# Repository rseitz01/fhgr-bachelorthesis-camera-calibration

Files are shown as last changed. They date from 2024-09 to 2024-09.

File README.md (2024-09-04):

# fhgr-bachelorthesis-camera-calibration

## Ordnerstruktur

- [`doc`](doc) Allgemeine Dokumentationen
- [`ledrunner`](ledrunner) Alles bezüglich STM32 (HW, SW, ...)
- [`src`](src) Source Codes (PC)

Die Veröffentlichung der Bachelorarbeit auf GitHub wurde durch den Dozenten und den Auftraggeber nach der Präsentation erlaubt.

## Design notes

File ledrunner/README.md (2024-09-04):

# ledrunner

## Ordnerstruktur

- [`housing-ledrunner`](housing-ledrunner) Komplettes Gehäuse für die Hardware
- [`hw-ledrunner`](hw-ledrunner) Schema + PCB der Hardware
- [`sw-camera-calibration`](sw-camera-calibration) STM32 Software (Prototyp der Kalibration)
- [`sw-ledrunner`](sw-ledrunner) STM32 Software zur Hardware

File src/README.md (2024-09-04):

# src

## Ordnerstruktur

- [`camera-control`](camera-control) Steuerung von ueye Kameras (Windows & Linux) + Ledrunner (nur Linux)
- [`eval-dynamic`](eval-dynamic) Auswertung der Videos (automatische Feld Erkennung)
- [`eval-static`](eval-static) Auswertung der Videos (Prototyp, manuelle Feld Einzeichnung)
- [`timer-estimator`](timer-estimator) Timer Estimation (Prototyp für [hier](../ledrunner/sw-ledrunner/Core/Src/timer_estimator.c))

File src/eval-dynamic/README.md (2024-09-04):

# eval-dynamic

## Beschreibung der Skripte

- [`calibrated.py`](calibrated.py) Visualisierung der kalibrierten Frequenzen
- [`calibrated_pwm.py`](calibrated_pwm.py) Formatierungshilfe für LaTeX der gemessenen PWM Frequenzen
- [`config.py`](config.py) Diverse allgemeine Konfigurations-Optionen für die Analyse + Auswertung
- [`debug.py`](debug.py) Debug-Optionen
- [`dynamic-conceptual.py`](dynamic-coneptual.py) Versuch, alles bis auf die automatische Positionserkennung zum Laufen zu bringen *(nicht mehr verwendet)*
- [`dynamic.py`](dynamic.py) Analyse-Programm
- [`image_sequence.py`](image_sequence.py) Speichern von Bildern und Positionserkennung des Gerätes
- [`plotter.py`](plotter.py) Auswertungs-Programm
- [`plotter_bad.py`](plotter_bad.py) Auswertungs-Programm; Erste Version *(nicht mehr verwendet)*
- [`position_sequence.py`](position_sequence.py) Speichern von Positionen und PWM-Kalibration

Wird `dynamic.py` auf ein Video angewendet, werden Messwerte in `measurements` gespeichert. 
Nach und nach werden gleichzeitig in `measurements/plotcommands.txt` äquivalente Python-Funktionsaufrufe
angefügt, welche in `plotter.py` verwendet werden können.

Wird `dynamic.py` nur auf einer Videodatei angewendet, wird bei Beenden direkt geplottet.
Es ist auch möglich, mehrere Videodateien zugleich abzuarbeiten.
Dann werden jedoch weniger Informationen ausgegeben und nicht geplottet.
(Die `measurements/plotcommands` werden in jedem Fall erstellt.)

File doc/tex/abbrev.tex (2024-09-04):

\begin{centering}
\begin{tabular}{ | ll | }
    \hline
    USB & Universal Serial Bus \\
    LED & Leuchtdiode \\
    PC & Personal Computer \\
    PWM & Pulsweitenmodulation \\
    PCB & Printed Circuit Board (Leiterplatine) \\
    QR-Code & quick-response code \\
    FPS & Bilder pro Sekunde (Frequenz) \\
    LSB & Least Significant Bit (Niederwertigstes Bit) \\
    \hline
\end{tabular}
\captionof{table}{Abkürzungsverzeichnis}
\label{table:Abkürzungsverzeichnis}
\end{centering}

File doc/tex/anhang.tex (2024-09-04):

%- Auflistung der Dokumente im Anhang
{
\let\ttdefault\rmdefault
\begin{longtable}[l]{ @{} >{\RaggedRight\hspace{0pt}} lp{.96\linewidth} @{} }
    \refstepcounter{enumi}\hypertarget{app:this}{\theenumi}.
    %& Bachelorarbeit
    & Kurzbeschreibung: Bachelorarbeit \LaTeX-Source Code
    \\& Ordner: \verb|doc/tex|
    \\& Datum und Zeit: 09.08.2024 09:40
    \vspace{0.5em}
    \\\refstepcounter{enumi}\hypertarget{app:expose}{\theenumi}.
    %& Exposé
    & Kurzbeschreibung: Originale Exposé Datei, PDFs (Exposé und Auftragsblatt)
    \\& Ordner: \verb|doc/expose|
    \\& Datum und Zeit: 09.08.2024 04:25
    \vspace{0.5em}
    \\\refstepcounter{enumi}\hypertarget{app:bilder}{\theenumi}.
    %& Bilder
    & Kurzbeschreibung: Diverse Bilder die verwendet sind in diesem Dokument
    \\& Ordner: \verb|doc/images|
    \\& Datum und Zeit: 09.08.2024 04:20
    \vspace{0.5em}
    \\\refstepcounter{enumi}\hypertarget{app:housing-ledrunner}{\theenumi}.
    %& Gehäuse der Hardware
    & Kurzbeschreibung: Gehäuse der Hardware
    \\& Ordner: \verb|ledrunner/housing-ledrunner|
    \\& Datum und Zeit: 08.08.2024 22:34
    \\& Programm: Fusion 360
    \vspace{0.5em}
    \\\refstepcounter{enumi}\hypertarget{app:hw-ledrunner}{\theenumi}.
    %& Gehäuse der Hardware
    & Kurzbeschreibung: Schema und PCB der Hardware
    \\& Ordner: \verb|ledrunner/hw-ledrunner|
    \\& Datum und Zeit: 09.08.2024 04:51
    \\& Entwicklungsumgebung: KiCad
    \vspace{0.5em}
    \\\refstepcounter{enumi}\hypertarget{app:sw-ledrunner}{\theenumi}.
    %& Gehäuse der Hardware
    & Kurzbeschreibung: STM32 Software der Hardware
    \\& Ordner: \verb|ledrunner/sw-ledrunner|
    \\& Datum und Zeit: 06.08.2024 12:44
    \\& Entwicklungsumgebung: STM32CubeIDE
    \vspace{0.5em}
    \\\refstepcounter{enumi}\hypertarget{app:sw-camera-calibration}{\theenumi}.
    %& Gehäuse der Hardware
    & Kurzbeschreibung: STM32 Software der Machbarkeitsanalyse für die Kalibration
    \\& Ordner: \verb|ledrunner/sw-camera-calibration|
    \\& Datum und Zeit: 06.08.2024 12:44
    \\& Entwicklungsumgebung: STM32CubeIDE
    \vspace{0.5em}
    \\\refstepcounter{enumi}\hypertarget{app:camera-calibration}{\theenumi}.
    %& Gehäuse der Hardware
    & Kurzbeschreibung: Auswertesoftware der Machbarkeitsanalyse für die Kalibration
    \\& Ordner: \verb|src/camera-calibration|
    \\& Datum und Zeit: 08.08.2024 12:05
    \\& Programmiersprache: C/C++
    \vspace{0.5em}
    \\\refstepcounter{enumi}\hypertarget{app:camera-control}{\theenumi}.
    %& Gehäuse der Hardware
    & Kurzbeschreibung: Beispielsoftware zur Steuerung einer Kamera und des Kalibrationsgerätes
    \\& Ordner: \verb|src/camera-control|
    \\& Datum und Zeit: 08.08.2024 12:05
    \\& Programmiersprache: C/C++
    \vspace{0.5em}
    \\\refstepcounter{enumi}\hypertarget{app:eval-dynamic}{\theenumi}.
    %& Gehäuse der Hardware
    & Kurzbeschreibung: Evaluationssoftware der gefilmten Videos (automatische Positionsdetektion)
    \\& Ordner: \verb|src/eval-dynamic|
    \\& Datum und Zeit: 09.08.2024 05:59
    \\& Programmiersprache: Python
    \vspace{0.5em}
    \\\refstepcounter{enumi}\hypertarget{app:eval-static}{\theenumi}.
    %& Gehäuse der Hardware
    & Kurzbeschreibung: Evaluationssoftware der gefilmten Videos (Prototyp, manuelle Positionseinzeichnung)
    \\& Ordner: \verb|src/eval-static|
    \\& Datum und Zeit: 24.05.2024 10:23
    \\& Programmiersprache: Python
    \vspace{0.5em}
    \\\refstepcounter{enumi}\hypertarget{app:measurements}{\theenumi}.
    %& Gehäuse der Hardware
    & Kurzbeschreibung: Oszilloskop Messresultate
    \\& Ordner: \verb|doc/measurements|
    \\& Datum und Zeit: 09.08.2024 06:22
    \vspace{0.5em}
    \\\refstepcounter{enumi}\hypertarget{app:results}{\theenumi}.
    %& Gehäuse der Hardware
    & Kurzbeschreibung: Resultate
    \\& Ordner: \verb|doc/results|
    \\& \begin{tabular}{ @{} >{\RaggedRight\hspace{0pt}} ll @{} }
            Inhalt:
              &\refstepcounter{enumii}\hypertarget{hyp:k-ueye-29-85}{\theenumii)} \verb|30fps-4999us-at-29.85fps-*.png|%
            \\&\refstepcounter{enumii}\hypertarget{hyp:k-ueye-59}{\theenumii)} \verb|59-99fps-4999us-at-59fps-*.png|%
            \\&\refstepcounter{enumii}\hypertarget{hyp:k-ueye-59-7}{\theenumii)} \verb|59-99fps-4999us-at-59-700699fps-*.png|%
            \\&\refstepcounter{enumii}\hypertarget{hyp:k-ueye-60-3}{\theenumii)} \verb|59-99fps-4999us-at-60-299084fps-*.png|%
            \\&\refstepcounter{enumii}\hypertarget{hyp:k-ueye-61}{\theenumii)} \verb|59-99fps-4999us-at-61fps-*.png|%
            \\&\refstepcounter{enumii}\hypertarget{hyp:k-aos-60}{\theenumii)} \verb|60fps-5000us-22k-*.png|%
            \\&\refstepcounter{enumii}\hypertarget{hyp:k-aos-285}{\theenumii)} \verb|285fps-2055us-22k_002-*.png|%
            \\&\refstepcounter{enumii}\hypertarget{hyp:k-aos-752}{\theenumii)} \verb|752fps-600us-*.png|%

            \\&\refstepcounter{enumii}\hypertarget{hyp:b-ueye-40}{\theenumii)} \verb|59-99fps-4999us-at-40-000000fps-*.png|%
            \\&\refstepcounter{enumii}\hypertarget{hyp:b-ueye-50}{\theenumii)} \verb|59-99fps-4999us-at-50.000000fps-*.png|%
            \\&\refstepcounter{enumii}\hypertarget{hyp:b-ueye-56-25}{\theenumii)} \verb|59-99fps-4999us-at-56-250000fps-*.png|%
            \\&\refstepcounter{enumii}\hypertarget{hyp:b-ueye-60}{\theenumii)} \verb|59-99fps-4999us-at-60fps-*.png|%
            \\&\refstepcounter{enumii}\hypertarget{hyp:b-ueye-64-29}{\theenumii)} \verb|59-99fps-4999us-at-64-285713fps-*.png|%
            \\&\refstepcounter{enumii}\hypertarget{hyp:b-ueye-75}{\theenumii)} \verb|59-99fps-4999us-at-75-000000fps-*.png|%
            \\&\refstepcounter{enumii}\hypertarget{hyp:b-ueye-120}{\theenumii)} \verb|59-99fps-4999us-at-120-000000fps-*.png|%

            \\&\refstepcounter{enumii}\hypertarget{hyp:k-ueye-59-7-blur}{\theenumii)} \verb|59-99fps-4999us-at-59-700699fps-blurry-*.png|%
            \\&\refstepcounter{enumii}\hypertarget{hyp:b-a52-59-7-rolling}{\theenumii)} \verb|60fps-at-59.700699fps-rolling-*.png|%

            \setcounter{enumii}{0}
        \end{tabular}
    \\& Datum und Zeit: 09.08.2024 04:34
    \vspace{0.5em}
    % ENDE
    %%%%%%%%%%%%%%%%%%%%%%%%%%%%%%%%%%%%%%%%%%%%%%%%%%%%%%%%%%%%%%%%%%%%%%%%%%%%%%%%%%%%
    \addtocounter{table}{-1}
    \setcounter{enumi}{0}
\end{longtable}
}

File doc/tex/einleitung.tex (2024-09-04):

% INHALT: {{{

% Aufgabenstellung ...
% Begründung des Themas ...
% und Ziele formulieren

% Das Thema wird abgegrenzt,
% die relevanten Arbeiten anderer Autoren werden zitiert,
% und eventuell werden fachliche Grundlagen, welche für das Verständnis des Berichtes nötig sind, erläutert.
% In diesem ersten Abschnitt soll demnach klargemacht werden, worauf der Autor/die Au- torin hinaus will.

%}}}

\subsection{Begründung des Themas} %{{{

Viele Computervision-Anwendungen, welche Einzel- und Mehrkamerasysteme verwenden, sind auf ein korrektes Timing der aufgenommenen Bilder angewiesen.
Dabei gehen die Bilder von der Kamerahardware über den Übertragungsweg zum Auswertesystem (USB (Universal Serial Bus), Ethernet, WiFi, ...) und durch verschiedene Treiberschichten bis in die Anwendung einen langen Weg.
Zwar bieten die Hersteller manchmal einen Zeitstempel für jedes aufgenommene Bild.
Trotzdem wäre ein automatisches Messgerät praktisch, mit dem das Zeitverhalten der Aufnahmen (z.B. Bilder pro Sekunde, Jitter) oder die Synchronität von Mehrkamerasystemen bestimmt werden können.

% END: Begründung des Themas }}}

\subsection{Aufgabenstellung} %{{{

Das Messsystem wird als Elektronik ausgelegt, welche mehrere LEDs (Leuchtdioden) zur Anzeige hat.
Die Kamera schaut auf die LEDs und nimmt diese auf.
Das Messsystem verändert die LEDs zeitabhängig und kodiert einen Zeitstempel in die Zustände der LEDs.
Mittels einer Software sollte man anhand der von der Kamera aufgenommenen Bilder die Zeitstempel rekonstruieren können und mit diesen das Zeitverhalten der Kamera analysieren können.

Das Messsystem sollte sich per USB mit einem PC (Personal Computer) verbinden lassen und von diesem per serielle Schnittstelle konfigurieren lassen (z.B. Messfrequenz).
Es wäre auch gut, wenn das Messsystem einen Triggerausgang und Triggereingang hätte mit dem sich Kameras oder das Messsystem selbst triggern lassen.

% END: Aufgabenstellung }}}

\subsection{Ziele} %{{{

\begin{longtable}[l]{ @{} >{\RaggedRight\hspace{0pt}} lp{.96\linewidth} @{} }
    \textbullet & Mit welcher Anordnung, bzw. Ansteuerung der LEDs kann geschickt Zeit kodiert und detektiert werden?
    \\\textbullet & Welche Kamerafehler und Aufnahmeeigenschaften können detektiert werden?
    \\\textbullet & Wie grob weichen die vom Hersteller versprochenen Aufnahmeeigenschaften ab?
    \\\textbullet & Welche Einflüsse hat eine variierende Bildqualität?
    \addtocounter{table}{-1}
\end{longtable}

%}}}

\subsection{Systemabgrenzung} %{{{

Als erstes wurde eine Systemabgrenzung erstellt, welche in \imgref{img:Systemabgrenzung} zu sehen ist.

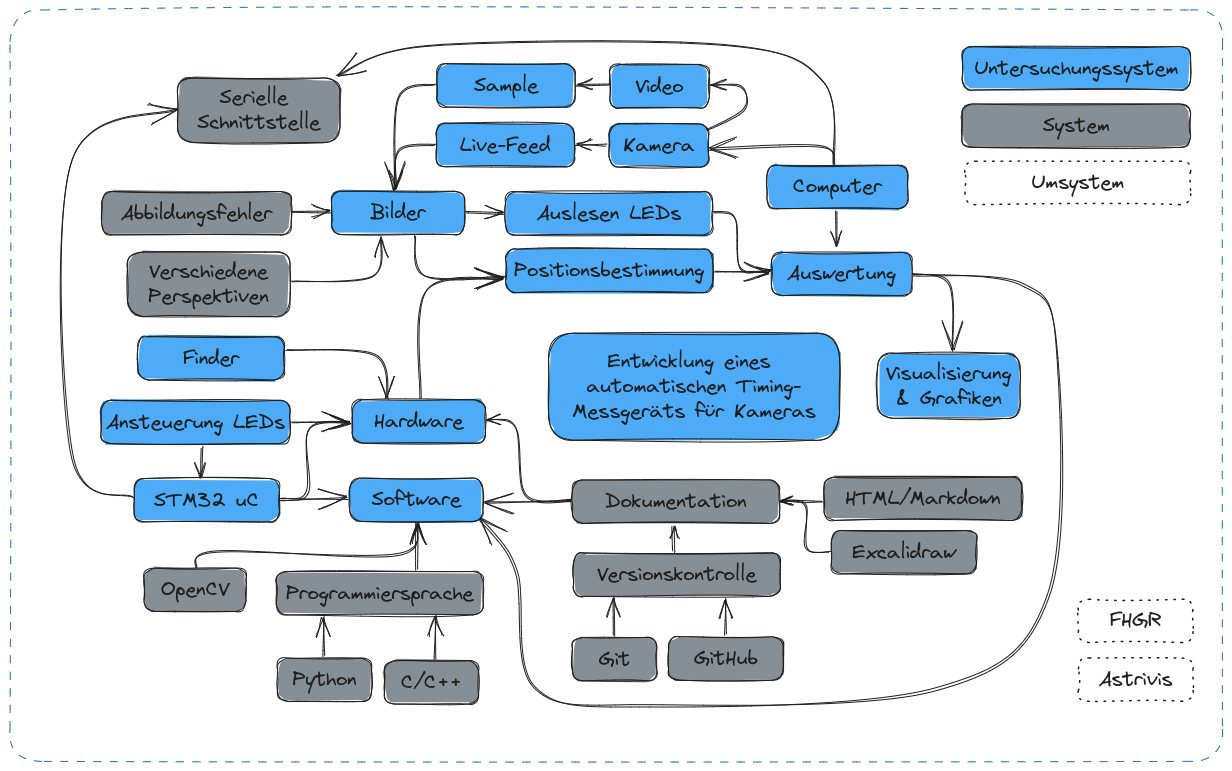
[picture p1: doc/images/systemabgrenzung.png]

\vspace{-2.5em}
\captionof{figure}{Systemabgrenzung}
\label{img:Systemabgrenzung}

% END: Systemabgrenzung }}}

\subsection{Relevante Arbeiten} %{{{

Zeitstempel können als Gray-Codes codiert werden.
%
Zur Decodierung und Analyse einer Kamera wird jedoch eine zusätzliche externe Kamera verwendet, die das System von Aussen beobachtet \cite{7836493}.

Die Position, inspiriert durch Data Matrizen \cite{data-matrix}, wird anhand der Anordnung der LEDs bestimmt.

% END: Relevante Arbeiten }}}

\subsection{Fachliche Grundlagen} %{{{

\subsubsection{Pulsweitenmodulation} %{{{

Die Helligkeit einer LED kann durch Variation der Eingangsleistung verändert werden.
%
Oft kann eine LED jedoch nur ein- oder ausgeschalten werden, welches eine Änderung der Helligkeit durch ändern der Stromstärke schwierig gestaltet.
%
Die Eingangsleistung wird demnach über die Zeit durch PWM (Pulsweitenmodulation) des digitalen Ansteuerungssignales kontrolliert reguliert.

Ein Beispiel:
%
Wenn eine LED wiederholend innert kurzer Zeit 25\% an und den Rest der Zeit aus ist, sieht es für einen Betrachter so aus, als leuchte die LED mit einem viertel der vollen Intensität.
%
Dies nennt sich auch 25\% Duty Cycle.

%}}}

\subsubsection{Timer im Mikrokontroller} %{{{

Die Aufgabe eines Timers in einem Mikrokontroller ist das Zählen auf eine bestimmte Zahl.
%
Vorgegeben ist auch die Eingangsgeschwindigkeit und ein Prescaler, welcher die Eingangsgeschwindigkeit dividiert und so die Zählergeschwindigkeit vorgibt.
%
Durch zurücksetzen des Zählers beim Erreichen des Zielwertes wird fortlaufend gezählt.

Der Zeitpunkt beim Erreichen der vorgegebenen Zahl kann somit als variable Frequenzgeneration eingesetzt werden.
%
In \eqref{eq:f_Timer} sind $z_\text{ARR}, z_\text{PSC} \in \mathbb{N}$ die Werte vom Auto-Reload- \& Prescaler-Register.
%
Die Eingangsfrequenz ist durch $f_\text{Eingang}$ gegeben und die resultierende variable Ausgangsfrequenz ist $f_\text{Timer}$.

\begin{equation}\label{eq:f_Timer}
    f_\text{Timer} = \frac{ f_\text{Eingang} }{ \left( z_\text{ARR} + 1 \right) \cdot \left( z_\text{PSC} + 1 \right) }
\end{equation}

\subsubsection{Rolling und Global Shutter}

Das Auslesen der Pixel einer Kamera wird unterschieden zwischen Rolling und Global Shutter.
Beim Global Shutter werden alle Pixelwerte gleichzeitig ausgelesen.
Anders ist dies beim Rolling Shutter, wo zeilenweise Pixelwerte ausgelesen werden \cite{rolling-global}.
%Wobei dies Zeilenweise geschieht beim Rolling Shutter \cite{rolling-global}.

%}}}

% TODO: schieberegister vlt noch hinzufügen?

% END: Fachliche Grundlagen }}}

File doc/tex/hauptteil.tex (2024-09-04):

% INHALT: {{{
% Material und Methoden:
% - technische Ausrüstung, Rechen-, Messmethoden, Auswerteverfahren etc., die in der Arbeit verwendet wurden
% Ergebnisse bzw. Resultate:
% - Beschreibung bzw. Darstellung der erzielten Ergebnisse
% }}}

\subsection{Material und Methoden}

\subsubsection{Technische Ausrüstung \& Verwendete Tools} %{{{

Alles was verwendet wurde ist in \tabref{table:Tools} aufgelistet.

\begin{center}
    \begin{tabular}{ | >{\RaggedRight\hspace{0pt}} l|l | }
        \hline
        \textbf{Programme} & \\
        KiCAD \cite{kicad}                  & Schema- \& Leiterplatten-Designer \\
        STM32CubeIDE \cite{stm32cube}       & Programmierumgebung von ST \\
        Fusion 360 \cite{fusion}            & 3D-Konstruktions-Software \\
        Prusa Slicer \cite{prusa-slicer}    & Preparation von Objekten zum 3D-Druck \\
        LibreOffice \cite{libreoffice}      & Präsentationen (Exposé) \\
        MobaXTerm \cite{mobaxterm}          & Kommunikation über serielle Schnittstellen \\
        Excalidraw \cite{excalidraw}        & Diagramme \\
        Python \cite{python}                & Programmiersprache \\
        C/C++ \cite{cpp}                    & Programmiersprache \\
        \hline
        \textbf{Programmier-Bibliotheken}   & \\
        opencv \cite{opencv}                & Bildverarbeitungs-Bibliothek \\
        numpy \cite{numpy}                  & Numerische Rechenbibliothek \\
        matplotlib \cite{mpl}               & Bibliothek zum grafischen darstellen von Daten \\
        scipy \cite{scipy}                  & Algorithmen für Wissenschaftliches Rechnen \\
        \hline
        \textbf{Allgemeines} & \\
        vim \cite{vim}, neovim \cite{neovim}        & Text- \& Code-Editor \\
        git \cite{git}, GitHub \cite{github}        & Versionierungs-Software \& Datenbank \\
        Linux \cite{linux}, Windows \cite{windows}  & Betriebssystem \\
        \hline
        \textbf{Hardware} & \\
        Keysight MSOX3024T \cite{voltcraft} & Oszilloskop \\
        \hypertarget{hyp:Prusa-MK4}{Prusa MK4} \cite{prusa-mk4} & 3D-Drucker \\
        \hypertarget{hyp:IDS}{IDS} UI-3250CP-M-GL \cite{ids} & Kamera \\
        \hypertarget{hyp:AOS}{AOS} U750 COLOR \cite{aos} & Kamera \\
        Samsung Galaxy \hypertarget{hyp:A52}{A52} \cite{a52} & Kamera \\
        \hline
    \end{tabular}
    \captionof{table}{Technische Ausrüstung \& Verwendete Tools}
    \label{table:Tools}
\end{center}

\subsubsection{Entwicklungsprozess der Hardware}

Die Hardware wurde iterativ entwickelt.
Zu Beginn wurde das Schieberegister auf einem Steckbrett ausgetestet.
Danach konnte ein Schema und Layout im KiCad gezeichnet werden, welches dann von JLCPCB \cite{jlc} hergestellt wurde.
Bauteile wurden entweder von der Schule bezogen oder von DigiKey \cite{digikey} bestellt.
In der ersten PCB (Printed Circuit Board) Version war noch kein Kommunikationsport vorhanden, es hatte noch keinen externen Oszillator und noch diverse Speisungsfehler für den Mikrokontroller.
In der zweiten Version wurde dies behoben. Dennoch hat es noch einen kleinen Fehler, der Ausgebessert werden musste, damit die USB-Kommunikation einwandfrei funktioniert.
Die im \appref{app:hw-ledrunner} beigelegte Version enthält alle Verbesserungen.

\subsubsection{Entwicklungsprozess der Software}

Die Software wurde ebenfalls iterativ entwickelt \cite{stackoverflow,stackexchange,mathexchange,geeks}.
Zuerst entstand die Auswertung für eine LED-Helligkeitskalibration (\appref{app:camera-calibration}), der \secref{sec:Machbarkeitsanalyse-der-Kalibration} geht näher darauf ein.
Danach entstand eine Version, in der noch keine Kalibration durchgeführt wurde und die Position des Gerätes von Hand eingezeichnet werden musste (\appref{app:eval-static}).
Darin befindet sich der erste Ansatz zur Auswertung eines Messvideos.
In der aktuellen Version der Auswertungssoftware (\appref{app:eval-dynamic}) wurden die beiden Teile zusammengeführt.
Damit erfolgt die Auswertung nun vollautomatisch, denn das Messgerät wird gefunden, und ebenso eine Helligkeitskalibration durchgeführt.

Für den ersten Teil ist die Mikrokontroller-Software im \appref{app:sw-camera-calibration} erstellt worden.
Danach wurde eine separate Version kontinuierlich erweitert in \appref{app:sw-ledrunner}.
Dies ist gleichzeitig die aktuelle Version.

\subsubsection{Entwicklungsprozess des Gehäuses}

Das Gehäuse wurde, wie auch die Hardware und Software, iterativ entwickelt.
Die ersten paar Versionen hatten zu kleine Toleranzen und es schlichen sich Logikfehler ein.
Die aktuelle Version im \appref{app:housing-ledrunner} passte schlussendlich.
Der \hyperlinkXY{hyp:Prusa-MK4} wurde verwendet um dies physikalisch zu erstellen.

% END: Verwendete Tools }}}

\subsection{Kalibrationsgerät} %{{{

Ein Kalibrationsgerät wurde entwickelt, welches die Auswerteverfahren in \secref{sec:Auswerteverfahren} ermöglicht.

\subsubsection{Blockschaltbild}

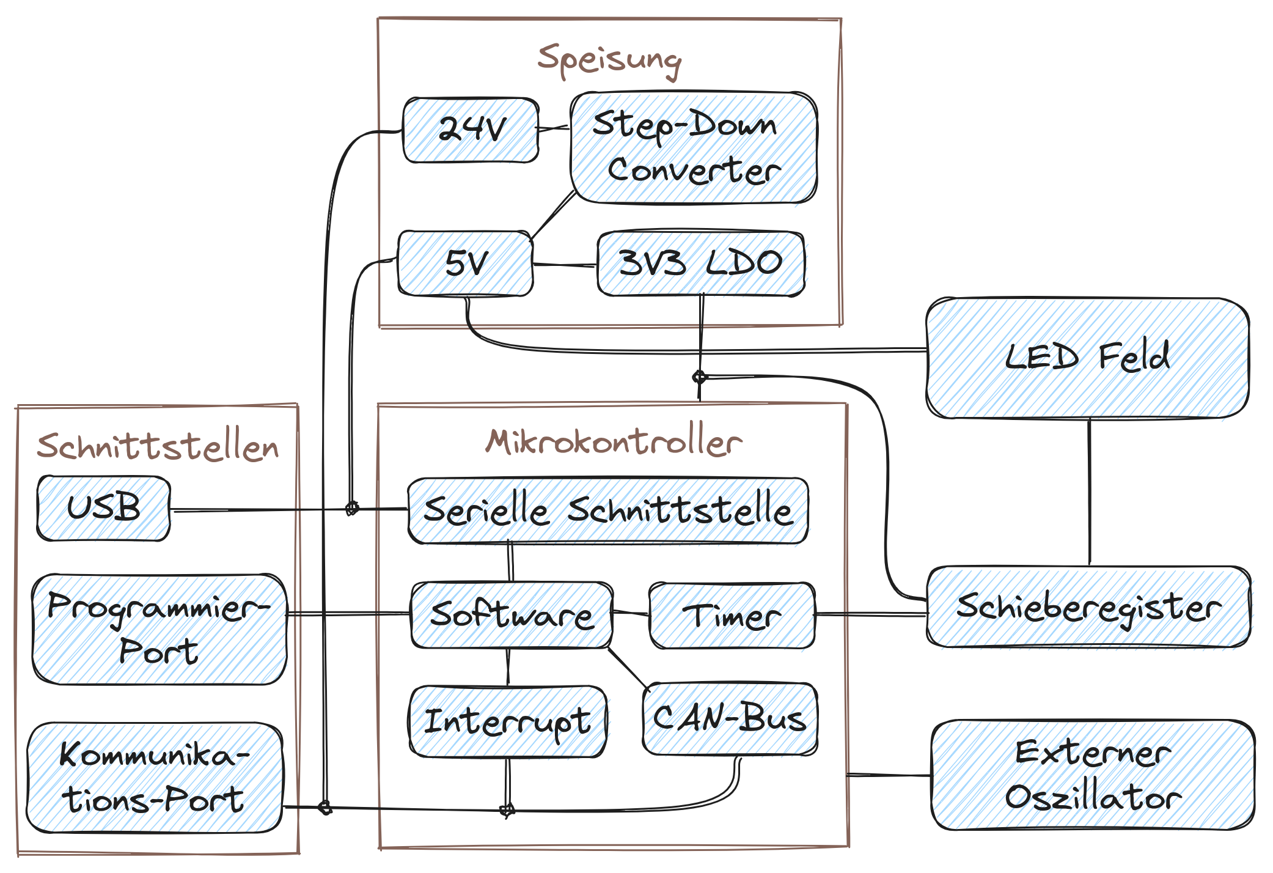
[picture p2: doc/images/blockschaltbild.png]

\vspace{-3em}
\captionof{figure}{Blockschaltbild}
\vspace{0.5em}
\label{img:Blockschaltbild}

Diverse Punkte von \imgref{img:Blockschaltbild} genauer betrachtet:
%\tablevspaceASenum
\begin{longtable}[l]{ @{} >{\RaggedRight\hspace{0pt}} lp{.96\linewidth} @{} }
    \textbullet & Für den Mikrokontroller ist ein STM32 mit einer Taktgeschwindigkeit von 72MHz vorgesehen.
    \\\textbullet & Das Schieberegister fungiert auch direkt als Stromtreiber für die LEDs. Die maximale Taktgeschwindigkeit dessen beträgt 30MHz.
    \\\textbullet & Kommunikation mit dem PC geschieht über den USB-Port per serieller Schnittstelle.
    \\\textbullet & Kommunikation mit anderen Kalibrationsgeräten geschieht über den Kommunikations-Port per CAN-Bus \textit{(noch nicht implementiert)}. Ein Interrupt soll auf eine konfigurierbare Aktion belegt werden können, zum Beispiel als externer Trigger \textit{(aktuell nur belegbar auf den \hyperlinkXY{hyp:mode-auto} Modus)}.
    \\\textbullet & Es ist möglich das Gerät über USB oder eine 24V-Speisung zu betreiben.
    \\\textbullet & Um eine möglichst genaue Taktrate zu erzielen wird ein externer Oszillator verwendet.
    \addtocounter{table}{-1}\setcounter{enumi}{0}
\end{longtable}
\tablevspaceASenum

\subsubsection{Hard- \& Software}

Alles bezüglich der Hardware (Schema und Layout) ist im \appref{app:hw-ledrunner}.
Das PCB ist in \imgref{img:PCB} gezeigt und beschrieben.
Das Gehäuse ist im \appref{app:housing-ledrunner}.
Die gesamte Software des Messgeräts ist im \appref{app:sw-ledrunner}.

\vspace{1em}
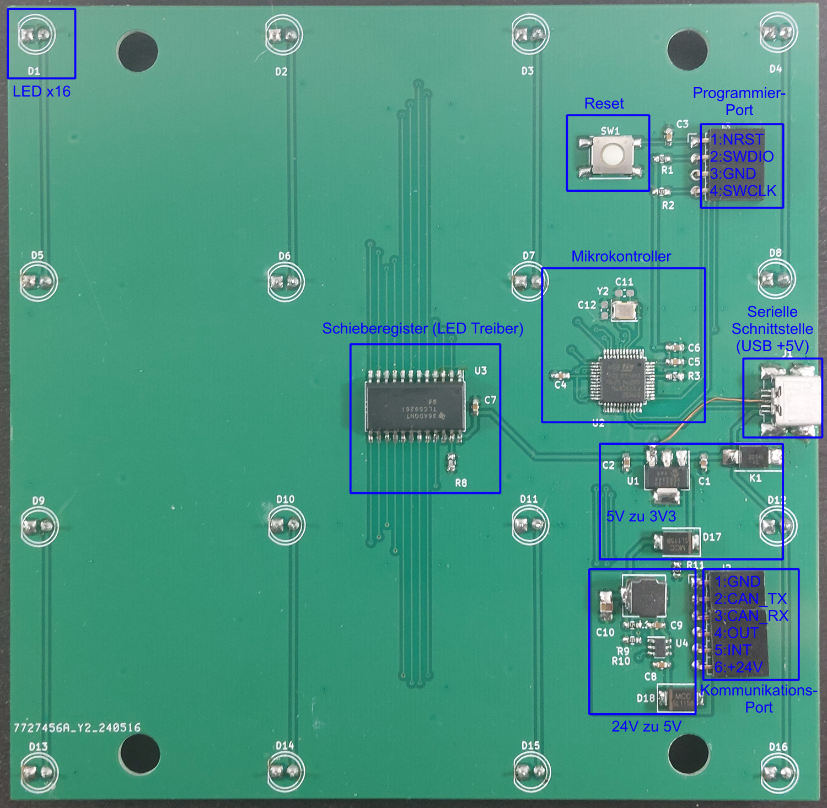
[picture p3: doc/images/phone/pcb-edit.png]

\vspace{-2.5em}
\captionof{figure}{PCB}
\label{img:PCB}

\subsubsection{Anordnung der Leuchtdioden}

Verschiedene grössen von quatratischen Anordnungen wurden in Betracht gezogen.
%
Der grösste Einfliessende Faktor ist jedoch die Anzahl an Ausgängen vom Schieberegister.
%
Das ausgesuchte Schieberegister besitzt 16 Ausgänge.
%
Somit kann passend ein Feld bestehend aus 4x4, also insgesamt 16 LEDs, aufgebaut werden.

\subsubsection{Kodierung der Zeit}

Die erste Idee war, dass ein Zeitstempel, ähnlich wie bei QR-Codes (quick-response code) oder Data-Matrizen, angezeigt wird.
%
Dies müsste dann mit der Frequenz abgestimmt werden und es hätte in jedem Bild einen unverwechselbaren Zeitstempel.
%
Kompliziert wird es jedoch, wenn die Kamera durch die Belichtungszeit mehrere Zeitstempel ineinenader verwischen lässt.

Der zweite und ausgewählte Ansatz ist das ``wandern'' lassen einer LED.
%
Es soll also zu jedem Zeitpunkt immer nur eine LED leuchten.
%
Die Geschwindigkeit der ``Wanderung'' wird abgestimmt auf die Aufnahmefrequenz, so dass einmal das gesamte Feld innerhalb von einer zur nächsten Bildaufnahme besucht wird (siehe \secref{sec:Gut-Eingestellt}).
%
Damit lässt sich in der Video-Analyse anhand von Änderungen in der Position der LEDs die Stabilität ausfindig machen.
%
Durch die Anzahl an leuchtenden LEDs im Messvideo lässt sich die Belichtungszeit ermitteln.

\subsubsection{Infobefehle}

Über die serielle Schnittstelle sind die Infobefehle aus \tabref{table:Liste-der-Infobefehle} zur Verfügung gestellt.

\tablevspaceAStable
\begin{tabular}{ @{} >{\RaggedRight\hspace{0pt}} ll @{} }
    Befehl & Zweck \\
    \hline
    \texttt{info} & Auflistung aller Infobefehle \textit{(dies ist als Hilfestellung gegeben)} \\
    \texttt{info version} & Ausgabe der aktuellen Version \\
    \texttt{info arr} & Ausgabe der \hyperlinkXY{hyp:config-arr} Konfiguration \\
    \texttt{info psc} & Ausgabe der \hyperlinkXY{hyp:config-psc} Konfiguration \\
    \texttt{info fps} & Ausgabe der \hyperlinkXY{hyp:config-fps} Konfiguration \\
    \texttt{info out} & Ausgabe der \hyperlinkXY{hyp:config-out} Konfiguration \\
    \texttt{info int} & Ausgabe der \hyperlinkXY{hyp:config-int} Konfiguration \\
    \texttt{info all} & Informationen von allem anzeigen \\
\end{tabular}
\captionof{table}{Liste der Infobefehle}
\label{table:Liste-der-Infobefehle}

\subsubsection{Konfigurationsmöglichkeiten}

Über die serielle Schnittstelle sind die Konfigurationsbefehle aus \tabref{table:Ansteuerung-der-Konfiguration} zur Verfügung gestellt.

\tablevspaceAStable
\begin{tabular}{ @{} >{\RaggedRight\hspace{0pt}} ll @{} }
    Befehl & Zweck \\
    \hline
    \texttt{config} & Auflistung der Konfigurationsbefehle \textit{(dies ist als Hilfestellung gegeben)} \\
    \texttt{config }\hypertarget{hyp:config-fps}{\texttt{fps}}\texttt{=ZAHL} & Setzen der Schaltfrequenz einer einzelnen LED im \hyperlinkXY{hyp:mode-rider} Modus \\
    \texttt{config }\hypertarget{hyp:config-arr}{\texttt{arr}}\texttt{=ZAHL} & Manuelles einstellen vom Auto-Reload des Timers \\
    \texttt{config }\hypertarget{hyp:config-psc}{\texttt{psc}}\texttt{=ZAHL} & Manuelles einstellen vom Prescaler des Timers \\
    \texttt{config }\hypertarget{hyp:config-int}{\texttt{int}}\texttt{=on/off} & Ein- oder ausschalten des GPIO Interrupts zum Start vom \hyperlinkXY{hyp:mode-auto} Modus \\
    \texttt{config }\hypertarget{hyp:config-out}{\texttt{out}}\texttt{=on/off} & Ein- oder ausschalten des GPIO Ausgangs beim Start vom \hyperlinkXY{hyp:mode-auto} Modus \\
    \texttt{config }\hypertarget{hyp:config-reset}{\texttt{reset}} & Reset auslösen \\
\end{tabular}
\captionof{table}{Ansteuerung der Konfiguration}
\label{table:Ansteuerung-der-Konfiguration}

\tablevspaceASenum
\begin{longtable}[l]{ @{} >{\RaggedRight\hspace{0pt}} lp{.96\linewidth} @{} }
    \textbullet & Die \hyperlinkXY{hyp:config-fps} Konfiguration versucht möglichst nahe an die gewünschte FPS (Bilder pro Sekunde) heranzukommen und setzt den Auto-Reload und Prescaler automatisch.
    \\\textbullet & Wird \hyperlinkXY{hyp:config-arr} oder \hyperlinkXY{hyp:config-psc} verändert, aktualisiert dies die \hyperlinkXY{hyp:config-fps} gemäss \eqref{eq:f_Timer}.
  \addtocounter{table}{-1}\\
\end{longtable}
\tablevspaceASenum

\subsubsection{Modi}\label{sec:Modi}

Das Gerät kann in verschiedene Modi gesetzt werden, die alle einen bestimmten Zweck erfüllen, welche in \tabref{table:Ansteuerung-der-Modi} aufgelistet sind.

\tablevspaceAStable
\begin{tabular}{ @{} >{\RaggedRight\hspace{0pt}} ll @{} }
    Befehl & Zweck \\
    \hline
    \texttt{mode} & Auflistung der Modi \textit{(dies ist als Hilfestellung gegeben)} \\
    \texttt{mode }\hypertarget{hyp:mode-none}{\texttt{none}} & Alle LEDs aus \\
    \texttt{mode }\hypertarget{hyp:mode-pwm}{\texttt{pwm}}\texttt{=ZAHL} & Alle LEDs über PWM ansteuern \\
    \texttt{mode }\hypertarget{hyp:mode-display}{\texttt{display}}\texttt{=BINÄRZAHL} & Eine Zahl anzeigen \\
    \texttt{mode }\hypertarget{hyp:mode-rider}{\texttt{rider}} & Eine LED wandern lassen \\
    \texttt{mode }\hypertarget{hyp:mode-auto}{\texttt{auto}} & Automatisches abspielen der Modi (siehe \secref{sec:Reihenfolge-der-Modi}) \\
\end{tabular}
\captionof{table}{Ansteuerung der Modi}
\label{table:Ansteuerung-der-Modi}

\tablevspaceASenum
\begin{longtable}[l]{ @{} >{\RaggedRight\hspace{0pt}} lp{.96\linewidth} @{} }
    \textbullet & Im \hyperlinkXY{hyp:mode-pwm} Modus kann eine Zahl zwischen 0 bis und mit 16 angegeben werden. Somit gibt dies 17 Stufen (siehe \secref{sec:PWM-Modus}). \\
    \textbullet & Im \hyperlinkXY{hyp:mode-display} Modus muss mindestens eine 16-stellige Binärzahl angegeben werden, bei der jedes Bit einer LED entspricht. Alles nach 16 Bits wird ignoriert. Beispiel: \texttt{mode display=1010010111110000}.
    \addtocounter{table}{-1}\\
\end{longtable}
\tablevspaceASenum

%}}}

\subsection{Rechenmethoden} %{{{

Aus den aktiven Leuchtdioden können zwei grundlegende Informationen extrahiert werden:

\tablevspaceASenum
\begin{tabular}{ @{} >{\RaggedRight\hspace{0pt}} lll @{} }
    \refstepcounter{enumi}\theenumi. & Bildwiederholrate & Zentrum der aktiven Leuchtdioden, siehe \secref{sec:Zentrum-def-laufenden-Leuchtdiode}
    \\\refstepcounter{enumi}\theenumi. & Belichtungszeit & Breite der aktiven Leuchtdioden, siehe \secref{sec:Breite-der-laufenden-Leuchtdiode}
\end{tabular}
\tablevspaceASenum

Da die Auswertung über mehrere Bilder geschieht, kann über die Stabilität der Bildwiederholrate und der Belichtungszeit beurteilt werden \textit{(Jitter)}.

%}}}

\subsection{Messmethoden} %{{{

\subsubsection{Machbarkeitsanalyse der Kalibration}\label{sec:Machbarkeitsanalyse-der-Kalibration}

    Zu Beginn war unbekannt, ob es Sinn machen würde, die Helligkeiten der LEDs zu kalibrieren, und ob dies überhaupt funktioniert.
    Deshalb wurden auf einer LED eines STM32 Nucleo Boards verschiedene Helligkeitsstufen mittels PWM eingestellt. Eine Kamera nahm Bilder davon auf und die Helligkeiten wurden ausgewertet.

    In \imgref{img:PWM-Machbarkeitsanalyse} sind die Verläufe, nebst einer Ideallinie, eingezeichnet.
    Es ist ersichtlich, dass eine Helligkeits, bzw. PWM-Kalibration potentiellen nichtlinearitäten entgegenwirken könnte.
    Es kommt ebenso darauf an, wie gross die auszuwertende Fläche in Pixel ist, welche in \imgref{img:PWM-Machbarkeitsanalyse-Flächen} dargestellt ist.
    Die weissen Pixel in der Mitte sind Teil der leuchtende LED.

    Der Source-Code für den Mikrokontroller ist im \appref{app:sw-camera-calibration} und die Auswertesoftware im \appref{app:camera-calibration} zu finden.

\noindent\begin{minipage}[t]{.497\linewidth}\vspace{0pt}

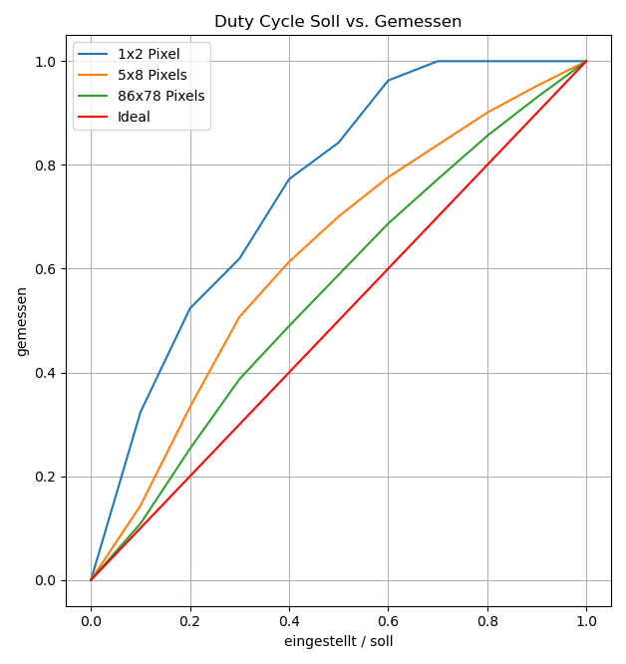
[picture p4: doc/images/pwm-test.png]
    
    \vspace{-2.5em}
    \captionof{figure}{PWM Machbarkeitsanalyse}
    \label{img:PWM-Machbarkeitsanalyse}

\end{minipage}
\noindent\begin{minipage}[t]{.497\linewidth}\vspace{0pt}

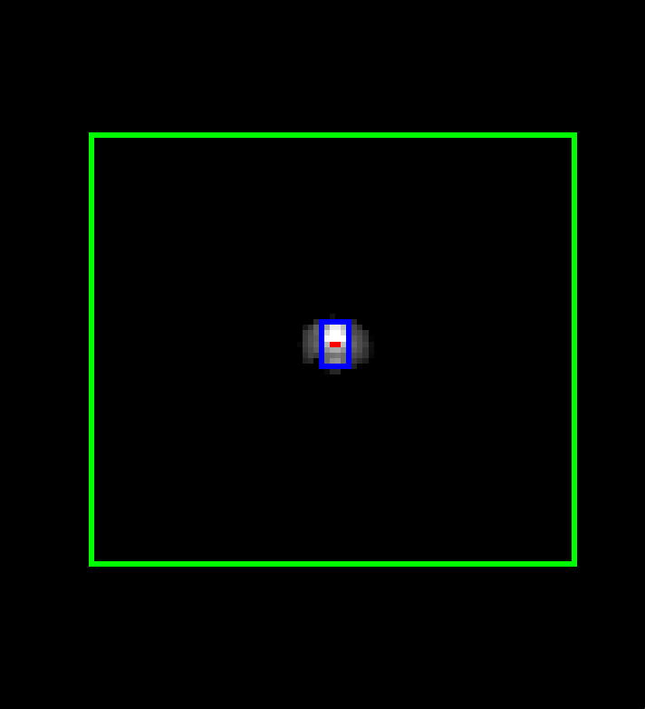
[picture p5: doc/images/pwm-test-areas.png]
    
    \vspace{-2.5em}
    \captionof{figure}{PWM Machbarkeitsanalyse (Ausgewertete Flächen)}
    \label{img:PWM-Machbarkeitsanalyse-Flächen}

\end{minipage}

\subsubsection{Überprüfung von Frequenzen}\label{sec:Überprüfung-von-Frequenzen}

% TODO: link oszi
Um die Frequenzen des Messgerätes zu überprüfen wurde ein Oszilloskop verwendet.
Eine Sonde misst direkt an einer LED wie in \imgref{img:Messpunkt-LED} gezeigt,
dessen Ground wie in \imgref{img:Messpunkt-GND} verbunden ist.

\noindent\begin{minipage}[t]{.497\linewidth}\vspace{0pt}
    \begin{centering}
        
        \vspace{-2.5em}
        \captionof{figure}{Messpunkt LED}
        \label{img:Messpunkt-LED}
    \end{centering}
\end{minipage}
\noindent\begin{minipage}[t]{.497\linewidth}\vspace{0pt}
    \begin{centering}
        
        \vspace{-2.5em}
        \captionof{figure}{Messpunkt Ground}
        \label{img:Messpunkt-GND}
    \end{centering}
\end{minipage}

\subsubsection{Aufnahme Video}

Diverse Messvideos in verschiedensten Anordnungen können aufgenommen werden.
Bei allen folgenden Messaufbauten ist die automatische Positionserkennung und Auswertung möglich.

Zum Beginn werden alle LEDs ausgeschaltet über den \hyperlinkXY{hyp:mode-none} Modus und die Zielfrequenz des Messgeräts über die Konfiguration \hyperlinkXY{hyp:config-fps} eingestellt.
Danach wird die Aufnahme und der \hyperlinkXY{hyp:mode-auto} Modus gestartet.
Die Kamera und das Messgerät werden während der gesamten Aufnahmezeit nicht verschoben.
Ausserdem sollte sich die Umgebungshelligkeit so wenig wie möglich ändern, damit die Zuverlässigkeit der Ergebnisse erhöht werden kann.

Zur optimalen Objektiveinstellung und Überprüfung, ob das gesamte LED-Feld im Video sichtbar ist,
empfiehlt es sich alle LEDs vor der obig beschriebenen Aufnahme leuchten lassen um dies zu kontrollieren.
%
Der Code in \appref{app:camera-control} zeigt, wie dieser gesamte Prozess von Konfiguration zur Aufnahme automatisiert werden kann.

\tablevspaceASenum
\begin{longtable}[l]{ @{} >{\RaggedRight\hspace{0pt}} lp{.96\linewidth} @{} }
    \textbullet & Die Möglichkeit in \imgref{img:Aufbau-Normal} zeigt die kontrollierte fixierung der Kamera welche normal auf das Gerät schaut. \\
    \textbullet & In \imgref{img:Aufbau-Weit-Normal} ist dieselbe Kamera ungefähr fünf Meter entfernt beschwert und positioniert worden. Das Gerät ist noch zusätzlich rotiert aufgestellt. \\
    \textbullet & Bei \imgref{img:Aufbau-Weit-Schräg} ist die Kamera ungefähr zwei Meter entfernt positioniert und das Gerät ist noch zusätzlich rotiert und schräg aufgestellt. \\
    \textbullet & Bei \imgref{img:Aufbau-Nah-Schräg} ist die Kamera so nah wie möglich positioniert, sodass das Gerät gerade noch sichtbar ist im Video. Das Gerät ist noch zusätzlich rotiert und schräg aufgestellt. \\
    \addtocounter{table}{-1}\setcounter{enumi}{0}
\end{longtable}

\noindent\begin{minipage}[t]{\dimexpr.994\linewidth/3}\vspace{0pt}
    \begin{centering}
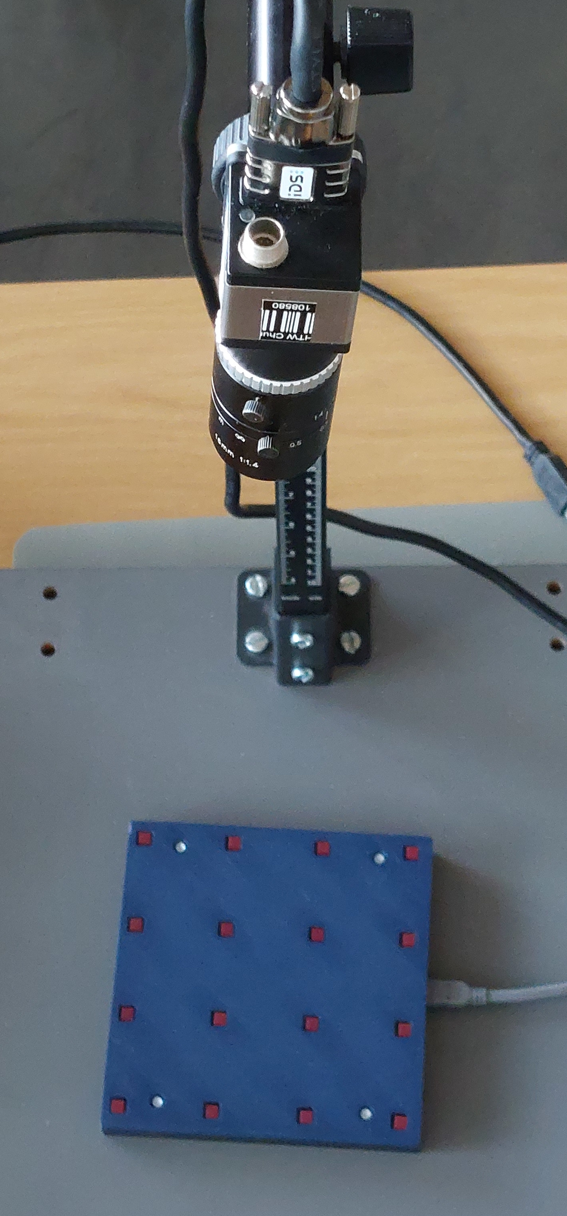
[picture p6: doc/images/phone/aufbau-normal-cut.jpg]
        
        \vspace{-1.0em}
        \captionof{figure}{Aufbau Aufnahme}
        \label{img:Aufbau-Normal}
    \end{centering}
\end{minipage}
\noindent\begin{minipage}[t]{\dimexpr.994\linewidth/3}\vspace{0pt}
    \begin{centering}
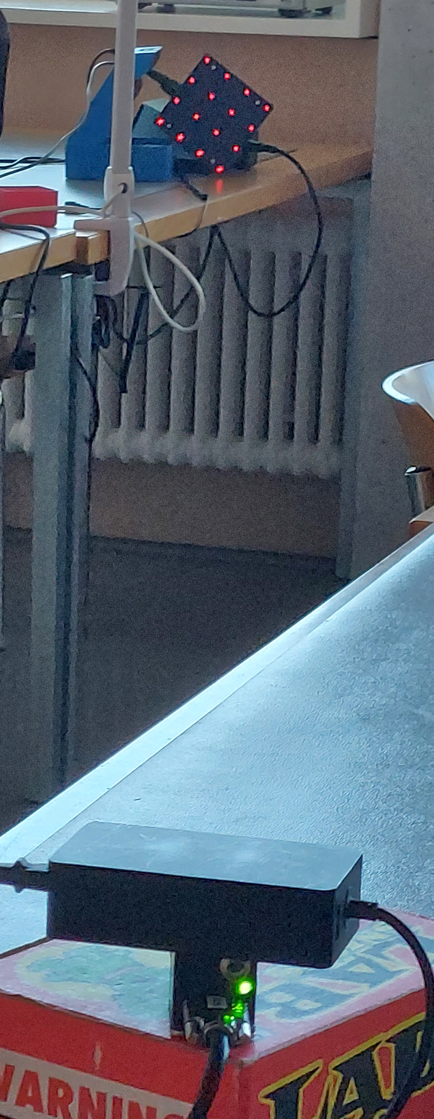
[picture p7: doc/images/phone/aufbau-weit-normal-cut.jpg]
        
        \vspace{-1.0em}
        \captionof{figure}{Aufbau (Weit)}
        \label{img:Aufbau-Weit-Normal}
    \end{centering}
\end{minipage}
\noindent\begin{minipage}[t]{\dimexpr.994\linewidth/3}\vspace{0pt}
    \begin{centering}
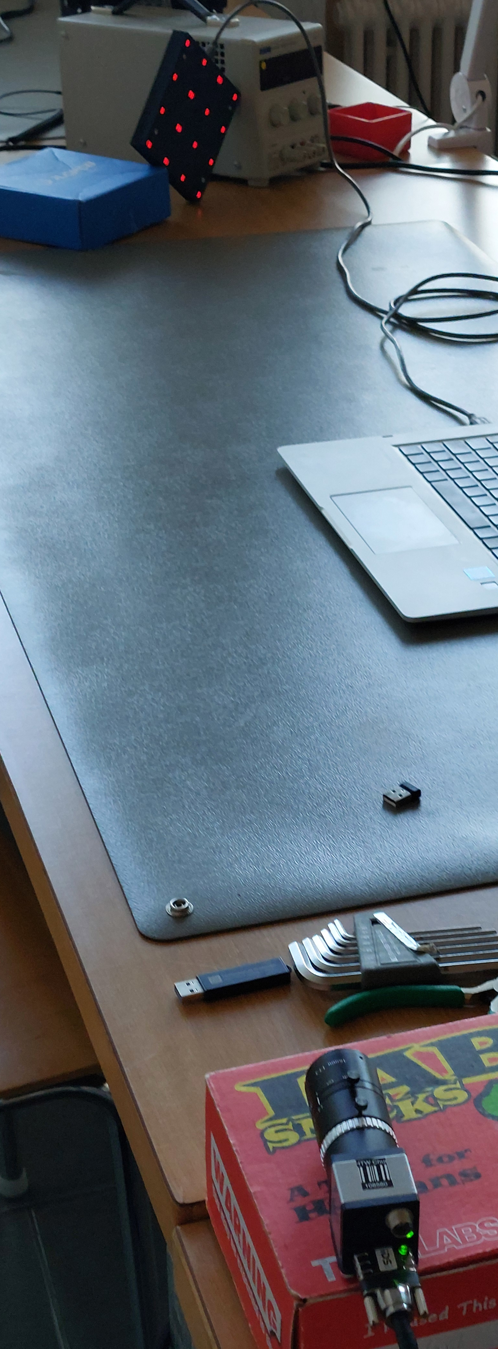
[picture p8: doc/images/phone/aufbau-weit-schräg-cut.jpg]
        
        \vspace{-1.0em}
        \captionof{figure}{Aufbau (Weit + Schräg)}
        \label{img:Aufbau-Weit-Schräg}
    \end{centering}
\end{minipage}

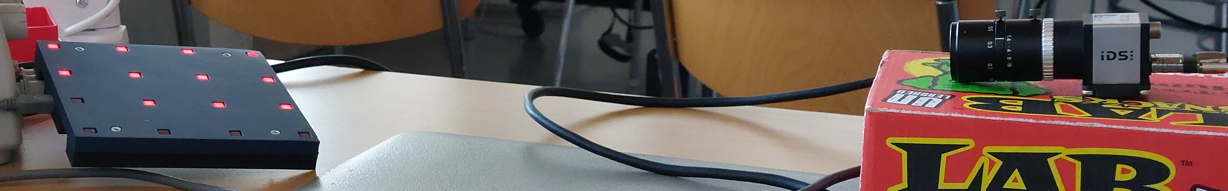
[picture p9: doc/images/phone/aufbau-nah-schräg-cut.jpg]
    
    \vspace{-2.5em}
    \captionof{figure}{Aufbau (Nah + Schräg)}
    \label{img:Aufbau-Nah-Schräg}

%}}}

\subsection{Auswerteverfahren}\label{sec:Auswerteverfahren} %{{{

%}}}

\subsubsection{Reihenfolge der Modi}\label{sec:Reihenfolge-der-Modi} %{{{

Die Reihenfolge der Modi im \hyperlinkXY{hyp:mode-auto} Modus ist in \tabref{table:Reihenfolge-der-Modi} beschrieben.

\tablevspaceAStable
\begin{tabular}{ @{} >{\RaggedRight\hspace{0pt}} lllll @{} }
    \# & Schritt & \hyperlink{sec:Modi}{Modus} & Beschreibung & Zweck \\
    \hline
    \hypertarget{order:step1}{1.}   & \verb|ALL_OFF| & \hyperlinkXY{hyp:mode-none} & Alle LEDs aus & Initiale Detektion \\
    \hypertarget{order:step2}{2.}   & \verb|ALL_ON| & \hyperlinkXY{hyp:mode-display} & Alle LEDs ein & Initiale Detektion \\
    \hypertarget{order:step3}{3.}   & \verb|PATTERN| & \hyperlinkXY{hyp:mode-display} & Orientierungsmuster & Initiale Detektion \\
    \hypertarget{order:step4}{4.}   & \verb|SYS_FREQ| & \hyperlinkXY{hyp:mode-display} & Systemfrequenz in MHz & Übermittlung Einstellungen \\ % ABBREV
    \hypertarget{order:step5}{5.}   & \verb|PSC| & \hyperlinkXY{hyp:mode-display} & Prescaler vom Timer & Übermittlung Einstellungen \\
    \hypertarget{order:step6}{6.}   & \verb|ARR| & \hyperlinkXY{hyp:mode-display} & Auto-Reload-Register vom Timer & Übermittlung Einstellungen \\
    \hypertarget{order:step7}{7.}   & \verb|PWM_COUNT| & \hyperlinkXY{hyp:mode-display} & Anzahl von PWM Stufen & Kalibration für Rider \\ % ABBREV
    \hypertarget{order:step8}{8.}   & \verb|PWM_CYCLE| & \hyperlinkXY{hyp:mode-pwm} & PWM Stufen & Kalibration für Rider \\ % ABBREV
    \hypertarget{order:step9}{9.}   & \verb|PWM_END| & \hyperlinkXY{hyp:mode-none} & Alle LEDs aus & Kalibration für Rider \\
    \hypertarget{order:step10}{10.} & \verb|RIDER| & \hyperlinkXY{hyp:mode-rider} & Eine LED wandert kontinuierlich & Tatsächliche Auswertung \\
\end{tabular}
\captionof{table}{Reihenfolge der Modi}
\label{table:Reihenfolge-der-Modi}
%}}}

\subsubsection{Detektion \& Ausrichtung des Orientierungsmuster}\label{sec:Detektion-Ausrichtung-des-Orientierungsmuster} %{{{

Hierfür werden die ersten drei Schritte \hyperlink{order:step1}{\texttt{ALL\_OFF}}, \hyperlink{order:step2}{\texttt{ALL\_ON}} \& \hyperlink{order:step3}{\texttt{PATTERN}} verwendet.

\aparagraph{Detektion aller LEDs \& Finden des Orientierungsmuster}

In diesem ersten Schritt werden ein aktuelles Bild mit dem vorangehenden verglichen.
Auschlaggebender Indikator für eine Musteränderung ist ein globaler Unterschied der Pixelhelligkeiten.
Die zwei Schritte, welche darauf zurückgreifen, sind in \tabref{table:Initiale-Detektion} aufgelistet.

\tablevspaceAStable
\begin{tabular}{ @{} >{\RaggedRight\hspace{0pt}} llll @{} }
  Vorherig & Aktuell & Indikator & Gewonnene Information\\
  \hline
  \hyperlink{order:step1}{\texttt{ALL\_OFF}} & \hyperlink{order:step2}{\texttt{ALL\_ON}} & Alle LEDs beginnen zu leuchten & Index $i_{\texttt{ALL\_ON}\bot}$ des Schrittes im Video \\
  \hyperlink{order:step2}{\texttt{ALL\_ON}} & \hyperlink{order:step3}{\texttt{PATTERN}} & Mehrere LEDs schalten aus & Index $i_{\texttt{PATTERN}\bot}$ des Schrittes im Video \\
\end{tabular}
\captionof{table}{Initiale Detektion}
\label{table:Initiale-Detektion}
\tablevspaceAStable

Aus den nun bekannten Indizes können robust
$i_\texttt{ALL\_OFF}$ \eqref{eq:i_ALL_OFF},
$i_\texttt{ALL\_ON}$ \eqref{eq:i_ALL_ON} und
$i_\texttt{PATTERN}$ \eqref{eq:i_PATTERN}
berechnet werden, in denen jeweils keine, alle LEDs, oder das Orientierungsmuster zu sehen sind im Bild \eqref{eq:M_i}.

\begin{equation}\label{eq:i_ALL_OFF}
  i_\texttt{ALL\_OFF} = \left\lfloor \frac{3\cdot i_{\texttt{ALL\_ON}\bot} - i_{\texttt{PATTERN}\bot}}{2} \right\rceil
\end{equation}

\begin{equation}\label{eq:i_ALL_ON}
  i_\texttt{ALL\_ON} = \left\lfloor \frac{i_{\texttt{PATTERN}\bot} + i_{\texttt{ALL\_ON}\bot}}{2} \right\rceil
\end{equation}

\begin{equation}\label{eq:i_PATTERN}
  i_\texttt{PATTERN} = \left\lfloor \frac{3\cdot i_{\texttt{PATTERN}\bot} - i_{\texttt{ALL\_ON}\bot}}{2} \right\rceil
\end{equation}

\begin{equation}\label{eq:M_i}
    M_i = \text{Bild Nummer ''} i \text{`` im Video}
\end{equation}

%}}}

\aparagraph{Gültige Positionen Filtern}\label{sec:Gültige-Positionen-Filtern} %{{{

Hierfür werden die beiden Bilder \img{Dunkel} und \img{Hell}, bei jeweils den indizes \eqref{eq:i_ALL_OFF} und \eqref{eq:i_ALL_ON}, verwendet.

Nacheinander kommen folgende Schritte zur Anwendung, um möglichst robust die gültige Position $p$ des Gerätes zu finden:

\tablevspaceASenum
\begin{longtable}[l]{ @{} >{\RaggedRight\hspace{0pt}} lp{.9\linewidth} @{} }
    \refstepcounter{enumi}\theenumi. & Berechnung von $\img{Unterschied} = \img{Dunkel} - \img{Hell}$
    \\\refstepcounter{enumi}\theenumi. & Anwenden von OTSU-Filter \cite{opencv-threshold} auf \img{Unterschied}
    \\\refstepcounter{enumi}\theenumi. & Konturen finden \& deren Zentren berechnen
    \\\refstepcounter{enumi}\theenumi. & Alle Zentren verbinden \& deren Längen berechnen
    \\\refstepcounter{enumi}\theenumi. & Winkel der Verbindungen berechnen und ähnlich orientierte Verbindungen gruppieren
    \\\refstepcounter{enumi}\theenumi. & Gruppierung mit den meisten Winkeln ergibt die Hauptrichtung
    \\\refstepcounter{enumi}\theenumi. & Gruppierung mit genügend grosser Winkeldifferenz zur Hauptrichtung ergibt die zweite Richtung
    \\\refstepcounter{enumi}\theenumi. & Verbindungen ziehen entlang der ersten und zweiten Richtung
    \\\refstepcounter{enumi}\theenumi. & Die kürzesten acht Verbindungen verwerfen in beiden Richtungen (um zum Beispiel Spigelungen an einem Tisch herauszufiltern)
    \\\refstepcounter{enumi}\theenumi. & Lange Verbindungen verwerfen in beiden Richtungen
    \\\refstepcounter{enumi}\theenumi. & Verbleibenden Verbindungen welche nicht auf jeweils mindestens zwei Konturen fallen verwerfen
    \\\refstepcounter{enumi}\theenumi. & Finale Verbindungen gehen zurück auf die Zentren der Konturen, dies sind die Positionen
    \\\refstepcounter{enumi}\theenumi. & Finale Positionen in X- und Y-Richtung sortieren 
    \addtocounter{table}{-1}\setcounter{enumi}{0}
\end{longtable}

%\tablevspaceASenum

% abzug hell-dunkel => otsu threshold
% konturen finden
% zentren der konturen finden
% alle zentren verbinden
% kürzeste 8 strecken streichen
% ähnliche winkel gruppieren -> 1. und 2. orientierung -> diese linien beibehalten
% nun nur die linien beibehalten, die innerhalb eines vier-eck eines anderen punkes sind
% sortieren der punkte nach x- und y- richtung

% Feedback: Bilder aus der Präsentation ebenfalls hier einfügen :)

%}}}

\aparagraph{Interpretation des Orientierungsmuster}\label{sec:Interpretation-des-Orientierungsmuster} %{{{

Das zu untersuchende Bild, welches das Orientierungsmuster anzeigt, ist durch \eqref{eq:i_PATTERN} gegeben.
Ausserdem wird, ähnlich zum vorherigen Schritt ein ``Dunkel''-Bild \eqref{eq:i_ALL_OFF} abgezogen vom zu untersuchenden Bild.

\begin{equation}\label{eq:hat-M_PATTERN}
  \widehat{M}_{\texttt{PATTERN}} = \frac{M_{\texttt{PATTERN}} - M_{\texttt{ALL\_OFF}} }{M_{\texttt{ALL\_ON}} - M_{\texttt{ALL\_OFF}} }
\end{equation}

Die normierten Zustände der LEDs werden in \eqref{eq:hat-M_PATTERN} bei den vorherig ermittelten Positionen bestimmt.
In einem vom Benutzer beeinflussten Radius wird für jede Position der Mittelwert gebildet.
Durch binäres Thresholding um 0.5 werden die Bit-Zustände berechnet.

\noindent\begin{minipage}[t]{.65\linewidth}\vspace{0pt}
\vspace{-0.65em}
  Das Gerät zeigt die Hexadezimalzahl \texttt{0x842F} als Orientierungsmuster an.
  Auf einem 4x4 Bitfeld resultiert dies in einem ``Pfeil'', welcher auf das LSB (Least significant Bit) zeigt, wie in \tabref{table:Orientierungsmuster} zu sehen.

  Das gezeigte Muster kann gespiegelt oder eine beliebige Richtung gedreht sein.
  Um das Muster korrekt zu orientieren, wird im ersten Schritt die Reihe gesucht, in der alle vier Bits aktiv sind (rot dargestellt).

\end{minipage}
\noindent\begin{minipage}[t]{.33\linewidth}\vspace{0pt}
  \begin{center}
    \begin{tabular}{ | >{\RaggedRight\hspace{0pt}} c|c | }
      \hline \text{Muster} & \text{Gespiegelt} \\\hline
      \begin{tabular}{ @{} >{\RaggedRight\hspace{0pt}} c @{} }
        \texttt{1 0 0 0} \\
        \texttt{0 1 0 0} \\
        \texttt{0 0 1 0} \\
        \texttt{\textbf{\color{red}1 1 1 1}} \\
      \end{tabular}
      &
      \begin{tabular}{ @{} >{\RaggedRight\hspace{0pt}} c @{} }
        \texttt{\textbf{\color{blue}0} 0 0 1} \\
        \texttt{\textbf{\color{blue}0} 0 1 0} \\
        \texttt{\textbf{\color{blue}0} 1 0 0} \\
        \texttt{\textbf{\color{blue}1} 1 1 1} \\
      \end{tabular}
      \\\hline
    \end{tabular}
    \captionof{table}{Orientierungsmuster}
    \label{table:Orientierungsmuster}
  \end{center}
  \setlength\lineskip{0pt}
\end{minipage}

\strut Danach kann das Muster um 90° gedreht nach den Reihenfolgen \texttt{0b1000} (blau dargestellt), \texttt{0b1100}, \texttt{0b1010} und \texttt{0b1001} überprüft werden.

% }}}

\subsubsection{Übermitteln von Einstellungen \& Kalibration der Leuchtdioden-Intensität} %{{{

Es werden die Schritte \hyperlink{order:step4}{\texttt{SYS\_FREQ}}, \hyperlink{order:step5}{\texttt{PSC}}, \hyperlink{order:step6}{\texttt{ARR}}, \hyperlink{order:step7}{\texttt{PWM\_COUNT}}, \hyperlink{order:step8}{\texttt{PWM\_CYCLE}} \& \hyperlink{order:step9}{\texttt{PWM\_END}} analysiert.

\aparagraph{Erkennen aller Binärwerte}\label{sec:Erkennen-aller-Binärwerte}

Bild für Bild wird die Binärzahl ausgewertet des aktuellen Bildes $M_\textit{aktuell}$ bei index $i_\textit{aktuell}$ in \eqref{eq:hat-M_aktuell}.

\begin{equation}\label{eq:hat-M_aktuell}
  \widehat{M}_{\textit{aktuell}} = \frac{M_{\textit{aktuell}} - M_{\texttt{ALL\_OFF}} }{M_{\texttt{ALL\_ON}} - M_{\texttt{ALL\_OFF}} }
\end{equation}

Die zu erwartenden Werte sind alle unbekannt aber grösser als $0$.
Einzig der Wert nach dem Anzeigen von allen digitalen Informationen, bei der PWM-Stufe 0\% ist bekannt, nämlich $0$.
Ausschlaggebender Index ist folglich $i_{\texttt{PWM\_0\%}\bot}$ wenn eine $0$ angezeigt wird.
Dazu wird der Unterschied in \eqref{eq:Delta_i} gebraucht, um
die restlichen Indizes der Schritte \hyperlinkXY{order:step4} \eqref{eq:i_SYS_FREQ} bis \hyperlinkXY{order:step7} \eqref{eq:i_PWM_COUNT} zu ermitteln.

\begin{align}
  % https://tex.stackexchange.com/questions/44450/how-to-align-a-set-of-multiline-equations
  \phantom{i_{\texttt{PWM\_COUNT}} } % längste linke Hälfte
    &\begin{aligned}\label{eq:Delta_i}
    \mathllap{ \Delta i} &= \frac{i_{\texttt{PWM\_0\%}\bot} - i_{\texttt{PATTERN}\bot}}{5}
  \end{aligned}\\
    &\begin{aligned}\label{eq:i_SYS_FREQ}
    \mathllap{ i_{\texttt{SYS\_FREQ}} } &= i_{\texttt{PATTERN}\bot} + \frac{3 \cdot \Delta i}{2}
  \end{aligned}\\
  &\begin{aligned}
    \mathllap{ i_{\texttt{ARR}} } &= i_{\texttt{PATTERN}\bot} + \frac{5 \cdot \Delta i}{2}
  \end{aligned}\\
  &\begin{aligned}
    \mathllap{ i_{\texttt{PSC}} } &= i_{\texttt{PATTERN}\bot} + \frac{7 \cdot \Delta i}{2}
  \end{aligned}\\
  &\begin{aligned}\label{eq:i_PWM_COUNT}
    \mathllap{ i_{\texttt{PWM\_COUNT}} } &= i_{\texttt{PATTERN}\bot} + \frac{9 \cdot \Delta i}{2}
  \end{aligned}
  %\end{equation}
\end{align}

Um die Robustheit sicherzustellen, wird bei jedem Index jeweils um $\pm \frac{\Delta i}{4}$ erweitert in \eqref{eq:M_i_Delta_i} und die angezeigten Binärzahlen der entsprechenden Bilder ausgewertet.

\begin{equation}\label{eq:M_i_Delta_i}
  \bar{M}_i(\Delta i) = \left\lfloor \frac{2}{\Delta i} \right\rceil \sum_{ k=\left\lfloor i-\frac{\Delta i}{4} \right\rceil }^{ \left\lfloor i+\frac{\Delta i}{4} \right\rceil } \widehat{M}_{k}
\end{equation}

\aparagraph{Intensitätskalibration}

Die Intensitätskalibration (siehe \secref{sec:Machbarkeitsanalyse-der-Kalibration}) geschieht über die PWM Ansteuerung der LEDs.

Ähnlich wie im \secref{sec:Erkennen-aller-Binärwerte} wird zuerst das Ende von \hyperlink{order:step9}{\texttt{PWM\_END}} $i_{\texttt{PWM\_END}\bot}$ gesucht, wo alle LEDs ausgeschaltet sind.
Die Anzahl an PWM-Stufen in linearen Abständen ist vorgegeben durch \eqref{eq:i_PWM_COUNT}.
Durch die Anzahl an Stufen und den Start- \& Stopp-Indizes $i_{\texttt{PWM\_0\%}\bot}$ und $i_{\texttt{PWM\_END}\bot}$ werden die Helligkeiten bestimmt und für zukünftige Messungen linear interpoliert
in \eqref{eq:Delta_i_PWM}.

\begin{equation}\label{eq:Delta_i_PWM}
  \Delta i_\texttt{PWM} = \frac{i_{\texttt{PWM\_END}\bot} - i_{\texttt{PWM\_0\%}\bot} }{n_{\texttt{PWM\_COUNT}} + 1 }
\end{equation}

Die Bilder bei PWM-Stufen $k\in\{\,0 \ldots n_\texttt{PWM\_COUNT}\,\}$ in \eqref{eq:i_PWM_k} werden mithilfe von \eqref{eq:M_i_Delta_i} über \eqref{eq:Delta_i_PWM} gemittelt. Bei den Positionen $p$ werden in \eqref{eq:hat_M_PWM_k_Delta_i_PWM} die Helligkeiten ausgewertet.

\begin{equation}\label{eq:i_PWM_k}
  i_{\texttt{PWM}}(k) = k\cdot \Delta i_\texttt{PWM} + i_{\texttt{PWM\_0\%}} + \frac{\Delta i_\texttt{PWM}}{2}
\end{equation}

\begin{equation}\label{eq:hat_M_PWM_k_Delta_i_PWM}
  \bar{M}_\texttt{PWM}(k)(\Delta i_\texttt{PWM})
\end{equation}

Angenommen das Gerät ist konfiguriert auf 16 PWM-Stufen, so sind die Helligkeiten von 0\% bis 100\% in 16 Schritten linear abgebildet.
In \imgref{img:PWM-Kurven-bei-offener-Blende} und \imgref{img:PWM-Kurven-bei-mittlerer-Blende} sind die Punkte die gemessenen Helligkeiten und die gestrichelten Linien die rückwärts linear interpolierten Kurven.

\vspace{-1em}
\noindent\begin{minipage}[t]{.49\linewidth}\vspace{0pt}
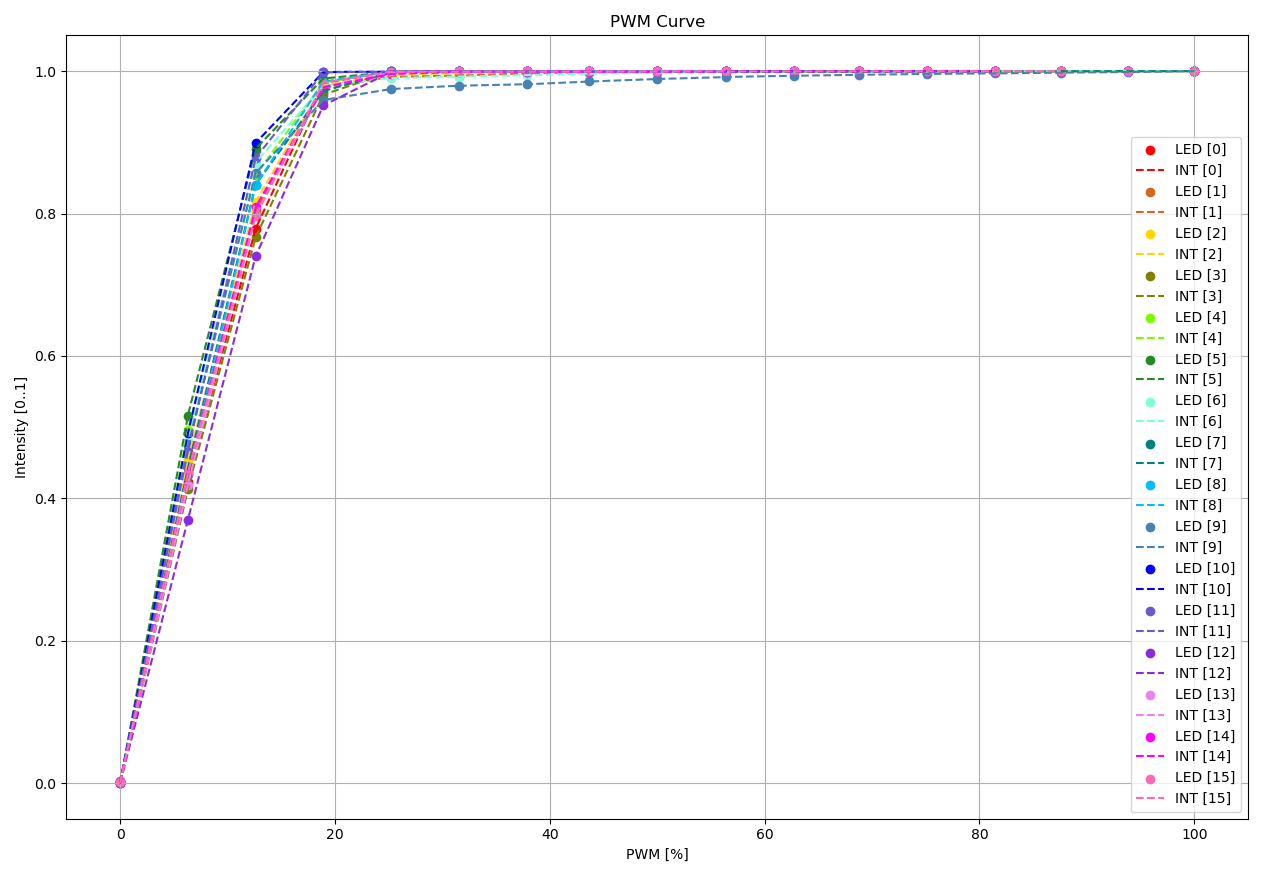
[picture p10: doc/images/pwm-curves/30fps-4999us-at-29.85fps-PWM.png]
  
  \vspace{-2.5em}
  \captionof{figure}{PWM Kurven bei offener Blende}
  \label{img:PWM-Kurven-bei-offener-Blende}
\end{minipage}
\noindent\begin{minipage}[t]{.49\linewidth}\vspace{0pt}
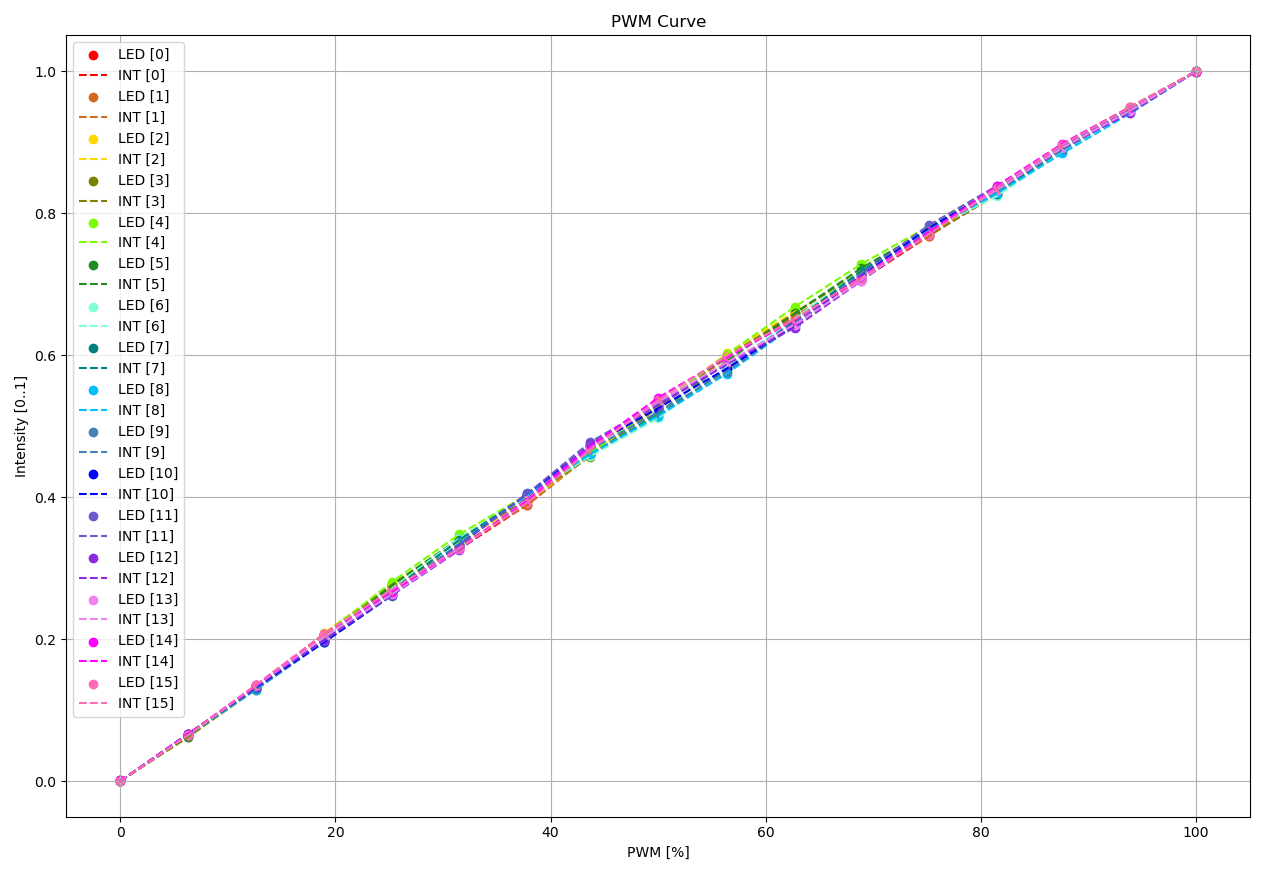
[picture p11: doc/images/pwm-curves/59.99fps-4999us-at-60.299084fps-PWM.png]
  
  \vspace{-2.5em}
  \captionof{figure}{PWM Kurven bei mittlerer Blende}
  \label{img:PWM-Kurven-bei-mittlerer-Blende}
\end{minipage}

%}}}

\subsubsection{Zentrum der laufenden Leuchtdiode}\label{sec:Zentrum-def-laufenden-Leuchtdiode} %{{{

% TODO: beispielbild? => zeigen dass mehr als eine LED leuchtet

Das Zentrum der aktiven Leuchtdioden wird als Kodierung der Stabilität im Video verwendet.
Für den Fall, wenn die aktiven LEDs beide Ränder überlappen, muss dies berücksichtigt werden.
%
Der gewählte Ansatz \eqref{eq:varphi} ordnet die LEDs in der Berechnung im Kreis an und berechnet aus den Intensitäten $I$ den Winkel $\varphi$.
%
So ist auch im Fall, wenn eine Wanderung vom einen Rand zum anderen geschieht, klar in welche Richtung sich diese bewegt.

\begin{equation}\label{eq:varphi}
    \varphi = \arctan \left(
    \sum_{k=0}^{n_\text{LED}-1} \frac{
        \sin\left( \frac{2\pi k I_{k+1}}{n_\text{LED}} \right) }{
        \cos\left( \frac{2\pi k I_{k+1}}{n_\text{LED}} \right) }
    \right)
\end{equation}

Über den Prescaler und Auto-Reload ist $f_R$ durch \eqref{eq:f_Timer} gegeben.
Durch diverse Toleranzen der elektronischen Bauteile ist die eingestellte Geschwindigkeit $f_R$ der LEDs ungleich der reellen $f_G$, siehe \secref{sec:Rider-Modus}.
Es ist wichtig, dass eine korrekte Einstellung der Frequenz vom Messgerät vorgenommen wird, siehe \secref{sec:Gut-Eingestellt}.

Der Unterschied der Eingestellten tatsächlichen Frequenz $f_G$ zur Kamerafrequenz ist durch \eqref{eq:Delta-f} gegeben.
Daraus und mit \eqref{eq:varphi} lässt sich ein Unterschied in Winkeländerungen $\Delta\dot\varphi$ \eqref{eq:Delta-dot-varphi} berechnen.
Dieser Unterschied korreliert mit der Abweichung von der eingestellten zur ermittelten Kamerafrequenz $f$ in \eqref{eq:f}.

\begin{equation}\label{eq:Delta-f}
    \Delta f = f_G - f_K
\end{equation}

\begin{equation}\label{eq:Delta-dot-varphi}
    \Delta \dot\varphi = 2\pi\frac{\Delta f}{f_K} - \dot\varphi
\end{equation}

\begin{equation}\label{eq:f}
    f = \frac{2\pi + \frac{\Delta\dot\varphi}{\Delta f}}{2\pi} \cdot f_K
\end{equation}

%}}}

\subsubsection{Breite der laufenden Leuchtdiode}\label{sec:Breite-der-laufenden-Leuchtdiode} %{{{

Aus der Anzahl an aktiven Leuchtdioden über die Intensitäten $I$ und deren maximaler Intensität $I_\text{max}$ wird die Belichtungszeit $b$ im Video ermittelt \eqref{eq:b}.

% TODO: -> die Zeitstempel können nicht absolut, sondern nur relativ bestimmt werden (WIE IN DER EINLEITUNG ERWÄHNT)
% TODO: ... -> ?? Das bestimmen der Belichtungszeit lehnt sich stark an die Kalibration der PWM-Kurven.
% TODO: berechnen nicht mit f_B aber AVG!! von f?!? => sieht es stabiler aus? -> ja

\begin{equation}\label{eq:b}
    b = \frac{1}{\bar f \cdot n_\text{LED}} \sum_{k=1}^{n_\text{LED}} \frac{I_k}{I_\text{max}}
\end{equation}

%}}}

\subsection{Ergebnisse}

\subsubsection{Frequenzlimitationen}

Die maximal Einstellbare Geschwindigkeit einer LED im \hyperlinkXY{hyp:mode-rider} Modus beträgt 4.5kHz.

Die Taktgeschwindigkeit im \hyperlinkXY{hyp:mode-pwm} Modus jeder LED beträgt auch 4.5kHz.

\subsubsection{Frequenzzuverlässigkeit}

\aparagraph{Rider Modus}\label{sec:Rider-Modus}

Verschiedene Frequenzen wurden an einer LED im \hyperlinkXY{hyp:mode-rider} Modus mit einem Oszilloskop gemessen.
In \tabref{table:Eingestellte-Gemessene-Frequenzen} sind die genauen Messwerte aufgelistet und im \appref{app:measurements} beigelegt.
Diese sind in \imgref{img:Eingestellte-Gemessene-Frequenzen} relativ dargestellt und es zeigt sich,
dass
die tatsächliche Frequenz $f_G$ (gelb) bis zu 0.2‰ von der Zielfrequenz $f_R$ abweicht. % und
Die Standardabweichung $\sigma$ (rot) steigt mit der Frequenz.

\noindent\begin{minipage}[t]{.44\linewidth}\vspace{0pt}
\vspace{-1em}
\begin{centering}
\tablevspaceAStable
\begin{tabular}{ @{} >{\RaggedRight\hspace{0pt}} ccc @{} }
    $f_R$ [Hz] & $f_G$ [Hz] & $\sigma$ [µHz] \\
    \hline
    30.000 & 30.005 & 62.566 \\ 
    40.000 & 40.007 & 366.58 \\ 
    56.250 & 56.259 & 129.31 \\ 
    59.700 & 59.711 & 368.78 \\ 
    60.000 & 60.010 & 483.37 \\ 
    60.299 & 60.309 & 425.85 \\ 
    64.286 & 60.309 & 498.19 \\ 
    75.000 & 75.013 & 483.33 \\ 
    120.00 & 120.02 & 1'120.8 \\ 
    284.99 & 285.04 & 3'247.6 \\ 
    752.01 & 752.16 & 20'029 \\
    4500.0 & 4499.6 & 370'780
\end{tabular}
\captionof{table}{Überprüfte Frequenzen}
\label{table:Eingestellte-Gemessene-Frequenzen}
\end{centering}
\end{minipage}
\noindent\begin{minipage}[t]{.55\linewidth}\vspace{0pt}
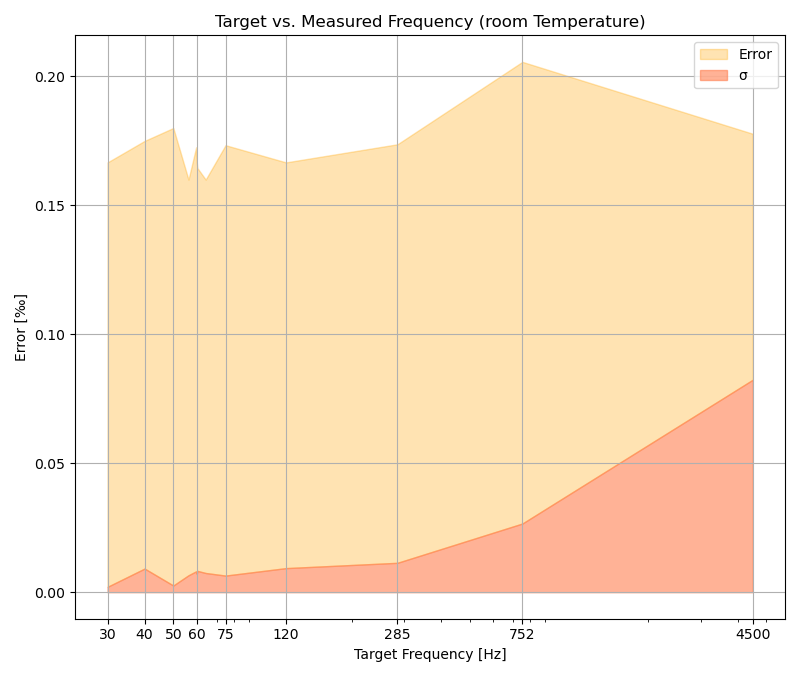
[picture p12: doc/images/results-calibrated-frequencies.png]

\vspace{-2.5em}
\captionof{figure}{Überprüfte Frequenzen}
\label{img:Eingestellte-Gemessene-Frequenzen}
\end{minipage}

\aparagraph{PWM Modus}\label{sec:PWM-Modus}

\noindent\begin{minipage}[t]{.52\linewidth}\vspace{0pt}
\vspace{-1em}
\begin{centering}
\tablevspaceAStable
\begin{tabular}{ @{} >{\RaggedRight\hspace{0pt}} cccc @{} }
    $z$ & Eingestellt [\%] & Gemessen [\%] & Fehler [\%] \\
    \hline
    % 6.25 & 6.37 & 1.91 \\ 
    % 50.00 & 50.06 & 0.12 \\ 
    % 93.75 & 93.81 & 0.06 \\
    0 & 0 & 0 & 0.00 \\
    1 & 6.25 & 6.31 & 0.90 \\
    2 & 12.50 & 12.61 & 0.90 \\
    3 & 18.75 & 18.92 & 0.90 \\
    4 & 25.00 & 25.23 & 0.90 \\
    5 & 31.25 & 31.53 & 0.90 \\
    6 & 37.50 & 37.84 & 0.90 \\
    7 & 43.75 & 43.69 & -0.13 \\
    8 & 50.00 & 50.00 & 0.00 \\
    9 & 56.25 & 56.40 & 0.26 \\
    10 & 62.50 & 62.70 & 0.32 \\
    11 & 68.75 & 68.83 & 0.11 \\
    12 & 75.00 & 75.14 & 0.18 \\
    13 & 81.25 & 81.44 & 0.24 \\
    14 & 87.50 & 87.57 & 0.08 \\
    15 & 93.75 & 93.87 & 0.13 \\
    16 & 100.0 & 100.0 & 0.00

\end{tabular}
\captionof{table}{Überprüfte Duty Cycles}
\label{table:Eingestellte-Gemessene-Frequenzen-PWM}
\end{centering}
\end{minipage}
\noindent\begin{minipage}[t]{.47\linewidth}\vspace{0pt}

    Das Messgerät besitzt $n_\texttt{PWM\_COUNT}=16$ PWM-Stufen welche grösser sind als 0\%.
    Der konkrete Duty Cycle $D$ ist gegeben über $z\in\{0\ldots n_\texttt{PWM\_COUNT}\}$ durch \eqref{eq:D}.

    Diese Stufen wurden einzeln an einer LED gemessen worden mit einem Oszilloskop (siehe \secref{sec:Überprüfung-von-Frequenzen}) und in \tabref{table:Eingestellte-Gemessene-Frequenzen-PWM} aufgelistet.
    Alle Messresultate sind im \appref{app:measurements} beigelegt.
    Die Abweichungen werden in der Software (\appref{app:eval-dynamic}) berücksichtigt.

    \begin{equation}\label{eq:D}
        D(z) = 100\%\cdot\frac{z}{n_\texttt{PWM\_COUNT}}
    \end{equation}

\end{minipage}

\aparagraph{Display Modus}

Der \hyperlinkXY{hyp:mode-display} Modus ist nicht zeitkritisch und es wurden deshalb keine Frequenzen überprüft.
Die Aktualisierungs-, bzw. Verzögerungszeit ist unbekannt, denn diese ist im Moment irrelevant.

\subsubsection{Gut eingestellt}\label{sec:Gut-Eingestellt}

Die Frequenz des Messgerätes $f_G$ ist gut eingestellt, wenn sie ein wenig von der Kamerafrequenz $f_K$ abweicht (zum Beispiel ungefähr 0.5\%).
Aus der Differenz der Frequenzen kann die im besten Fall maximal detektierbare Anzahl an ausgelassenen Bildern am Stück $s_\text{maxskip}$ berechnet werden gemäss \eqref{eq:s_maxskip}.

Resultate verschiedener Konfigurationen sind in \tabref{table:Auswertung-Gut} aufgeführt.
Im \appref{app:results} sind detaillierte Grafiken über die Zeit zu allen Resultaten zu finden.
Die Hersteller \cite{ids,aos} geben keine Toleranzen der Kameras an, somit ist kein Vergleich möglich, ob die gemessenen Frequenzen $\bar f$ und Belichtungszeiten $\bar b$ innerhalb einer Toleranz liegen oder nicht.
Dennoch sind die Abweichungen kleiner als 0.3\%, mit einem Ausreisser bei \hyperlinkXY{hyp:k-aos-285}.

\begin{table}[H]
\begin{longtable}[c]{ @{} >{\RaggedRight\hspace{0pt}} lrrrrrl @{} }
    % TODO: länge des clips? median? std?
    Kamera & $f_K$ [Hz] & $f_G$ [Hz] & $\bar f$ [Hz] & $b_K$ [µs] & $\bar b$ [µs] & Bilder in \appref{app:results} % & FPS & Belichtungszeit
    \\ \hline
       \hyperlinkXY{hyp:IDS} & 30.00 & 29.850 & 30.054 & 4999 & 5095 & \hyperlinkXY{hyp:k-ueye-29-85}
    \\ \hyperlinkXY{hyp:IDS} & 59.99 & 58.999 & 59.959 & 4999 & 5123 & \hyperlinkXY{hyp:k-ueye-59}
    \\ \hyperlinkXY{hyp:IDS} & 59.99 & 59.701 & 59.969 & 4999 & 5004 & \hyperlinkXY{hyp:k-ueye-59-7}
    \\ \hyperlinkXY{hyp:IDS} & 59.99 & 60.299 & 59.997 & 4999 & 5063 & \hyperlinkXY{hyp:k-ueye-60-3}
    \\ \hyperlinkXY{hyp:IDS} & 59.99 & 61.000 & 59.978 & 4999 & 5040 & \hyperlinkXY{hyp:k-ueye-61}
    \\ \hyperlinkXY{hyp:AOS} & 60.00 & 58.999 & 59.992 & 5000 & 5021 & \hyperlinkXY{hyp:k-aos-60}
    \\ \hyperlinkXY{hyp:AOS} & 285.0 & 284.99 & 281.70 & 2055 & 1997 & \hyperlinkXY{hyp:k-aos-285}
    \\ \hyperlinkXY{hyp:AOS} & 752.0 & 752.01 & 749.86 &  600 &  512 & \hyperlinkXY{hyp:k-aos-752}
\end{longtable}
\addtocounter{table}{-1}\setcounter{enumi}{0}
\captionof{table}{Auswertung bei gut eingestellten Frequenzen}
\label{table:Auswertung-Gut}
\addtocounter{table}{-1}\setcounter{enumi}{0}
\end{table}

\begin{equation}\label{eq:s_maxskip}
    s_\text{maxskip}=\frac{f_G}{2\cdot|f_G-f_K|}
\end{equation}

\subsubsection{Schlecht eingestellt}

Ist die Kamerafrequenz $f_K$ gleich oder sehr ähnlich der des Messgerätes $f_G$, könnte ein Auslassen eines Bildes im Video eventuell nicht erkannt werden,
falls die Aufnahmefrequenz vor und nach dem Auslassen konstant bleibt.

Gemäss \eqref{eq:s_maxskip} können bei bereits 25\% abweichen der Frequenz nur noch zwei hintereinander ausgelassene Bilder verlässlich detektiert werden.
Dennoch wurden mehrere Videos bei schlechten Frequenzen aufgenommen, um Effekte zu beobachten.
Die Resultate sind in \tabref{table:Auswertung-Schlecht} aufgeführt.
In den detaillierten Grafiken über die Zeit im \appref{app:results} ist deutlich, dass bei manchen Messungen Bilder gewonnen wurden, wo keine sind.

\begin{longtable}[c]{ @{} >{\RaggedRight\hspace{0pt}} lrrrrrl @{} } %p{.25\linewidth}p{.25\linewidth} @{} }
    Kamera & $f_K$ [Hz] & $f_G$ [Hz] & $\bar f$ [Hz] & $b_K$ [µs] & $\bar t$ [µs] & Bilder in \appref{app:results}  % & FPS & Belichtungszeit
    \\ \hline
       \hyperlinkXY{hyp:IDS} & 59.99 & 40.000 & 60.684 & 4999 & 5011 & \hyperlinkXY{hyp:b-ueye-40}
    \\ \hyperlinkXY{hyp:IDS} & 59.99 & 50.000 & 59.990 & 4999 & 5029 & \hyperlinkXY{hyp:b-ueye-50}
    \\ \hyperlinkXY{hyp:IDS} & 59.99 & 56.250 & 59.986 & 4999 & 5023 & \hyperlinkXY{hyp:b-ueye-56-25}
    \\ \hyperlinkXY{hyp:IDS} & 59.99 & 60.000 & 60.176 & 4999 & 5025 & \hyperlinkXY{hyp:b-ueye-60}
    \\ \hyperlinkXY{hyp:IDS} & 59.99 & 64.286 & 59.989 & 4999 & 4934 & \hyperlinkXY{hyp:b-ueye-64-29}
    \\ \hyperlinkXY{hyp:IDS} & 59.99 & 75.000 & 59.992 & 4999 & 4981 & \hyperlinkXY{hyp:b-ueye-75}
    \\ \hyperlinkXY{hyp:IDS} & 59.99 & 120.00 & 60.989 & 4999 & 4894 & \hyperlinkXY{hyp:b-ueye-120}
\end{longtable}
\addtocounter{table}{-1}\setcounter{enumi}{0}
\captionof{table}{Auswertung bei schlecht eingestellten Frequenzen}
\label{table:Auswertung-Schlecht}

\subsubsection{Einfluss der Bildqualität}

Das Bild kann ziemlich verschwommen sein, wie in \imgref{img:Verschwommene-LEDs} gezeigt, und das Resultat weicht nicht stärker ab als bei idealen Konditionen.
Wenn die Kamera einen Rolling Shutter verwendet, zeigt die Auswertung grosse Variation.
Zwei solche Messungen wurden durchgeführt und die Resultate sind in \tabref{table:Auswertung-Bildqualität} aufgelistet.

\begin{centering}
    \vspace{1em}
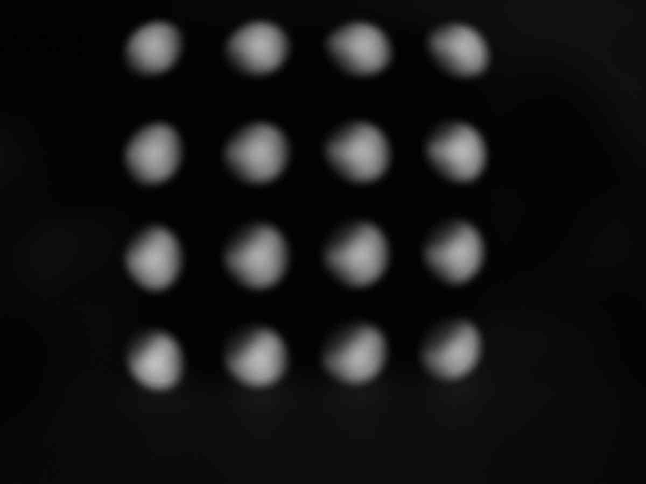
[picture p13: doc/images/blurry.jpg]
    
    \vspace{-1.0em}
    \captionof{figure}{Verschwommene LEDs}
    \label{img:Verschwommene-LEDs}
\end{centering}

\begin{longtable}[c]{ @{} >{\RaggedRight\hspace{0pt}} lrrrrrl @{} }
    Kamera & $f_K$ [Hz] & $f_G$ [Hz] & $\bar f$ [Hz] & $b_K$ [µs] & $\bar t$ [µs] & Bilder in \appref{app:results}  % & FPS & Belichtungszeit
    \\\hline
      \hyperlinkXY{hyp:IDS} (verschwommen) & 59.99 & 59.701 & 59.974 & 4999 & 5018 & \hyperlinkXY{hyp:k-ueye-59-7-blur}
    \\\hyperlinkXY{hyp:A52} (Rolling Shutter) & 60.00 & 59.701 & 59.792 & ca. 10000 & 9921 & \hyperlinkXY{hyp:b-a52-59-7-rolling}
\end{longtable}
\captionof{table}{Auswertung bei schlechter Bildqualität}
\label{table:Auswertung-Bildqualität}

\subsubsection{Einfluss der Kalibration}

Aus den Bildern in \appref{app:results} erschliesst sich, dass die Kalibration die Messungen zum grössten Teil ein wenig verschäft.
Die FPS verschiebt sich im besten Fall sehr wenig (\imgref{img:fps-ot}), die Belichtungszeit wird schmaler (\imgref{img:exposure-ot}) und die Belichtungszeit zu Winkel werden ausgeglichener (\imgref{img:vs}).
Als Beispiel sind die Bilder aus \appref{app:results} \hyperlinkXY{hyp:k-ueye-60-3} gezeigt.
Die blauen Daten sind korrigiert und die orangenen sind die Rohdaten welche die Kalibration ignorieren.

\noindent\begin{minipage}[t]{\dimexpr.994\linewidth/3}\vspace{0pt}
    \begin{centering}
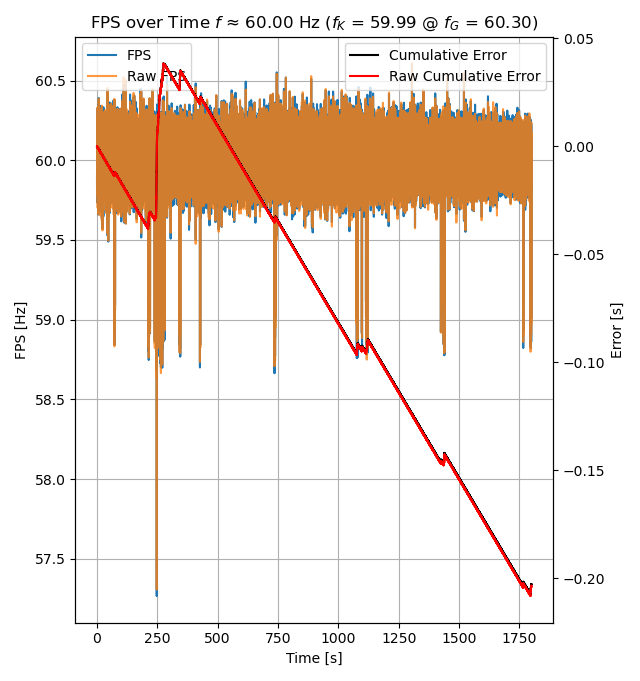
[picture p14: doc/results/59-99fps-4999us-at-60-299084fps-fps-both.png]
        
        \vspace{-2.0em}
        \captionof{figure}{FPS über Zeit}
        \label{img:fps-ot}
    \end{centering}
\end{minipage}
\noindent\begin{minipage}[t]{\dimexpr.994\linewidth/3}\vspace{0pt}
    \begin{centering}
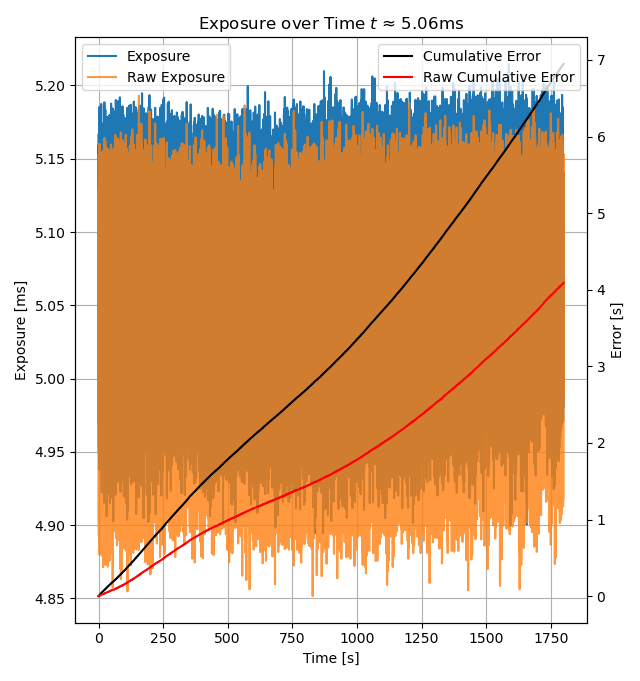
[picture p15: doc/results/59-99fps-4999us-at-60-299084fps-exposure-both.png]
        
        \vspace{-2.0em}
        \captionof{figure}{Belichtung über Zeit}
        \label{img:exposure-ot}
    \end{centering}
\end{minipage}
\noindent\begin{minipage}[t]{\dimexpr.994\linewidth/3}\vspace{0pt}
    \begin{centering}
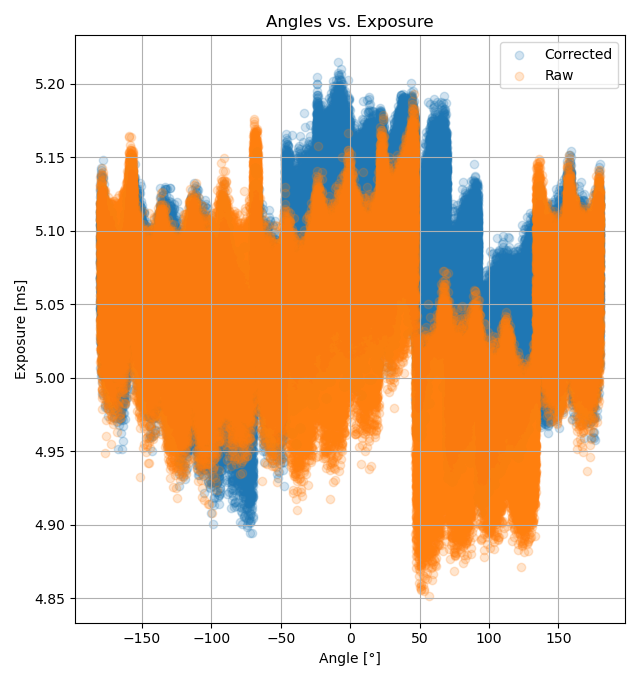
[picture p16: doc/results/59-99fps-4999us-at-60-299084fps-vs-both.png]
        
        \vspace{-2.0em}
        \captionof{figure}{Belichtung zu Winkel}
        \label{img:vs}
    \end{centering}
\end{minipage}

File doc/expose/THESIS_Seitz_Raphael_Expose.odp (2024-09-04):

## Exposé Bachelorthesis

Entwicklung eines automatischen Timing-Messgeräts für Kameras

Raphael Seitz, pho_21_vz

01.03.2024

## Inhaltsverzeichnis

- Inhalt der Bachelorarbeit
- Ausformulierte Forschungsfragen
- Themen- / Systemabgrenzung
- Meilensteine
- Zeitplan
- Inhaltsverzeichnis Bericht
- Quellenverzeichnis
- Technologiekonzept
- Weitere Diskussionspunkte

## Inhalt der Bachelorthesis

- Iterative Entwicklung einer Hardware mit Mikrokontroller
- Implementierung der Software des Mikrokontrollers zur Kommunikation mit USB
- 2D-Bildverarbeitung zum finden der Hardware und auslesen der LEDs
- Visualisierung der Auswertung

## Ausformulierte Forschungsfragen

- Mit welcher Anordnung / Ansteuerung der LEDs kann geschickt Zeit kodiert und detektiert werden?
- Wie können welche Kamerafehler und Aufnahmeeigenschaften detektiert werden?
- Wie grob weichen die vom Hersteller versprochen Aufnahmeeigenschaften ab?
- Welche Einflüsse hat eine variierende Bildqualität?

## Themen- / Systemabgrenzung


## Meilensteine

- M1 Kickoff Bachelorthesis
- M2 Abgabe Exposé
- M3 Stationärer Prototyp ohne Finder
- M4 Freies Messystem mit Finder
- M5 Abgabe Bericht

## Zeitplan

- Vorbereiten bis KW09 / 01.03.2024
- Prototyp bis KW15 / 12.04.2024
- Messsystem bis KW24 / 14.06.2024
- Bericht bis KW28 / 12.07.2024
- Korrektur + Abgabe bis KW32 / 09.08.2024

## Inhaltsverzeichnis Bericht (Änderungen Vorbehalten)

- Abstract
- Inhaltsverzeichnis
- Abkürzungsverzeichnis
- Einleitung
  - Ausgangslage
  - Problemstellung
  - Fragestellung und Zielsetzung
  - Vorgehensweise
- Hauptteil
  - Schema
  - Layout
  - Software uC
  - Software PC
  - Ansätze zur Auswertung
- Ergebnisse
  - Auswertung
  - Zuverlässigkeit
  - Optimierungsmöglichkeiten
- Quellenverzeichnis
- Abbildungs- & Tabellenverzeichnis

## Quellenverzeichnis

- The Python Book
- A LED-Based IR/RGB End-to-End Latency Measurement Device
- Indoor localization based on LEDs
- Data Matrix Code Location Based on Finder Pattern Detection and Bar Code Border Fitting

## Technologiekonzept

- 2D-Matrix Anordnung von LEDs
- Eine LED die aktiv ist und "wandert"
- Anzahl aktive LEDs im Bild = Beleuchtungszeit
- Position + Helligkeit LEDs = Zeitstempel
- Frequenz mit Kamera abgestimmt

## Diskussionspunkte

- Bericht in Englisch oder Deutsch schreiben?
- Weitere Termine für Besprechungen
- Kostenabschätzung : Geringe Materialkosten

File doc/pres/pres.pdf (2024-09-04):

## Entwicklung eines automatischen Timing-Messgeräts für Kameras

Bachelorthesis der Fachhochschule Graubünden

30.08.2024
Raphael Seitz

Inhaltsverzeichnis ● | Aufgabenstellung ● | Konzept ● | Prototyp ● | Hardware + Software ● | Auswertung ● | Resultate ● | Demonstration ● | Verteidigung

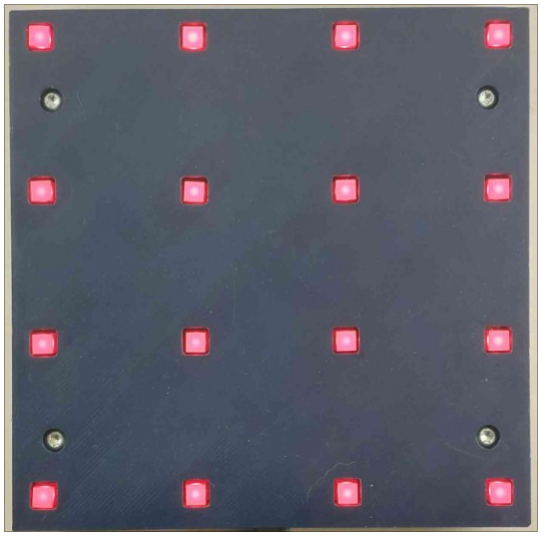
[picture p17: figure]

## Aufgabenstellung

- Messsystem mit LEDs
- Kamera schaut auf Messsystem
- Messsystem verändert LEDs über Zeit
- Software kann aus Video Zeitverhalten analysieren
- Messsystem mit PC über serielle Schnittstelle verbinden

## Konzept

- eine wandernde LED abgestimmt auf FPS der Kamera
- Position LEDs → Zeitstempel
- Anzahl LEDs → Beleuchtungszeit

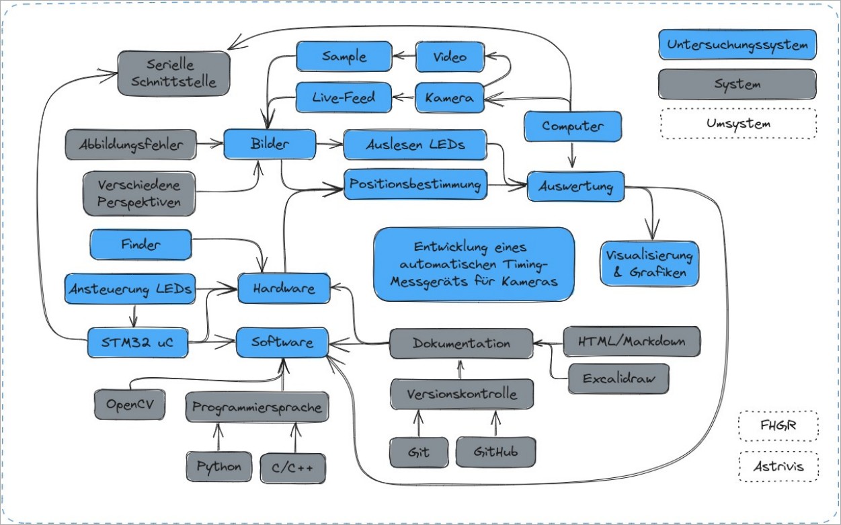
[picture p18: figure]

## Prototyp – PWM / Testkalibration

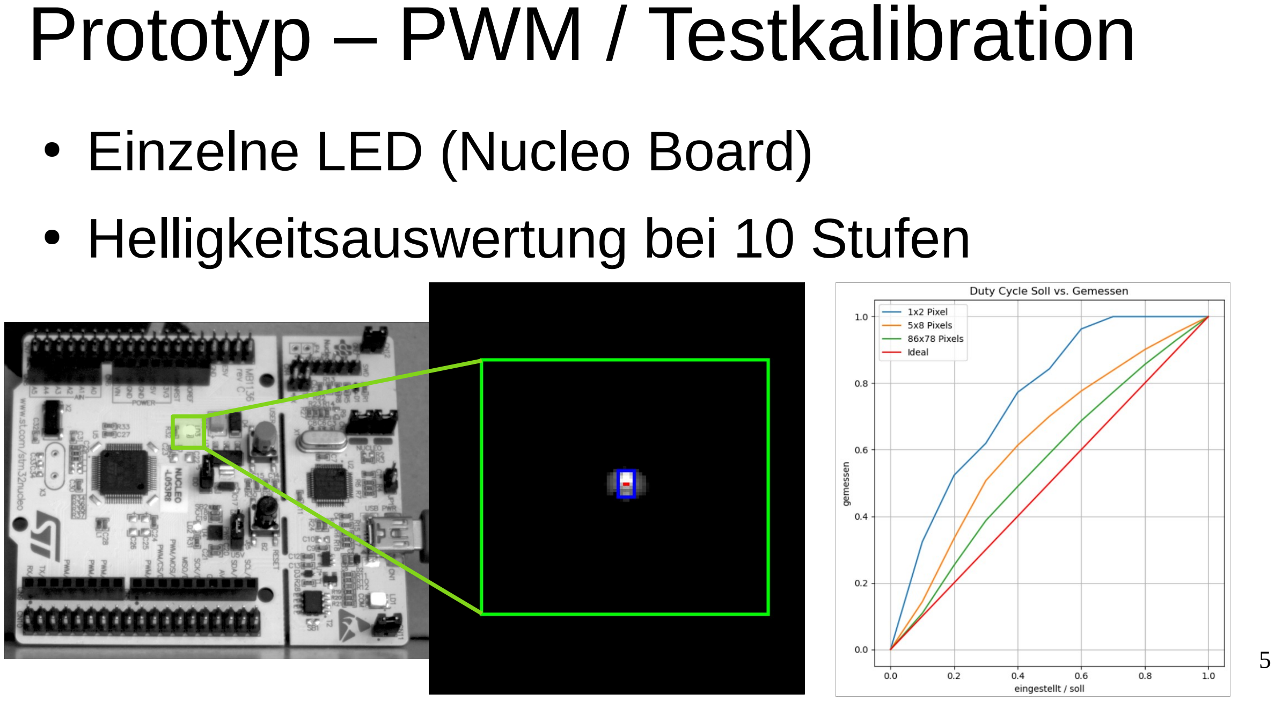
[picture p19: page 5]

- Einzelne LED (Nucleo Board)
- Helligkeitsauswertung bei 10 Stufen

## Prototyp – Schieberegister

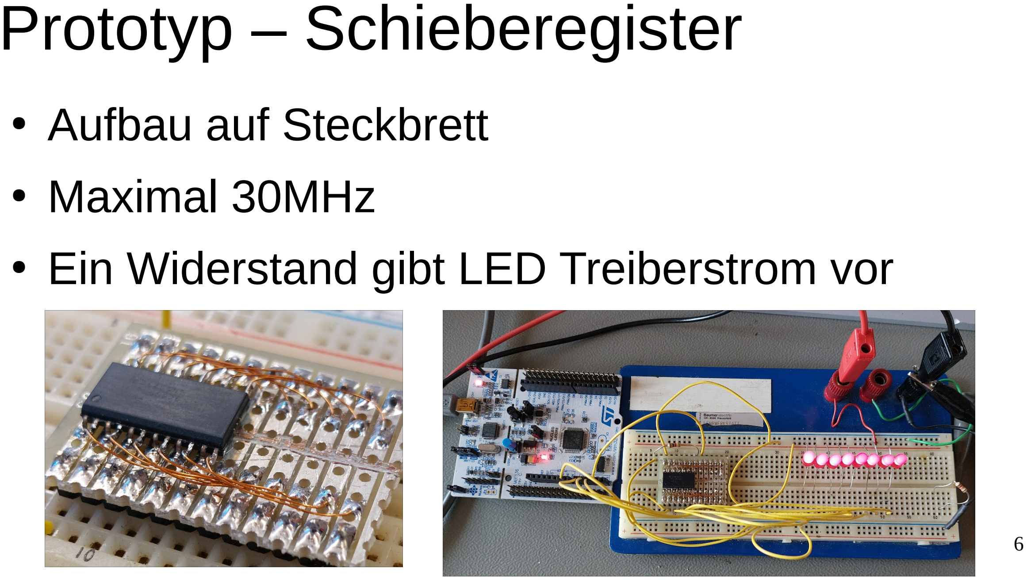
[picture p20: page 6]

- Aufbau auf Steckbrett
- Maximal 30MHz
- Ein Widerstand gibt LED Treiberstrom vor

## Hardware – Schema & Layout

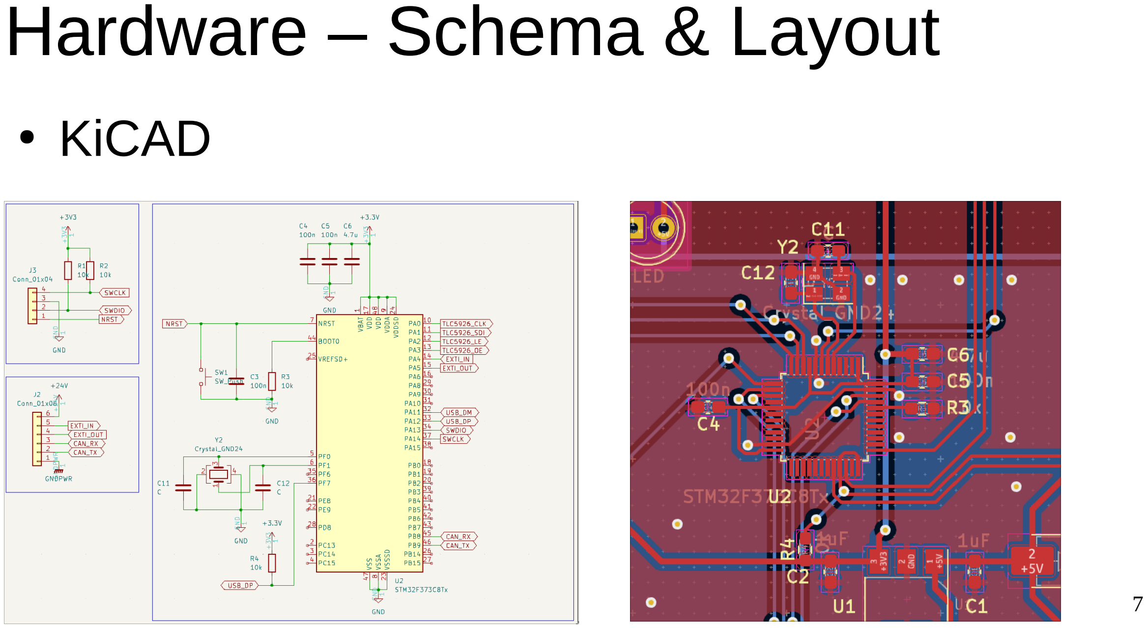
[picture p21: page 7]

- KiCAD

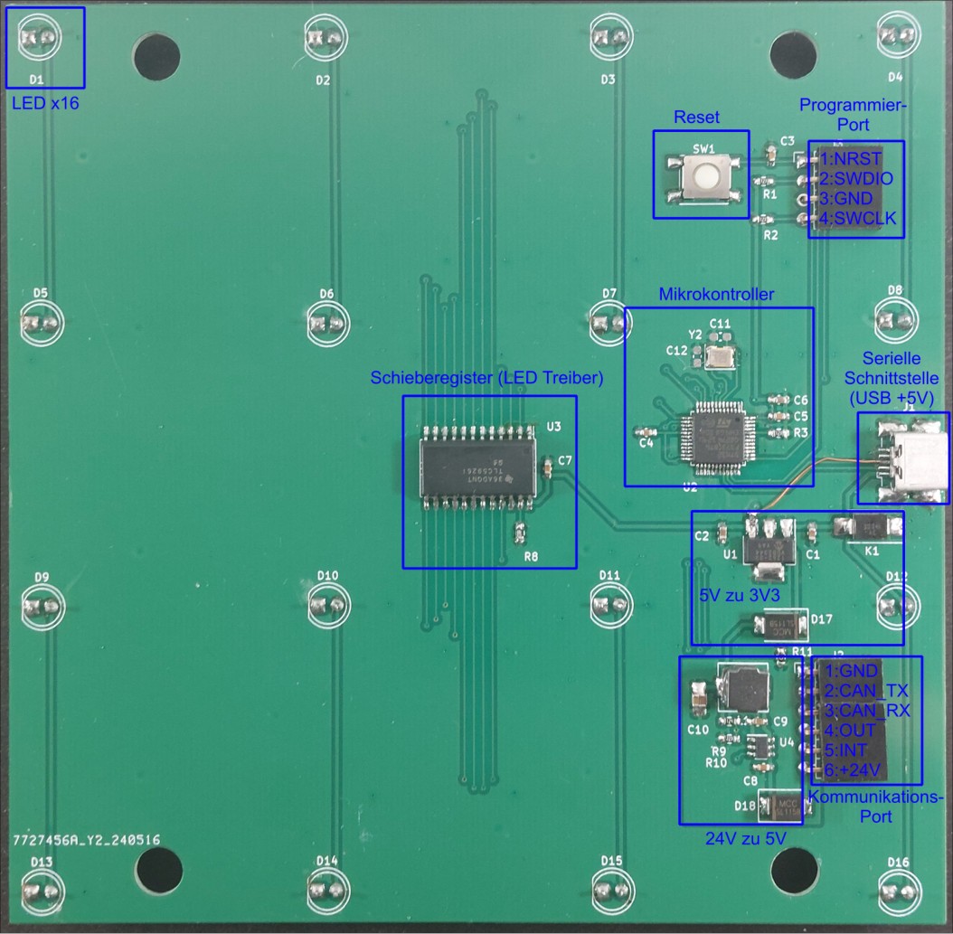
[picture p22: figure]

## Hardware – PCB

- Bestellt bei JLCPCB

## Hardware – Gehäuse

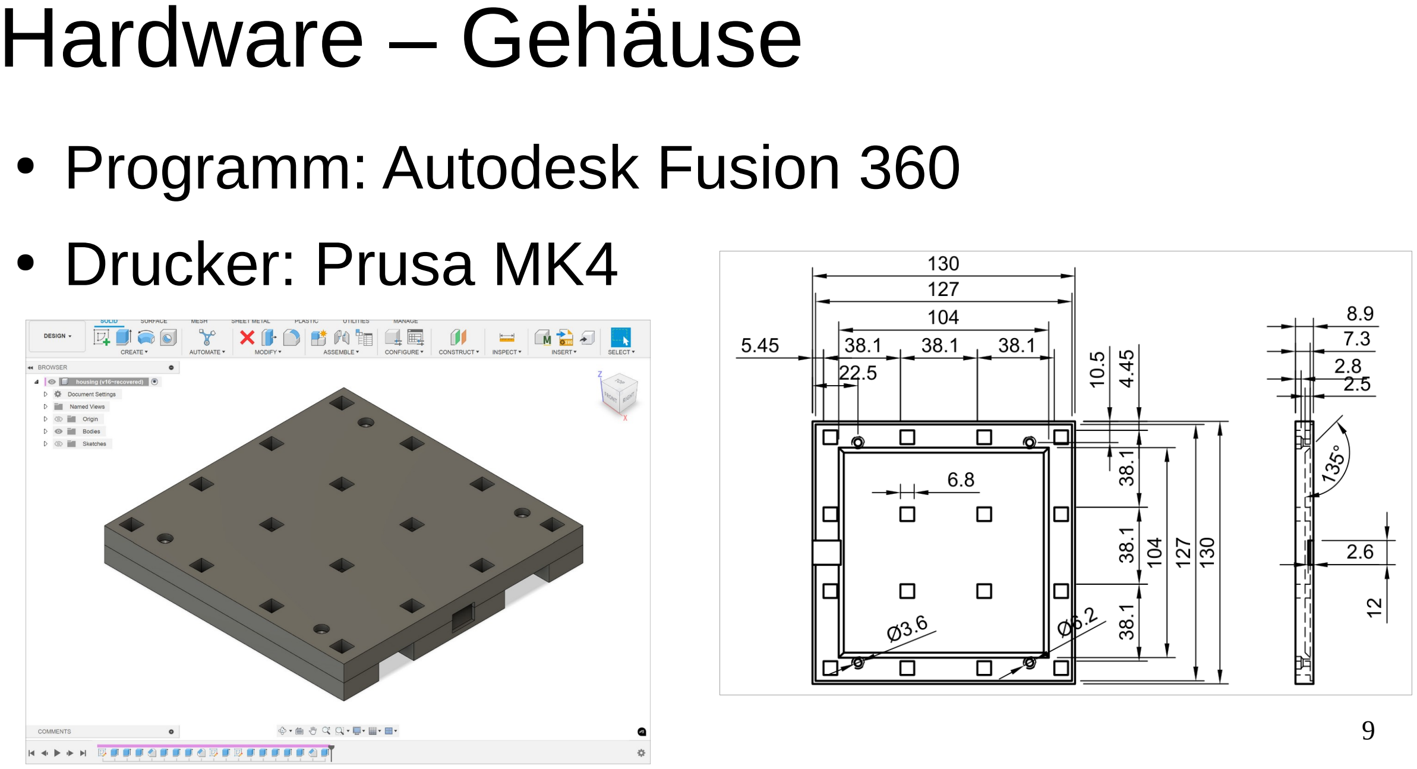
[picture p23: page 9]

- Programm: Autodesk Fusion 360
- Drucker: Prusa MK4

## Software – Mikrokontroller (1)

- Software auf Kalibrationsgerät
- Programmiersprache: C
- Entwicklungsumgebung: STM32CubeIDE
- Steuerung über serielle Schnittstelle

## Software – Mikrokontroller (2)

- Timer (Prescaler + Auto-Reload)
- Schieberegister → eine LED
- (Demonstration)

f

timer=

f
system
(PSC+1)⋅(ARR+1)

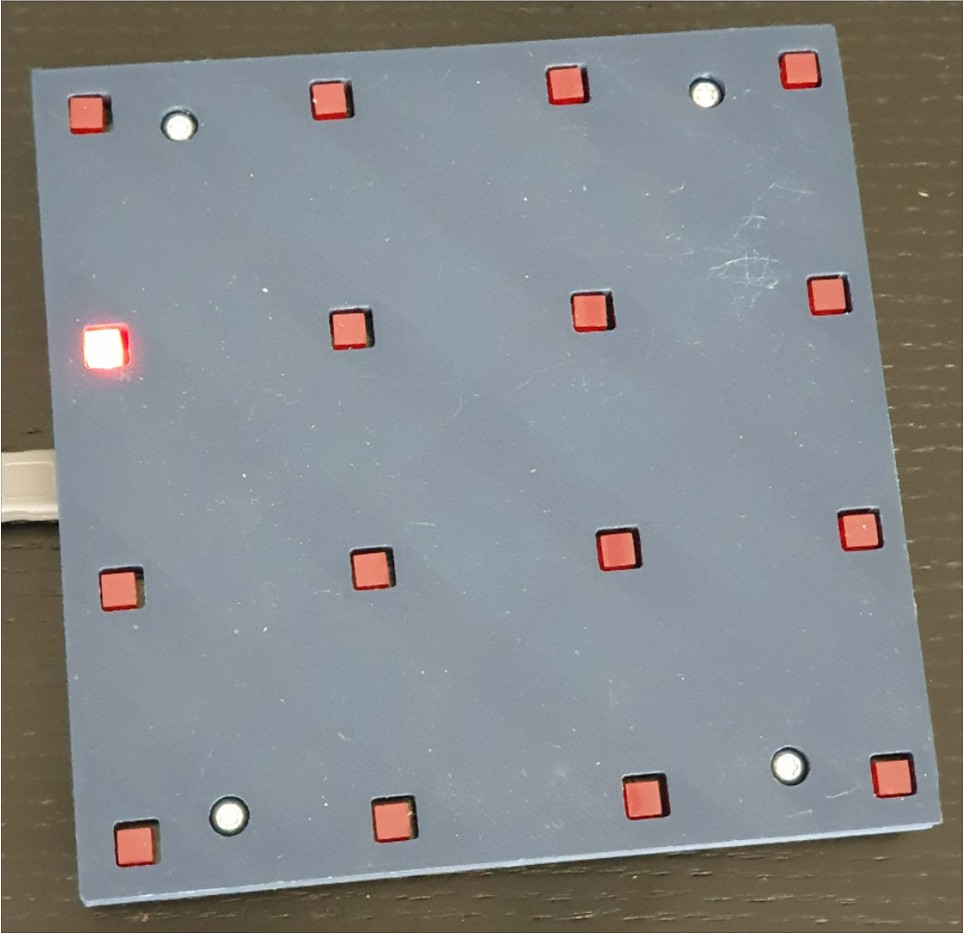
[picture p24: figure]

## Software – Komplette Ansteuerung

- (Beispiel) Software auf PC
- Programmiersprache: C/C++
- Ansteuerung von Kamera + Kalibrationsgerät
- Bibliotheken: opencv, ueye (Kamera)
- (Demonstration am Schluss)

## Software – Auswertung

- Software auf PC
- Programmiersprache: Python
- Bibliotheken: opencv, numpy, scipy, matplotlib
- (Demonstration am Schluss)

## Auswertung – Funktionsprinzip

- Änderung Position → Änderung FPS
- Breite der LEDs → Belichtungszeit
- Anordnung der LEDs “im Kreis”


## Auswertung – Datengenerierung (1)

- FPS Kalibrationsgerät ≠ Kamera
- Maximal einstellbare FPS = 4.5kHz
- Ganzes LED-Feld ausgeschaltet aber im Bild der Kamera
- Beginnen mit Filmen

n=

1
2⋅|1−

f K
f G

## Auswertung – Datengenerierung (2)

1) Alle LEDs aus
2) Alle LEDs an
3) Orientierungsmuster
4) Systemfrequenz
5) Prescaler (Timer)
6) Auto-Reload (Timer)
7) Anzahl PWM Stufen
8) PWM Stufen
9) Alle LEDs aus
10) Wandernde LED

Übertragung von Einstellungen → Video

(Video)

## Auswertung – Datengenerierung (3)

- Filmen beenden
- Messgerät evtl. Ausschalten
- Auswertung mit Python
- PC → Zugriff auf Video

## Auswertung – Positionsdetektion (1)


## Auswertung – Positionsdetektion (2)


## Auswertung – Positionsdetektion (3)


## Auswertung – Kalibration (1)


## Auswertung – Kalibration (2)


## Resultate – gut abgestimmt


## Resultate – schlecht abgestimmt


## Resultate – Rolling Shutter (Video)


## Open source

- GitHub
- https://github.com/rseitz01/fhgr-bachelorthesis-camera-calibration (https://github.com/rseitz01/fhgr-bachelorthesis-camera-calibration)


## Demonstration

Entwicklung eines automatischen Timing-Messgeräts für Kameras

30.08.2024
Raphael Seitz

## Vielen Dank für eure Aufmerksamkeit

Entwicklung eines automatischen Timing-Messgeräts für Kameras

30.08.2024
Raphael Seitz

## Verteidigung

Entwicklung eines automatischen Timing-Messgeräts für Kameras

30.08.2024
Raphael Seitz

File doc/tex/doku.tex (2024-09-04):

\makeatletter
\input{packages_and_configuration.cls}
\makeatother

\begin{document} %{{{
\input{title}

\newpage
\tableofcontents
\newpage

% TODO TODO TODO

\section{Abkürzungsverzeichnis}
\input{abbrev}

\section{Einleitung}
\subfile{einleitung.tex}

\section{Hauptteil}
\subfile{hauptteil.tex}

\section{Schlussteil}
\subfile{schlussteil.tex}

\section{Quellenverzeichnis}
\printbibliography[heading=none]
%\subfile{references}

\RemoveFromHook{cmd/section/before}{\clearpage}
\section{Abbildungs- \& Tabellenverzeichnis}
\listoffigures
\listoftables

\clearpage
\section{Anhang}
\subfile{anhang.tex}

\clearpage
\section*{Selbstständigkeitserklärung}
\subfile{selbst.tex}

% END: Anhang }}}

\end{document} %}}}

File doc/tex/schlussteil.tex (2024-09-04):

% INHALT: {{{
% In den Schlussteil der Arbeit gehören eine Zusammenfassung der wichtigsten Ergebnisse,
% die Interpretation der Resultate und der Vergleich mit eventuell bereits vorhandenen Resultaten.
% Hinzu kommt eine kritische Beurteilung der eigenen Arbeit (Fragestellung und methodisches Vorgehen im Vergleich mit den erreichten Ergebnissen),
% offene Fragen und ein Ausblick (Hinweise auf weiterführende Themenstellungen).
% }}}

\subsection{Zusammefassung der Ergebnisse}

\begin{longtable}[l]{ @{} >{\RaggedRight\hspace{0pt}} lp{.96\linewidth} @{} }
    \textbullet & Die Kodierung der Zeit geschieht über Änderungen in der Position der LEDs (\secref{sec:Zentrum-def-laufenden-Leuchtdiode}).
    \\\textbullet & Die Kodierung der Belichtungszeit ist ablesbar aus der Anzahl an aktiven LEDs (\secref{sec:Breite-der-laufenden-Leuchtdiode}).
    \addtocounter{table}{-1}\setcounter{enumi}{0}
\end{longtable}

\subsection{Interpretation der Resultate}

Die in \appref{app:results} gezeigten Resultate haben diverse Einflüsse:
\begin{longtable}[l]{ @{} >{\RaggedRight\hspace{0pt}} lp{.96\linewidth} @{} }
    \textbullet & Eine Änderung der Belichtungszeit über die Messdauer spielt vermutlich zusammen mit sich ändernen Lichtverhältnissen, denn dies ist sehr anfällig darüber.
    \\\textbullet & Die FPS bleiben in der Regel sehr gleichmässig, bei Ausreissern gingen entweder Bilder verloren (weniger FPS),
    die Frequenzen waren nicht gut abgestimmt (weniger oder mehr FPS), 
    die Kamera verlor sehr viele Bilder (mehr FPS)
    oder die Kamera wiederholte gewisse Bilder (mehr FPS).
    Ein Fall, welcher nicht detektiert werden kann, ist wenn ein Vielfaches von \eqref{eq:Delta-f} Bildern verloren gehen.
    \\\textbullet & Wenn die Frequenzen zwischen Messgerät und Kamera gut eingestellt sind, weicht die ermittelte FPS
    in der Regel weniger als 0.3\% von der vorgegebenen ab. Die grösste Abweichung ist sichtbar in den Resultaten \hyperlinkXY{hyp:k-aos-285}.
    \\\textbullet & Die Kalibration verbessert in der Regel die Belichtungszeit zu den Winkeln, was die Effektivität dessen darstellt.
    Je regelmässiger dies ist, desto Wahrheitsgetreuer sind alle Resultate bei einer stabilen Kamera.
    \addtocounter{table}{-1}\setcounter{enumi}{0}
\end{longtable}

\subsection{Kritische Beurteilung}

Verschiedene Punkte, welche mit dem aktuellen Messgerät und der aktuellen Auswertungssoftware nicht funktionieren, sind folgende:

\begin{longtable}[l]{ @{} >{\RaggedRight\hspace{0pt}} lp{.96\linewidth} @{} }
% - kein Rolling shutter möglich
    \textbullet & Bei Videos mit Rolling Shutter liefert die Auswertesoftware, wenn überhaupt das Orientierungsmuster erkannt wird, falsche Resultate.
% - keine 100% belichtungszeit möglich
    \\\textbullet & Bei 100\% Belichtungszeit von Bildern kann keine Position im \hyperlinkXY{hyp:mode-rider} Modus entdeckt werden.
    Dies kann zum Beispiel bei einer Hochgeschwindigkeitskamera der Fall sein.
% - falls 1/FPS (bzw die Hälfte davon) Bilder verloren gehen -> "kein" fehler...
    \\\textbullet & Es ist wichtig, dass die Frequenz des Messgerätes korrekt eingestellt ist (\secref{sec:Gut-Eingestellt}).
% - CAN-Bus noch nicht
    \\\textbullet & Kommunikation zwischen Messgeräten ist (noch) nicht implementiert.
% - Speichern der Einstellungen bei shutdown im gerät?
    \\\textbullet & Vorgenommene Konfigurationen gehen beim Reset oder Hochfahren verloren.
% - keine variable FPS / belichtungszeiten -> anfällig gegen sich ändernde Belichtungszeiten beim Aufnehmen
    \\\textbullet & Um die Korrektheit der Auswertung zu erhöhen ist es sehr wichtig, dass sich die Lichtverhältnisse über die Zeit nicht ändern.
    % ENDE
    \addtocounter{table}{-1}\setcounter{enumi}{0}
\end{longtable}

\subsection{Offene Fragen}

Eine Auswertung eines Mehrkamerasystems oder Präsenz von mehrfachen Messgeräte je Video konnte aus Zeitgründen nicht näher betrachtet werden.

Ansätze um LEDs im Raum zu tracken \cite{6044360} konnten aus Zeitgründen nicht angeschaut werden.
%denn das zu entwickelnde Gerät und die zu untersuchende Kamera bleiben statisch im Raum.

\subsection{Ausblick}

Es wurde erwähnt, dass die Auswertung nicht für Kameras mit Rolling Shutter funktioniert.
Würde die Orientierung des Messgerätes zur Kamera respektiert und die Auswertungssoftware darauf abgestimmt und erweitert werden,
könnte so eventuell trotzdem eine Auswertung vonstatten gehen.

Würden zwei oder mehr Kameras ein Messgerät zur gleichen Zeit filmen, könnte mit einer erweiterten Auswertungssoftware
die Stabilität der Kameras oder der Auswertungssoftware näher beurteilt werden.

Bei zwei oder mehr im Bild aufgenommenen Messgeräten,
deren Frequenzen leicht versetzt eingestellt sind, könnte
$s_\text{maxskip}$ \eqref{eq:s_maxskip} erhöht werden.

Um die Auswertungssoftware auf Korrektheit zu Überprüfen, könnten anstelle von aufgenommenen, kontrolliert Computer-Generierte Videos erstellt 
und ausgewertet werden.

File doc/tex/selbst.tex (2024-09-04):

``\underline{Erklärung}: Ich erkläre hiermit, dass ich diese Arbeit selbstständig verfasst
und keine anderen als die angegebenen Quellen und erlaubten
Hilfsmittel benutzt habe, einschliesslich der Verwendung von KI-Systemen.
Alle Stellen, die wörtlich oder sinngemäss aus Quellen entnommen worden sind,
habe ich als solche gekennzeichnet. Ich bin den Vorgaben des Leitfadens
wissenschaftliches Arbeiten gefolgt. Mir ist bekannt, dass andernfalls die
Hochschulleitung zum Entzug der aufgrund meiner Arbeit verliehenen Qualifikation
oder des für meine Arbeit verliehenen Titels berechtigt ist.''

\hfill \break

\noindent\begin{minipage}[t]{.497\linewidth}\vspace{0pt}

\begin{centering}
Ort, Datum
\end{centering}

\end{minipage}
\noindent\begin{minipage}[t]{.497\linewidth}\vspace{0pt}

\begin{centering}
Unterschrift
\end{centering}

\end{minipage}

\thispagestyle{empty} % remove page number

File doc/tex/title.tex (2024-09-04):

\title{Entwicklung eines automatischen Timing-Messgeräts für Kameras
\\\large
\hfill \break
Pho21 Bachelorthesis der Fachhochschule Graubünden \\in Zusammenarbeit mit Astrivis Technologies Ltd
}

\author{}

\maketitle

\vspace{-0.5cm}

\begin{figure}[!h]
    \centering
    
\end{figure}

\vspace{0.5cm}

\begin{longtable}[l]{ @{} >{\RaggedRight\hspace{0pt}} p{.25\linewidth}p{.7\linewidth} @{} }
    Autor:
    & Raphael Seitz
    \\& Obstgartenstrasse 18
    \\& 8512 Thundorf
    \\& Tel: +41 76 559 34 66
    \\& E-Mail: raphael.seitz18@gmail.com
    \\ 
    \\ Referent:
    & Prof. Dr. Philipp Roebrock, FH Graubünden,
    \\& Institut für Photonics und Robotics

    \\ Korreferent:
    & Olivier Saurer, Astrivis Technologies Ltd

    \\ Studiengang:
    & BSc Photonics, Institut für Photonics und Robotics, FH Graubünden

    \\ Start der Thesis: & 19.02.2024
    \\ Abgabe der Thesis: & 09.08.2024
    % ENDE
    \addtocounter{table}{-1}\setcounter{enumi}{0}
\end{longtable}

\thispagestyle{empty} % remove page number

\clearpage
\begin{abstract}
    Viele Computervision-Anwendungen sind auf ein korrektes Timing der aufgenommenen Bilder angewiesen.
    Es wurde ein Timing-Messgerät entwickelt, mit welchem die Bildwiederholrate und Belichtung über die Zeit detektiert werden können.
    Dies geschieht über das Analysieren der Änderung vom Wandern lassen einer LED in einer 4x4 Anordnung.
    Das Gerät lässt sich über ein USB-Kabel mit einem Computer verbinden und über die serielle Schnittstelle konfigurieren.
    Während dem Messvideo muss die Frequenz des Messgerätes leicht von der Kamera abweichen und die Position und die Lichtverhältnisse so unveränderlich wie möglich bleiben.
    Die Auswertung geschieht im Nachhinein durch eine Software geschrieben in Python.
    Darin wird automatisch die Position des Gerätes gefunden und die Helligkeiten der LEDs kalibriert, um robuste Resultate zu erhalten.

    Dies funktioniert erst für ein Messystem bestehend aus je einer Kamera mit Global Shutter und einem Messgerät.
    Eine Kommunikation zwischen Messgeräten ist gegeben aber noch nicht implementiert.
    Die Auswertung kann und darf derzeit nur ein Messgerät detektieren.
    Im Fall, wenn zwei Kameras dasselbe Messgerät zur gleichen Zeit filmen, geschieht während der Auswertung kein Austausch der Messwerte zwischen den einzelnen Videos.

\end{abstract}


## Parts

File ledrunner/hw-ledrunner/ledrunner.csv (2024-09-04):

Source: | /home/hp/dev/FHGR/fhgr-thesis-camera-calibration/ledrunner/hw-ledrunner/ledrunner.kicad_sch
Date: | Thu Aug 8 23:49:21 2024
Tool: | Eeschema 7.0.10
Generator: | /usr/share/kicad/plugins/bom_csv_grouped_by_value.py
Component Count: | 49
Collated Components:
Item | Qty | Reference(s) | Value | LibPart | Footprint | Datasheet | DNP
1 | 2 | C1, C2 | 1uF | Device:C | Capacitor_SMD:C_0603_1608Metric_Pad1.08x0.95mm_HandSolder | ~
2 | 4 | C3, C4, C5, C7 | 100n | Device:C | Capacitor_SMD:C_0603_1608Metric_Pad1.08x0.95mm_HandSolder | ~
3 | 1 | C6 | 4.7u | Device:C | Capacitor_SMD:C_0603_1608Metric_Pad1.08x0.95mm_HandSolder | ~
4 | 1 | C8 | 2.2uF | Device:C | Capacitor_SMD:C_0603_1608Metric_Pad1.08x0.95mm_HandSolder | https://www.digikey.ch/de/products/detail/tdk-corporation/CGA3E2X7R1H222K080AA/2443138
5 | 1 | C9 | 100nF | Device:C | Capacitor_SMD:C_0603_1608Metric_Pad1.08x0.95mm_HandSolder | ~
6 | 1 | C10 | 22uF | Device:C | Capacitor_SMD:C_Elec_5x5.4 | ~
7 | 2 | C11, C12 | C | Device:C | Capacitor_SMD:C_0603_1608Metric_Pad1.08x0.95mm_HandSolder | ~
8 | 16 | D1, D2, D3, D4, D5, D6, D7, D8, D9, D10, D11, D12, D13, D14, D15, D16 | LED | Device:LED | LED_THT:LED_D5.0mm_FlatTop | https://www.digikey.ch/de/products/detail/lumex-opto-components-inc/SSL-LX5573ID/519609
9 | 2 | D17, D18 | D_Schottky | Device:D_Schottky | Diode_SMD:D_SMB | https://www.digikey.ch/de/products/detail/micro-commercial-co/SL115B-TP/16032650
10 | 1 | J1 | USB_B_Mini | Connector:USB_B_Mini | Connector_USB:USB_Mini-B_Wuerth_65100516121_Horizontal | https://www.digikey.ch/de/products/detail/hirose-electric-co-ltd/UX60SC-MB-5ST-80/2004569
11 | 1 | J2 | Conn_01x06 | Connector_Generic:Conn_01x06 | Connector_PinHeader_2.54mm:PinHeader_1x06_P2.54mm_Horizontal | ~
12 | 1 | J3 | Conn_01x04 | Connector_Generic:Conn_01x04 | Connector_PinHeader_2.54mm:PinHeader_1x04_P2.54mm_Horizontal | ~
13 | 1 | K1 | D_TVS | Device:D_TVS | Diode_SMD:D_SMB_Handsoldering | https://www.digikey.ch/de/products/detail/diodes-incorporated/SMBJ5-0CA-13-F/749991
14 | 1 | L1 | 33uH | Device:L | Inductor_SMD:L_6.3x6.3_H3 | https://www.digikey.ch/de/products/detail/bourns-inc/SRN6045HA-330M/15219544
15 | 4 | R1, R2, R3, R4 | 10k | Device:R | Resistor_SMD:R_0603_1608Metric_Pad0.98x0.95mm_HandSolder | ~
16 | 1 | R8 | 1k | Device:R | Resistor_SMD:R_0603_1608Metric_Pad0.98x0.95mm_HandSolder | ~
17 | 1 | R9 | 120k | Device:R | Resistor_SMD:R_0603_1608Metric_Pad0.98x0.95mm_HandSolder | ~
18 | 1 | R10 | 22k | Device:R | Resistor_SMD:R_0603_1608Metric_Pad0.98x0.95mm_HandSolder | ~
19 | 1 | R11 | 0R | Device:R | Resistor_SMD:R_0603_1608Metric_Pad0.98x0.95mm_HandSolder | ~
20 | 1 | SW1 | SW_Push | Switch:SW_Push | Button_Switch_SMD:SW_Push_1P1T_NO_6x6mm_H9.5mm | https://www.digikey.ch/de/products/detail/panasonic-electronic-components/EVQ-Q2P02W/762898
21 | 1 | U1 | TC1262-33 | Regulator_Linear:TC1262-33 | Package_TO_SOT_SMD:SOT-223-3_TabPin2 | https://www.digikey.ch/de/products/detail/microchip-technology/TC1262-3-3VDBTR/443194
22 | 1 | U2 | STM32F373C8Tx | MCU_ST_STM32F3:STM32F373C8Tx | Package_QFP:LQFP-48_7x7mm_P0.5mm | http://www.st.com/st-web-ui/static/active/en/resource/technical/document/datasheet/DM00046749.pdf
23 | 1 | U3 | TLC5926IWDR | Custom:TLC5926IWDR | Package_SO:SOIC-24W_7.5x15.4mm_P1.27mm | https://www.digikey.de/de/products/detail/texas-instruments/TLC5926IDWR/2057670
24 | 1 | U4 | ~ | Custom:LMR516xx | Package_TO_SOT_SMD:SOT-23-6 | https://www.digikey.ch/de/products/detail/texas-instruments/LMR51610YFDBVR/22286738
25 | 1 | Y2 | Crystal_GND24 | Device:Crystal_GND24 | Crystal:Crystal_SMD_3225-4Pin_3.2x2.5mm | https://www.jauch.com/downloadfile/57ce74843affc_0f125c609b2336255010/jxs32-180914.pdf

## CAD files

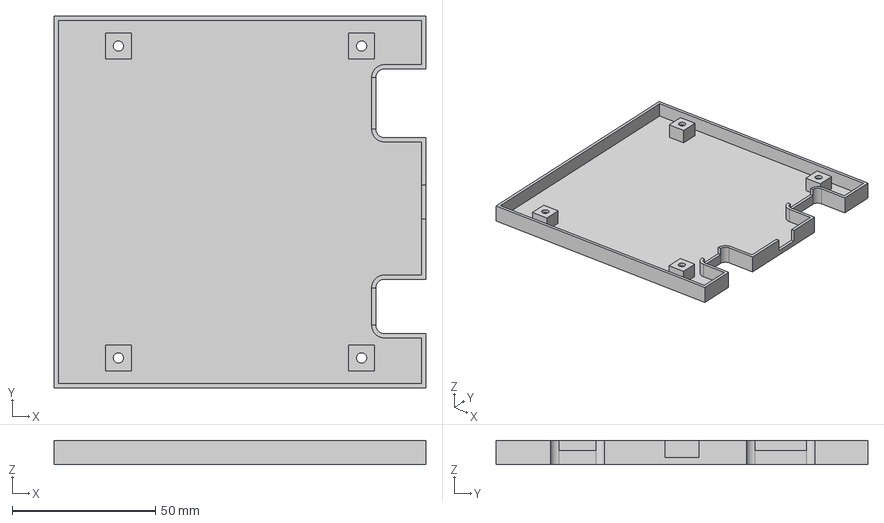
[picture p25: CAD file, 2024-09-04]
ledrunner/housing-ledrunner/housing-bot-v16.step
130.0 x 130.0 x 8.50 mm

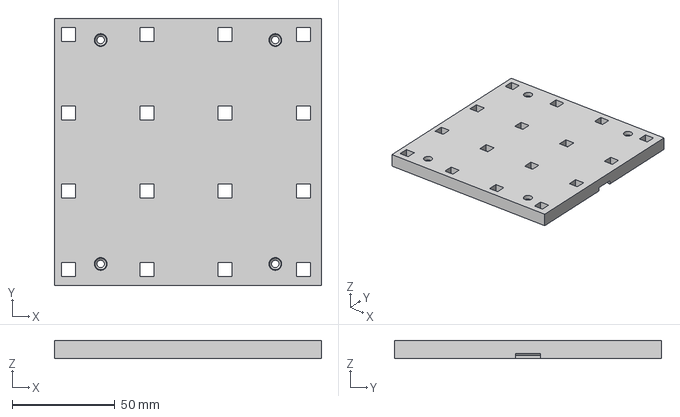
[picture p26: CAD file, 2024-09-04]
ledrunner/housing-ledrunner/housing-top-v16.step
130.0 x 130.0 x 8.90 mm

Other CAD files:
ledrunner/housing-ledrunner/housing-ledrunner.f3d

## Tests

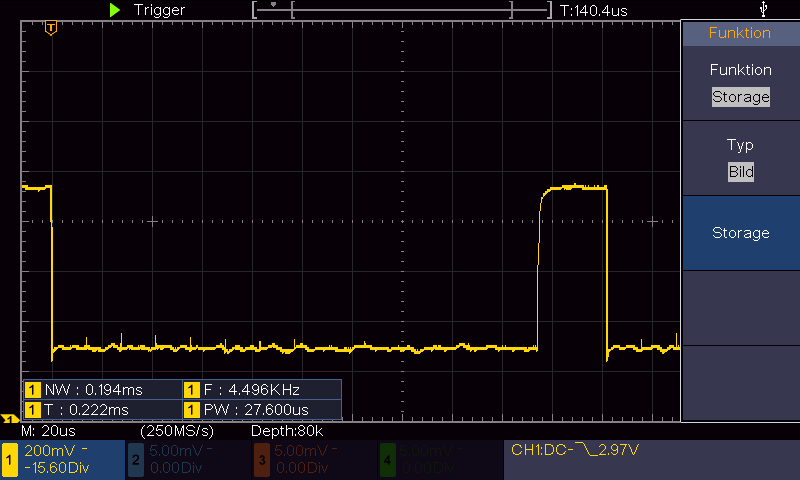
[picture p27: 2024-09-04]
doc/measurements/data_113862.bmp

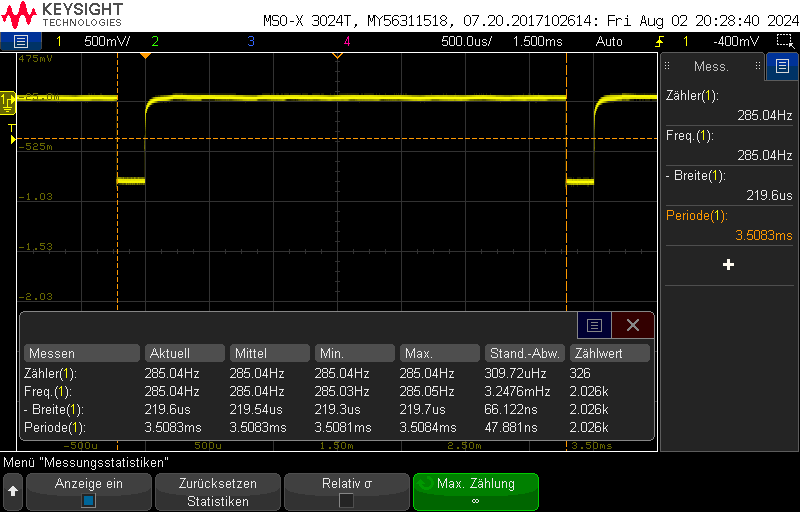
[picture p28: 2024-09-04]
doc/measurements/scope_29.bmp

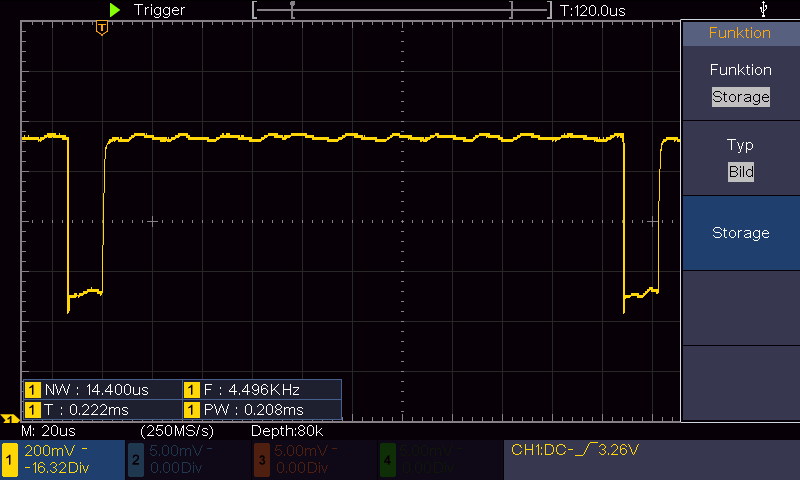
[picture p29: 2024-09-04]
doc/measurements/data_64898.bmp

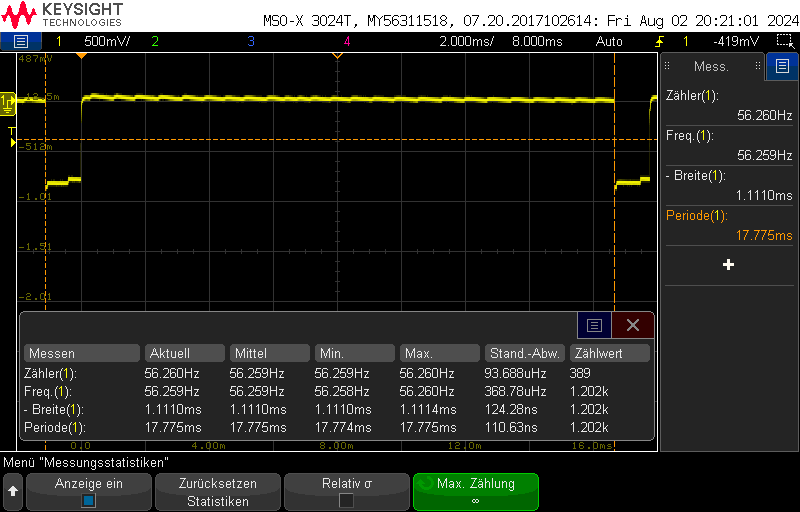
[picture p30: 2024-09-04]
doc/measurements/scope_23.bmp

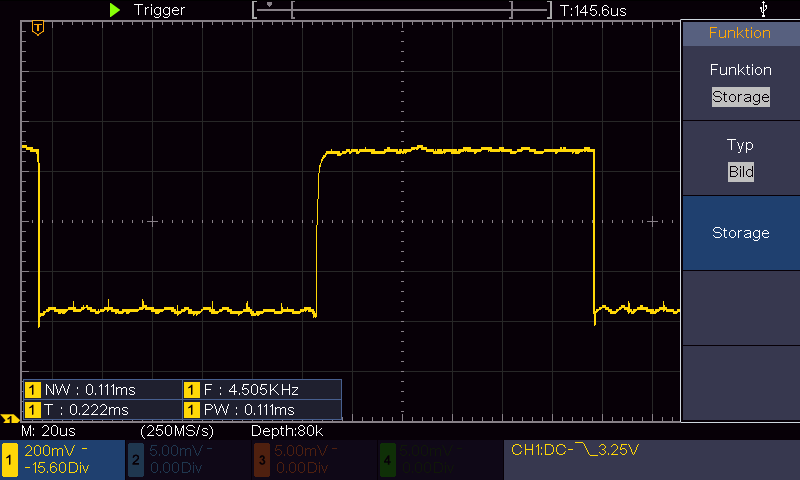
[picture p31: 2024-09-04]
doc/measurements/data_94573.bmp

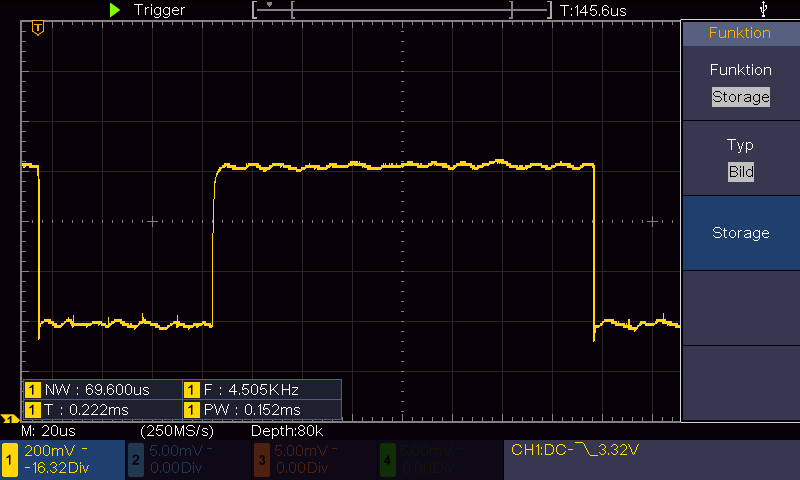
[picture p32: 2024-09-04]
doc/measurements/data_86946.bmp

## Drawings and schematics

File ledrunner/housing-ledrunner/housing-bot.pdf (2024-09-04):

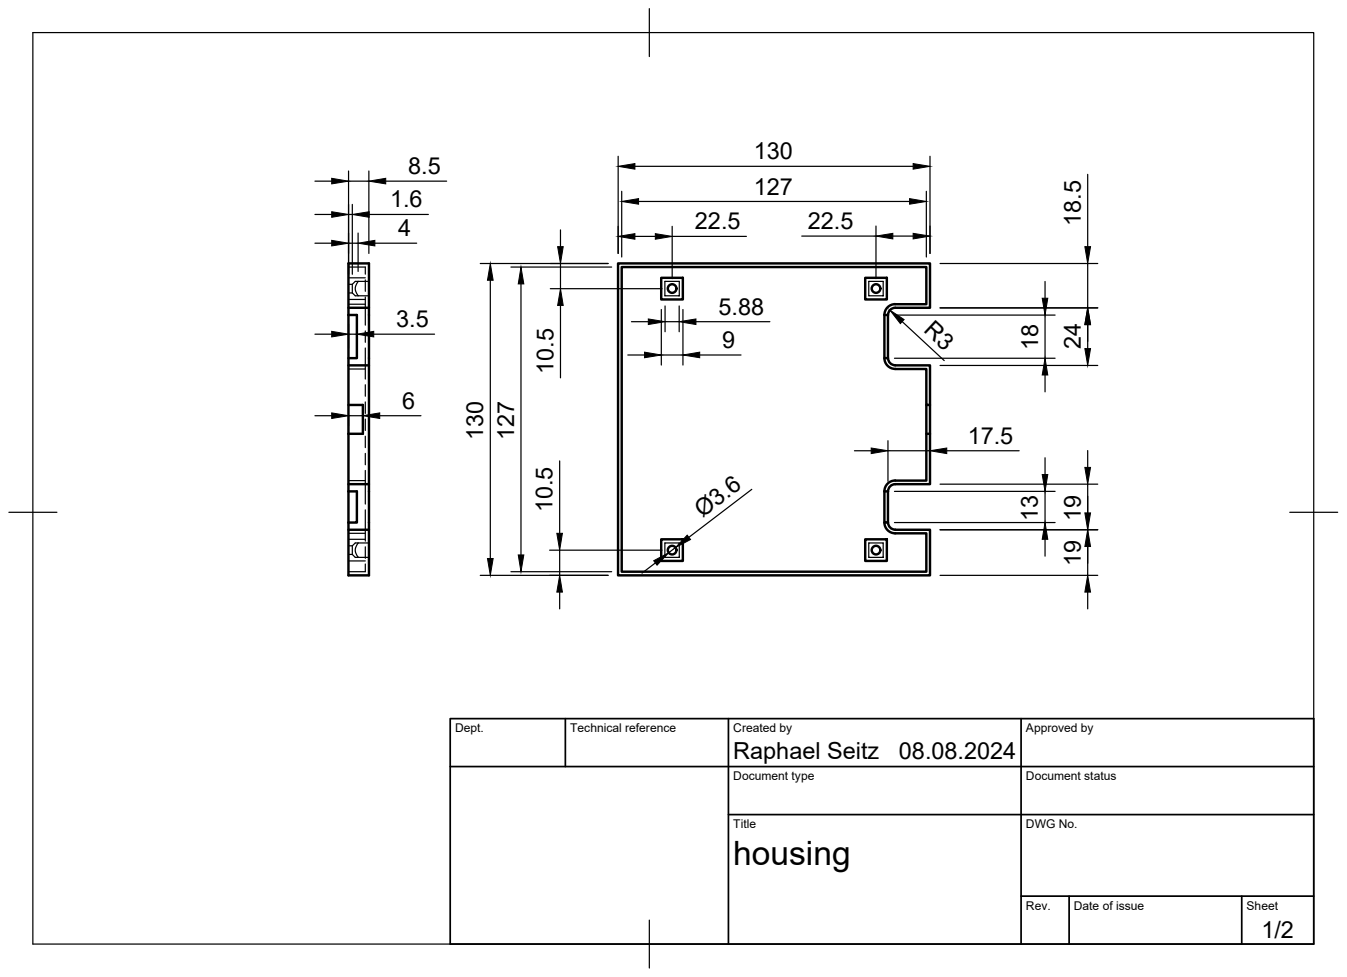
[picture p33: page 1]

Dept. | Technical reference | Created by Raphael Seitz 08.08.2024 | Approved by

Document type | Document status

Title housing | DWG No.

Rev. | Date of issue | Sheet 1/2

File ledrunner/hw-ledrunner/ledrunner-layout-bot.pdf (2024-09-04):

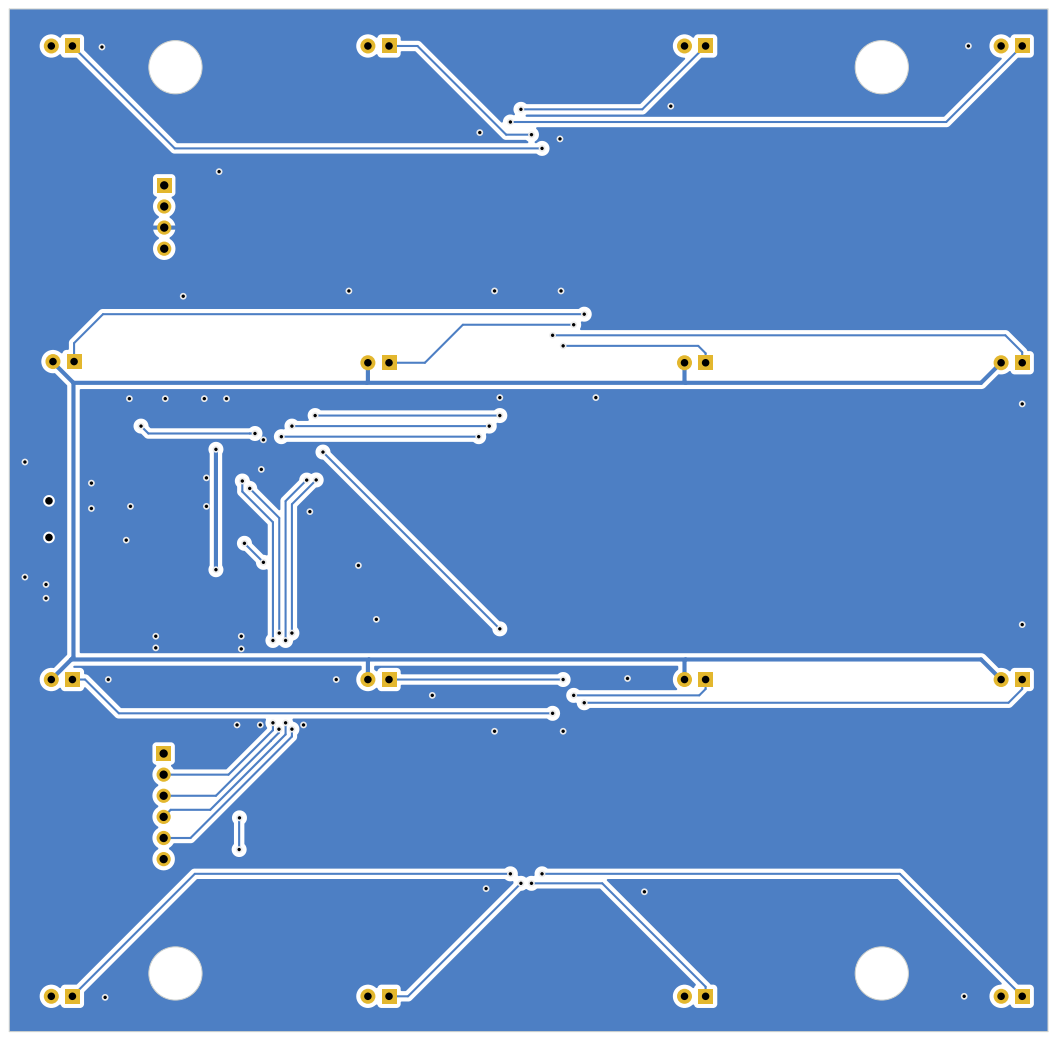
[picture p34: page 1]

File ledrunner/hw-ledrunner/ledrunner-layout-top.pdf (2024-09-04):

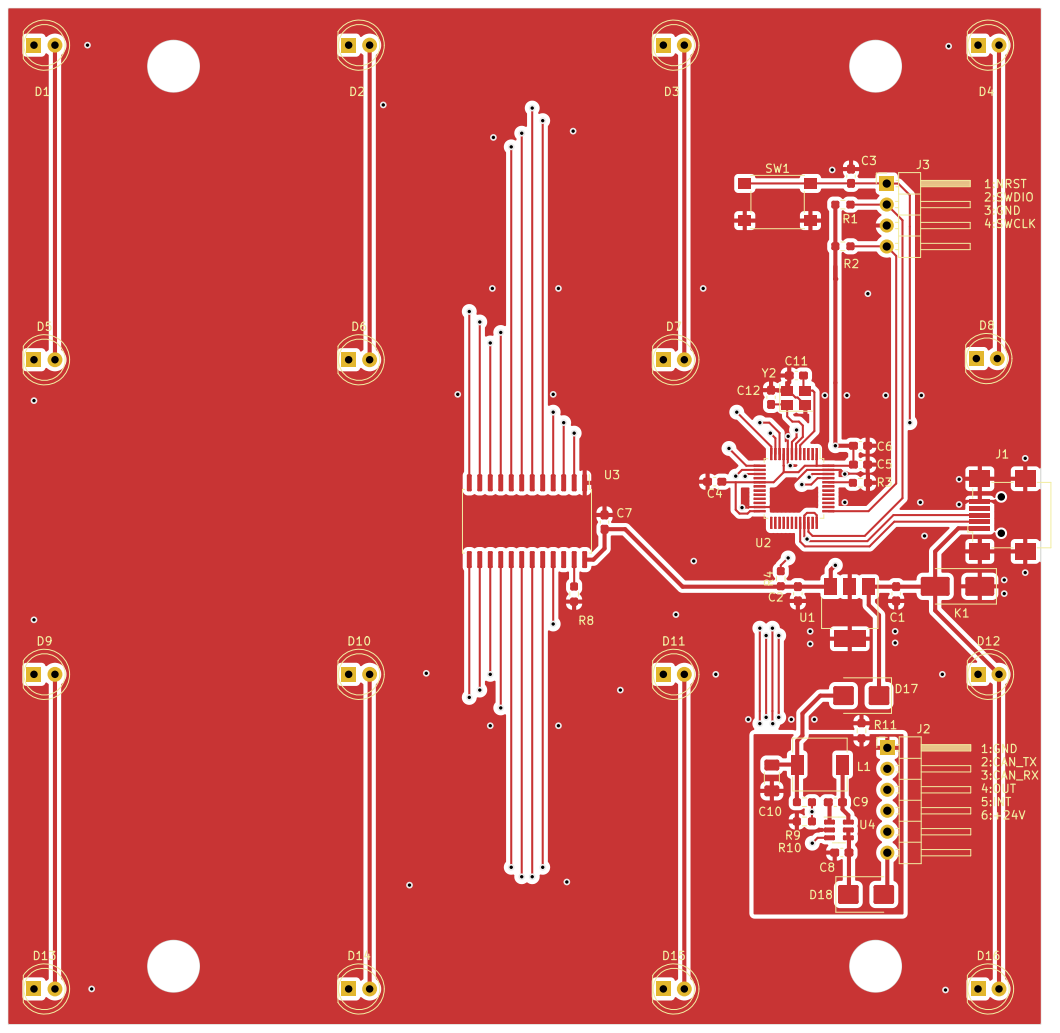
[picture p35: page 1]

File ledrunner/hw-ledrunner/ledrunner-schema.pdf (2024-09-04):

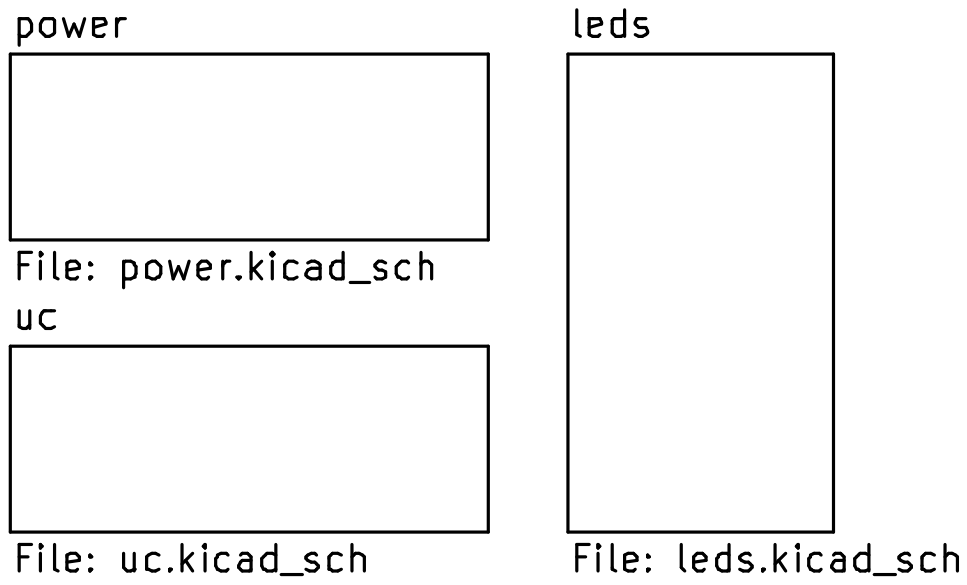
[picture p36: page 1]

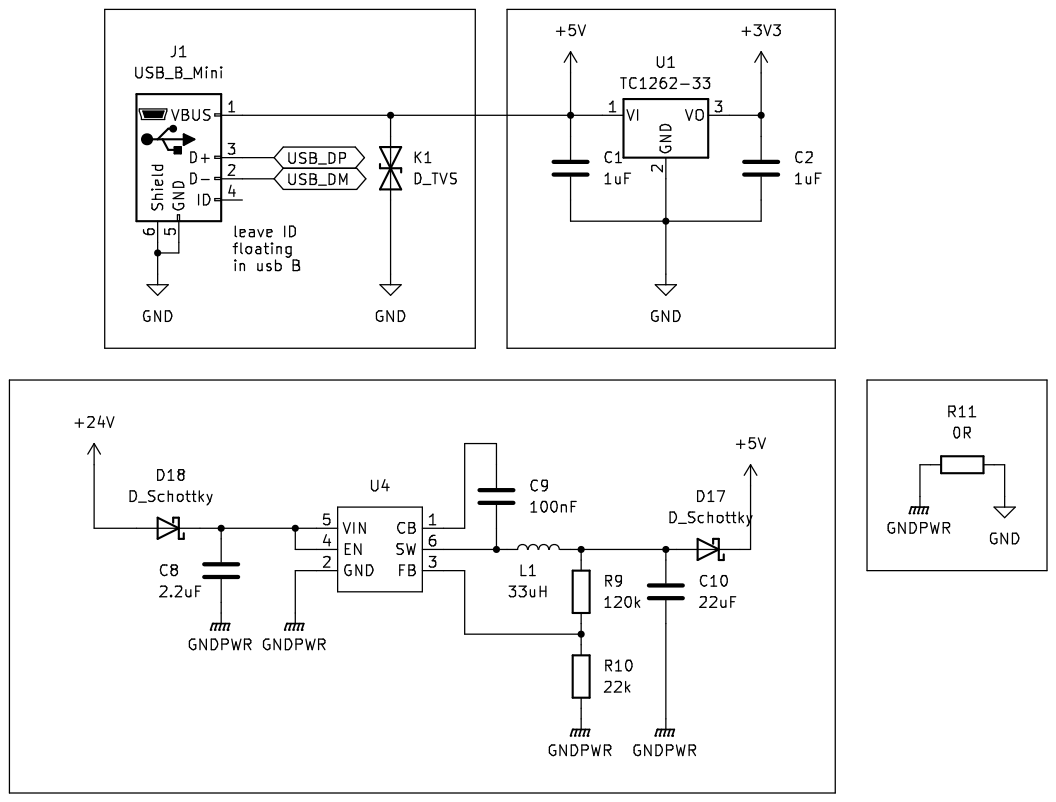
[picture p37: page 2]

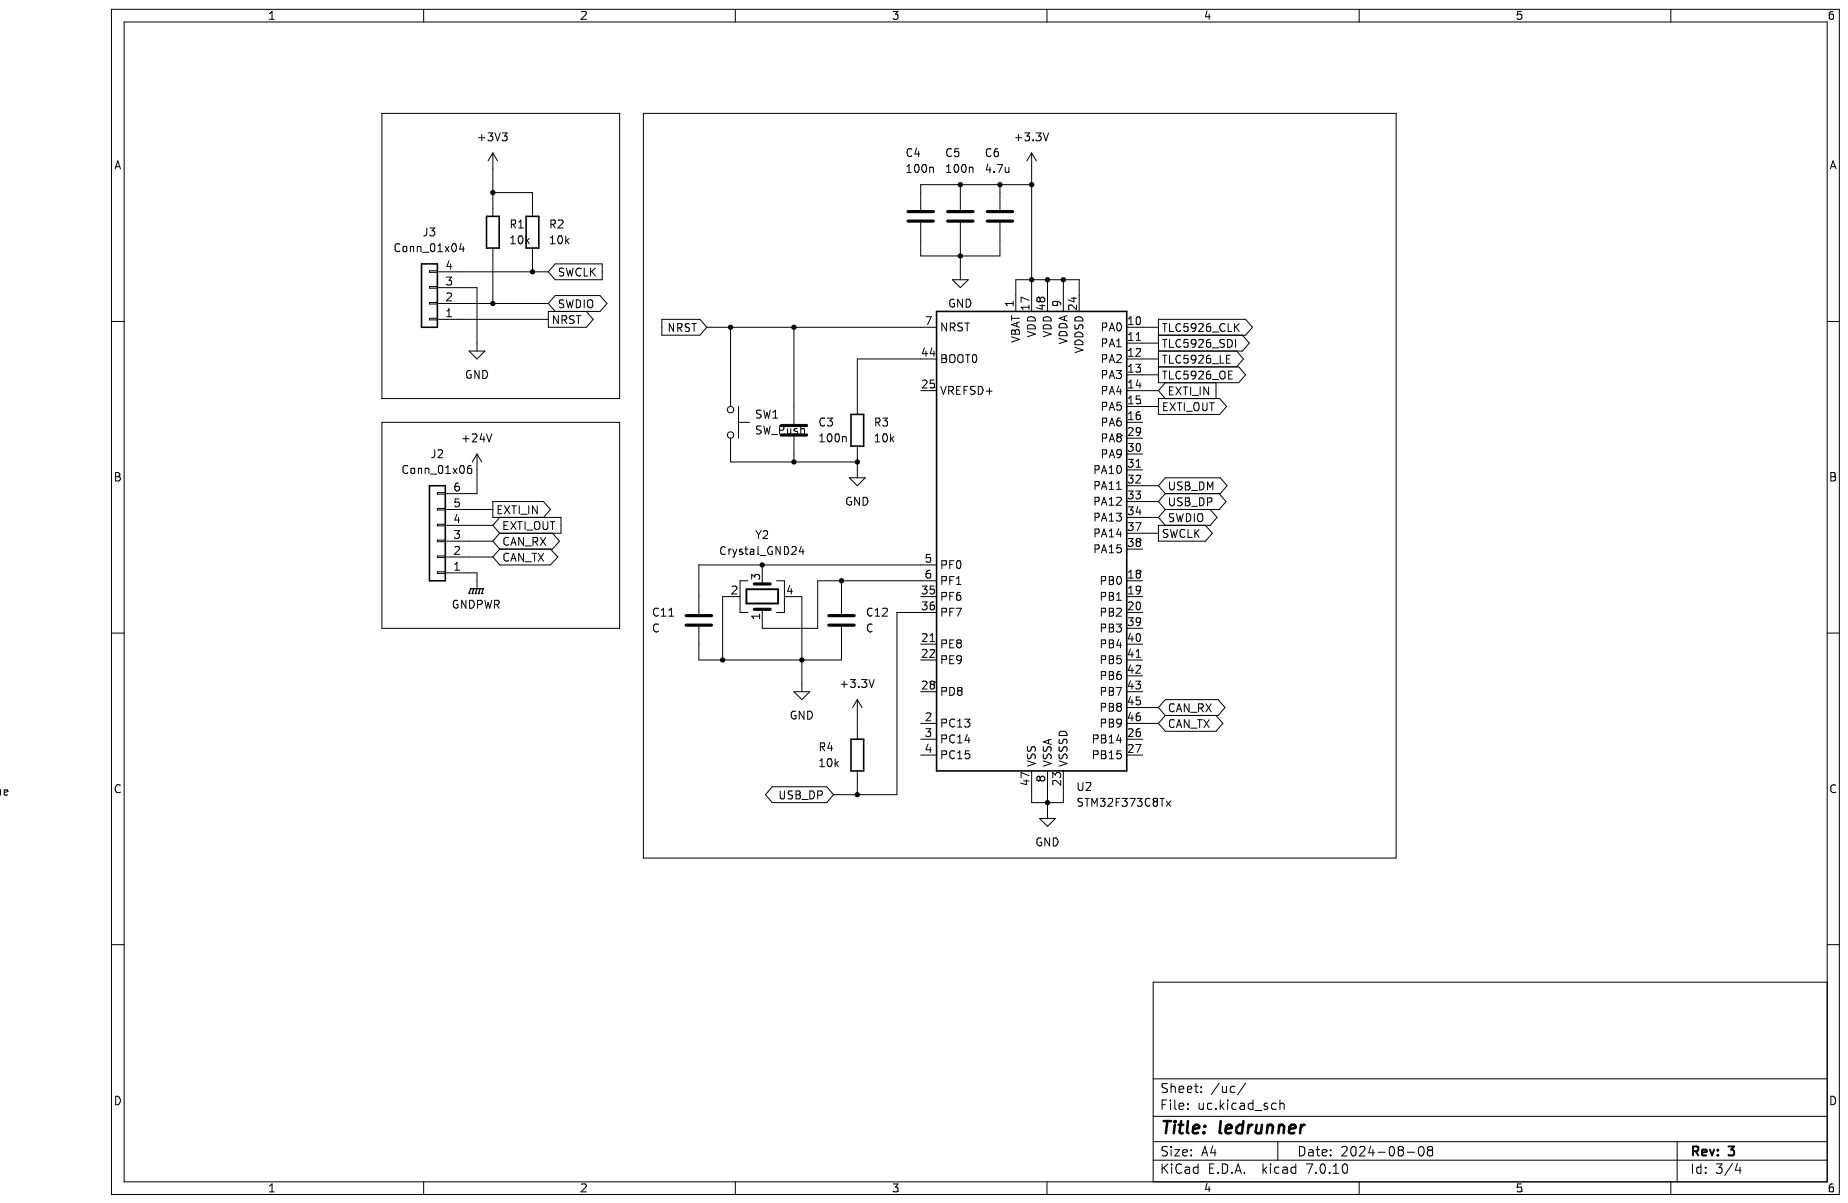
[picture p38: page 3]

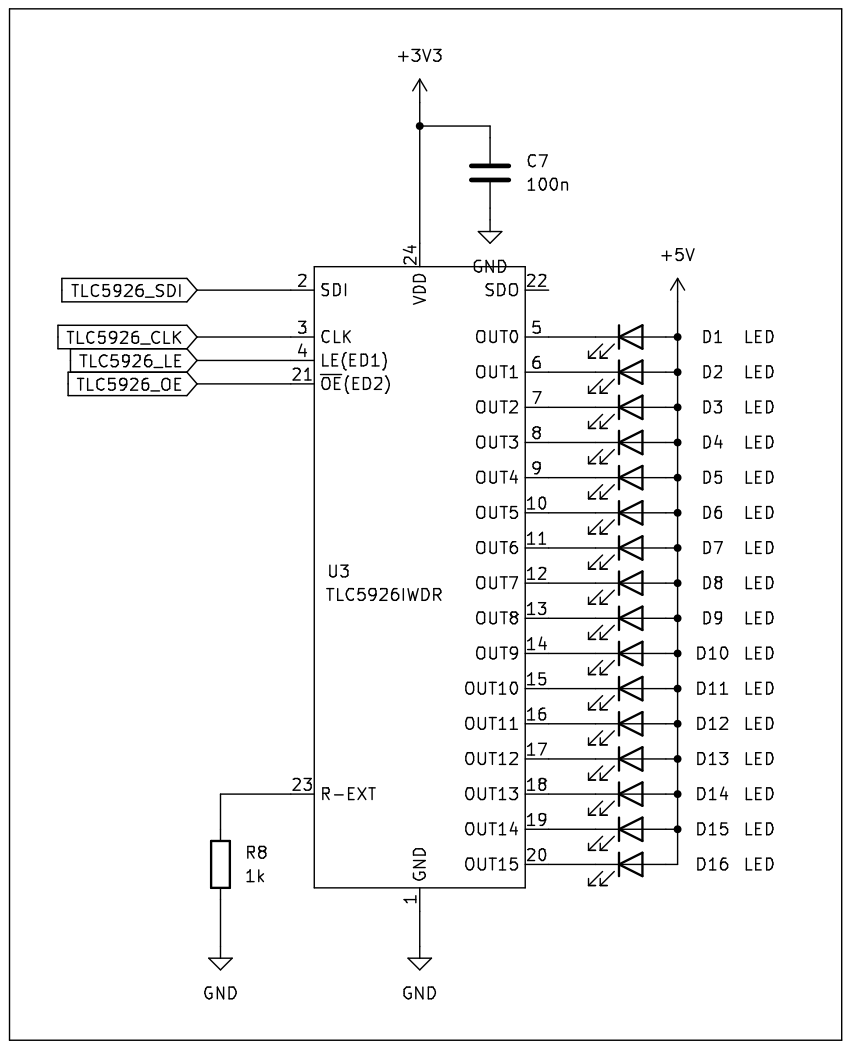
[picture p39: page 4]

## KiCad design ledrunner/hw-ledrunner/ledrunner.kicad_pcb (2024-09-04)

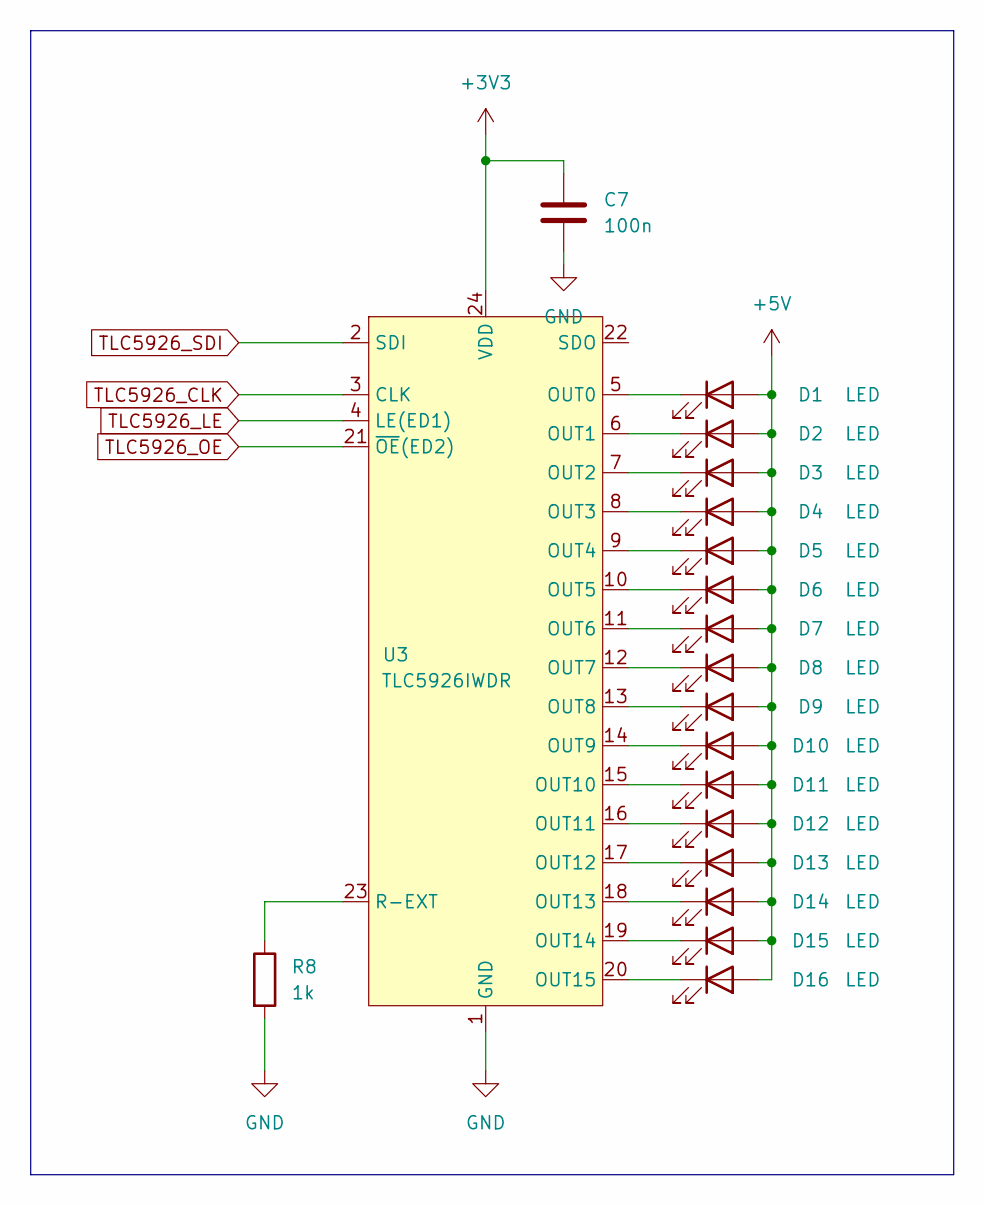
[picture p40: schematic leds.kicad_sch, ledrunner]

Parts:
C7: 100n; C_0603_1608Metric_Pad1.08x0.95mm_HandSolder
D1, D2, D3, D4, D5, D6, D7, D8, D9, D10, D11, D12, D13, D14, D15, D16: LED; LED_D5.0mm_FlatTop
R8: 1k; R_0603_1608Metric_Pad0.98x0.95mm_HandSolder
U3: TLC5926IWDR; SOIC-24W_7.5x15.4mm_P1.27mm

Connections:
+5V: D1.2 (A), D2.2 (A), D3.2 (A), D4.2 (A), D5.2 (A), D6.2 (A), D7.2 (A), D8.2 (A), D9.2 (A), D10.2 (A), D11.2 (A), D12.2 (A), D13.2 (A), D14.2 (A), D15.2 (A), D16.2 (A); also elsewhere on the board
GND: C7.2, R8.2, U3.1 (GND); also elsewhere on the board
unnamed: D1.1 (K), U3.5 (OUT0)
unnamed: D2.1 (K), U3.6 (OUT1)
unnamed: D3.1 (K), U3.7 (OUT2)
unnamed: D4.1 (K), U3.8 (OUT3)
unnamed: D5.1 (K), U3.9 (OUT4)
unnamed: D6.1 (K), U3.10 (OUT5)
unnamed: D7.1 (K), U3.11 (OUT6)
unnamed: D8.1 (K), U3.12 (OUT7)
unnamed: D9.1 (K), U3.13 (OUT8)
unnamed: D10.1 (K), U3.14 (OUT9)
unnamed: D11.1 (K), U3.15 (OUT10)
unnamed: D12.1 (K), U3.16 (OUT11)
unnamed: D13.1 (K), U3.17 (OUT12)
unnamed: D14.1 (K), U3.18 (OUT13)
unnamed: D15.1 (K), U3.19 (OUT14)
unnamed: D16.1 (K), U3.20 (OUT15)
unnamed: R8.1, U3.23 (R-EXT)
TLC5926_CLK: U3.3 (CLK); also elsewhere on the board
TLC5926_LE: U3.4 (LE(ED1)); also elsewhere on the board
TLC5926_OE: U3.21 (~OE(ED2)); also elsewhere on the board
TLC5926_SDI: U3.2 (SDI); also elsewhere on the board

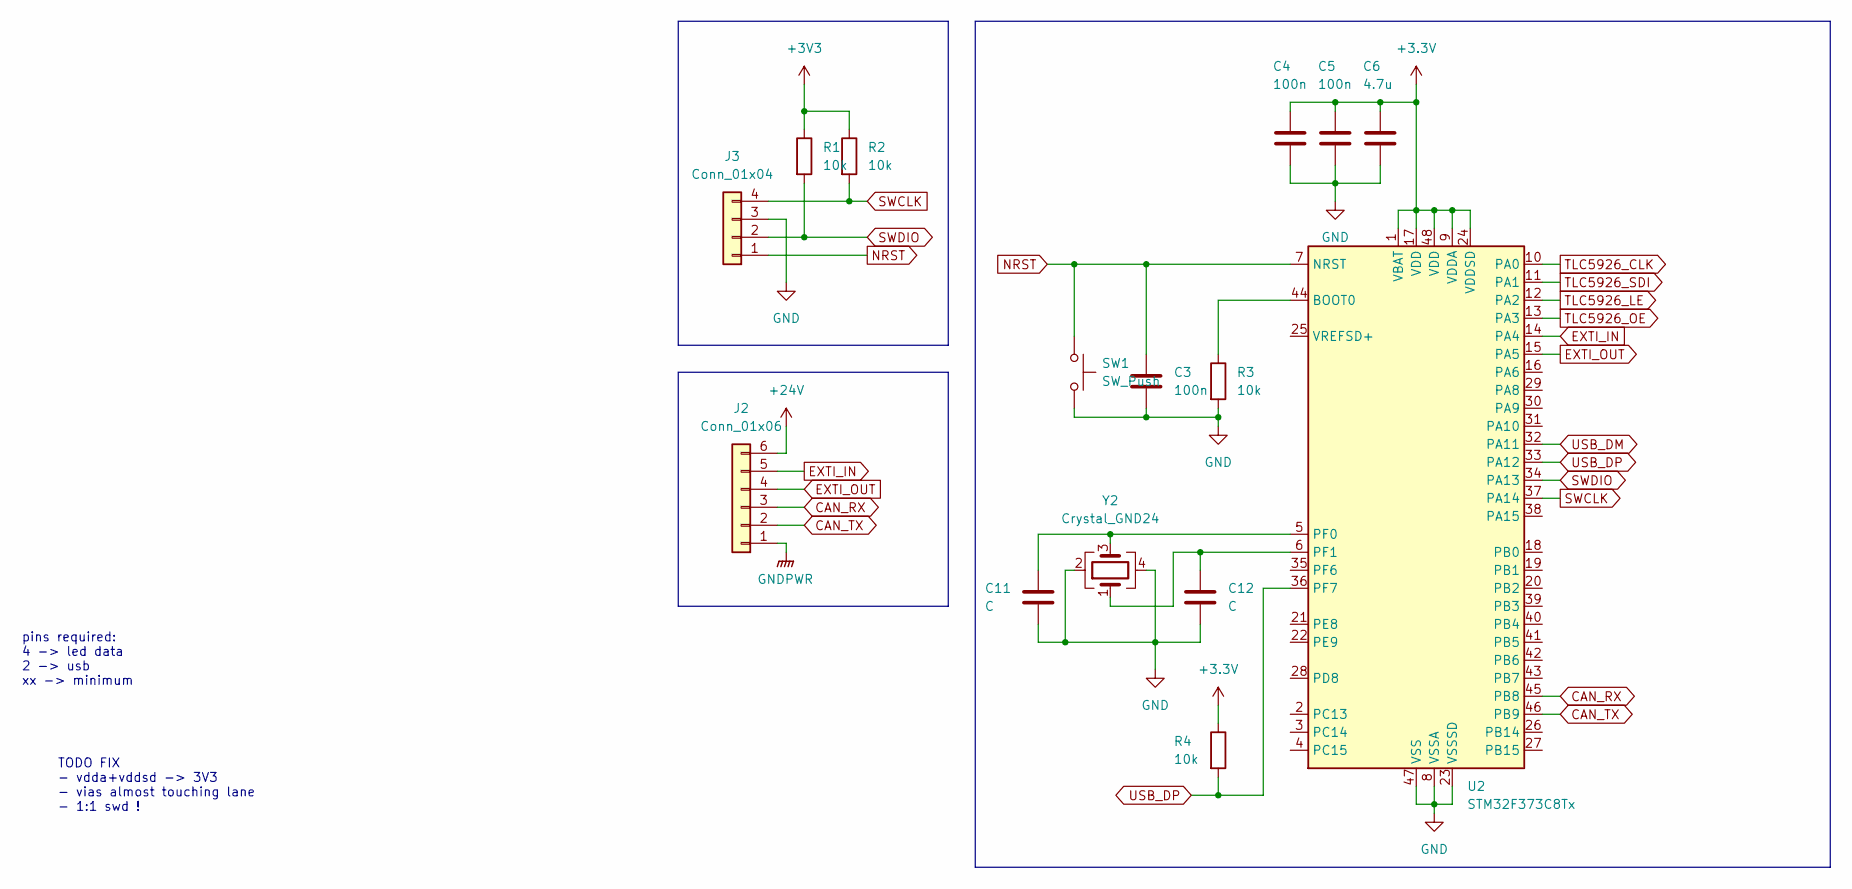
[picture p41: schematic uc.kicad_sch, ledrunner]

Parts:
C3, C4, C5: 100n; C_0603_1608Metric_Pad1.08x0.95mm_HandSolder
C6: 4.7u; C_0603_1608Metric_Pad1.08x0.95mm_HandSolder
C11, C12: C; C_0603_1608Metric_Pad1.08x0.95mm_HandSolder
J2: Conn_01x06; PinHeader_1x06_P2.54mm_Horizontal
J3: Conn_01x04; PinHeader_1x04_P2.54mm_Horizontal
R1, R2, R3, R4: 10k; R_0603_1608Metric_Pad0.98x0.95mm_HandSolder
SW1: SW_Push; SW_Push_1P1T_NO_6x6mm_H9.5mm
U2: STM32F373C8Tx; LQFP-48_7x7mm_P0.5mm
Y2: Crystal_GND24; Crystal_SMD_3225-4Pin_3.2x2.5mm

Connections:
+24V: J2.6; also elsewhere on the board
CAN_RX: J2.3, U2.45 (PB8)
CAN_TX: J2.2, U2.46 (PB9)
EXTI_IN: J2.5, U2.14 (PA4)
EXTI_OUT: J2.4, U2.15 (PA5)
GND: C3.2, C4.2, C5.2, C6.2, C11.2, C12.2, J3.3, R3.2, SW1.2, U2.8 (VSSA), U2.23 (VSSSD), U2.47 (VSS), Y2.2, Y2.4; also elsewhere on the board
GNDPWR: J2.1; also elsewhere on the board
NRST: C3.1, J3.1, SW1.1, U2.7 (NRST)
unnamed: R3.1, U2.44 (BOOT0)
unnamed: C11.1, U2.5 (PF0), Y2.3
unnamed: C12.1, U2.6 (PF1), Y2.1
SWCLK: J3.4, R2.2, U2.37 (PA14)
SWDIO: J3.2, R1.2, U2.34 (PA13)
TLC5926_CLK: U2.10 (PA0); also elsewhere on the board
TLC5926_LE: U2.12 (PA2); also elsewhere on the board
TLC5926_OE: U2.13 (PA3); also elsewhere on the board
TLC5926_SDI: U2.11 (PA1); also elsewhere on the board
USB_DM: U2.32 (PA11); also elsewhere on the board
USB_DP: R4.2, U2.33 (PA12), U2.36 (PF7); also elsewhere on the board

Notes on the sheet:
pins required: 4 -> led data 2 -> usb xx -> minimum
TODO FIX - vdda+vddsd -> 3V3 - vias almost touching lane - 1:1 swd !

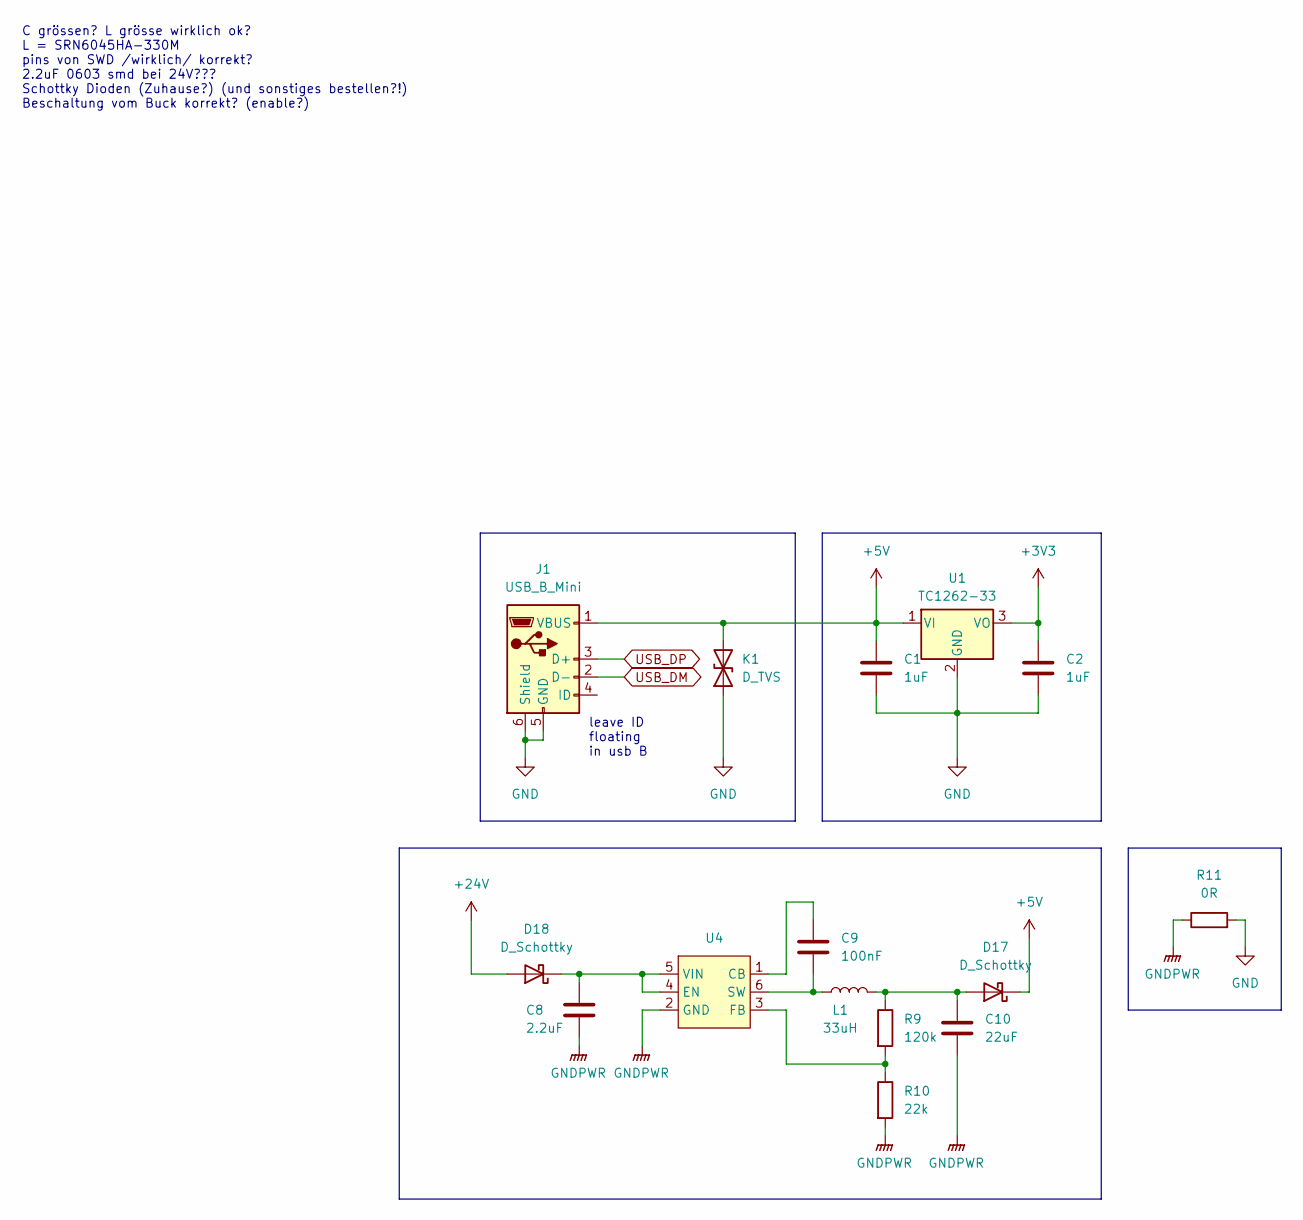
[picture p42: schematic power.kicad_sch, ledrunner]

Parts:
C1, C2: 1uF; C_0603_1608Metric_Pad1.08x0.95mm_HandSolder
C8: 2.2uF; C_0603_1608Metric_Pad1.08x0.95mm_HandSolder
C9: 100nF; C_0603_1608Metric_Pad1.08x0.95mm_HandSolder
C10: 22uF; C_Elec_5x5.4
D17, D18: D_Schottky; D_SMB
J1: USB_B_Mini; USB_Mini-B_Wuerth_65100516121_Horizontal
K1: D_TVS; D_SMB_Handsoldering
L1: 33uH; L_6.3x6.3_H3
R9: 120k; R_0603_1608Metric_Pad0.98x0.95mm_HandSolder
R10: 22k; R_0603_1608Metric_Pad0.98x0.95mm_HandSolder
R11: 0R; R_0603_1608Metric_Pad0.98x0.95mm_HandSolder
U1: TC1262-33; SOT-223-3_TabPin2
U4: SOT-23-6

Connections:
+5V: C1.1, D17.1 (K), J1.1 (VBUS), K1.2 (A2), U1.1 (VI); also elsewhere on the board
+24V: D18.2 (A); also elsewhere on the board
GND: C1.2, C2.2, J1.5 (GND), J1.6 (Shield), K1.1 (A1), R11.2, U1.2 (GND); also elsewhere on the board
GNDPWR: C8.2, C10.2, R10.2, R11.1, U4.2 (GND); also elsewhere on the board
unnamed: C10.1, D17.2 (A), L1.2, R9.1
unnamed: C8.1, D18.1 (K), U4.4 (EN), U4.5 (VIN)
unnamed: C9.1, U4.1 (CB)
unnamed: R9.2, R10.1, U4.3 (FB)
unnamed: C9.2, L1.1, U4.6 (SW)
USB_DM: J1.2 (D-); also elsewhere on the board
USB_DP: J1.3 (D+); also elsewhere on the board

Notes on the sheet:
C grössen? L grösse wirklich ok? L = SRN6045HA-330M pins von SWD /wirklich/ korrekt? 2.2uF 0603 smd bei 24V??? Schottky Dioden (Zuhause?) (und sonstiges bestellen?!) Beschaltung vom Buck korrekt? (enable?)
leave ID floating in usb B

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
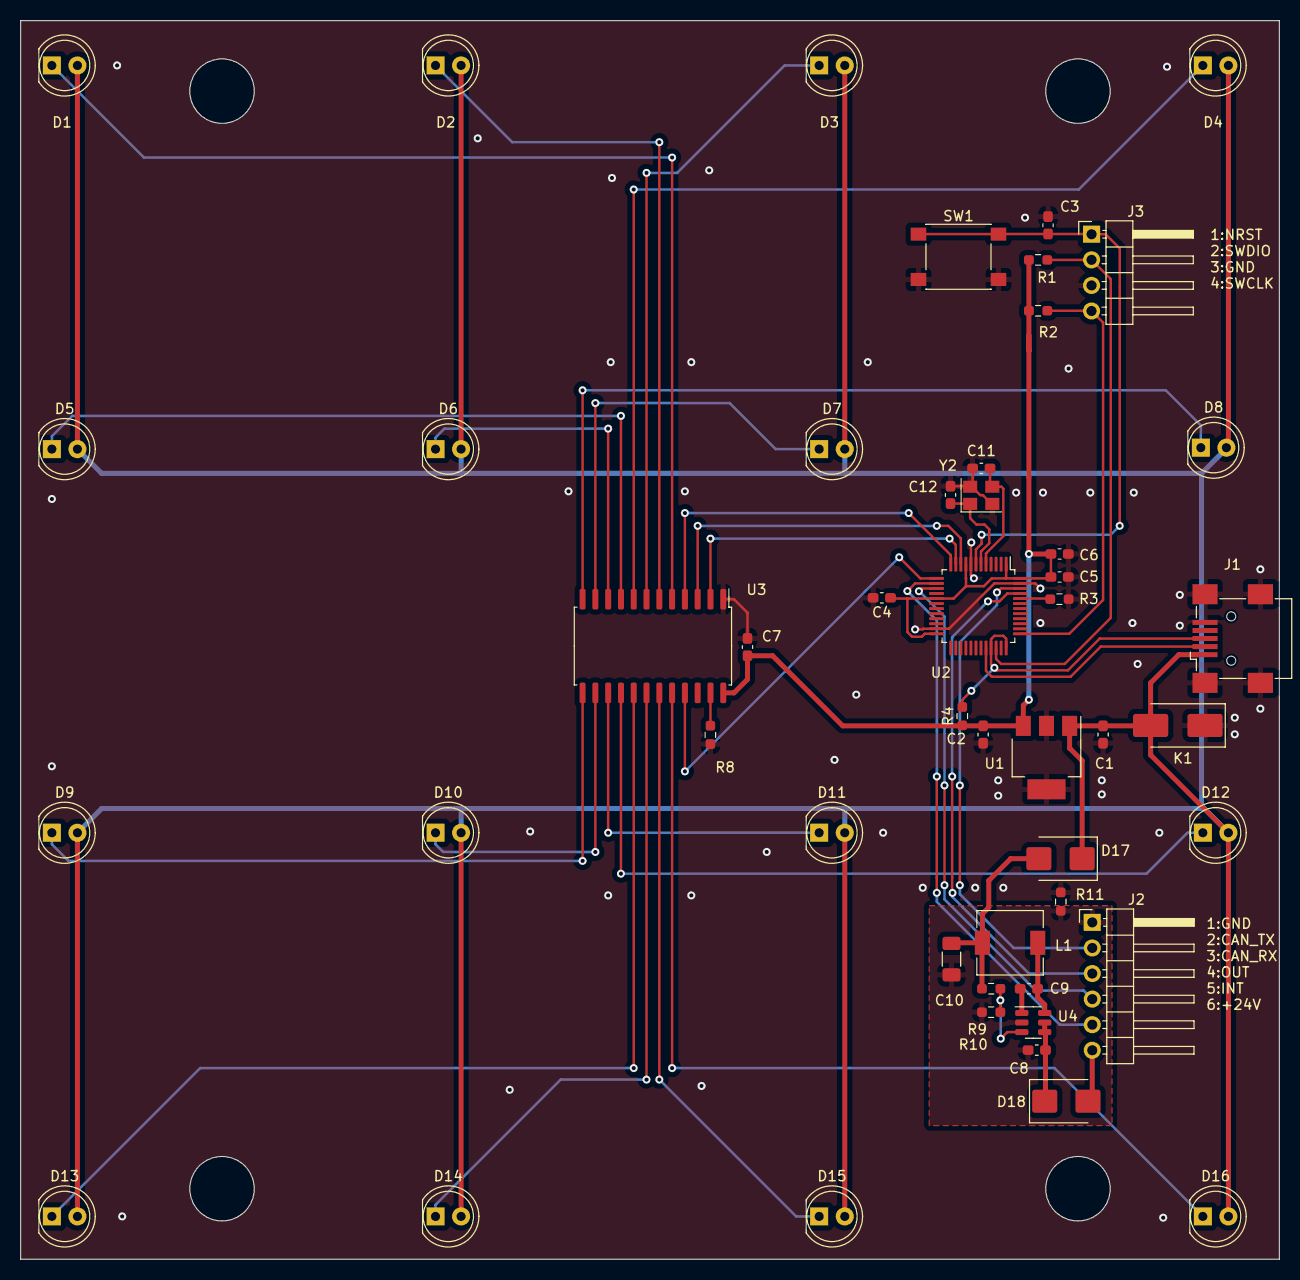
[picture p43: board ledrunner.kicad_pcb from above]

Board: 2 copper layers, 125.0 x 123.0 mm, 49 parts (0 on the bottom side), 43 nets.

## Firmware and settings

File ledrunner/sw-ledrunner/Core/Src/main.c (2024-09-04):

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
/* Includes ------------------------------------------------------------------*/
#include "main.h"
#include "usb_device.h"

/* USER CODE BEGIN Includes */
#include <stdbool.h>
#include "usbd_cdc_if.h"
#include "usbd_cdc.h"

#include "tlc.h"
#include "timer_estimator.h"
#include "cli.h"
#include "auto_mode.h"

/* USER CODE END Includes */

/* USER CODE BEGIN PTD */
/*#define MAX_LED 	16
extern bool led_data[MAX_LED];
extern int led_pwm;
extern int led_pwm_active;*/

extern USBD_HandleTypeDef hUsbDeviceFS;
extern size_t cdc_rx_buf_len;
extern char cdc_rx_buf[64];

/* USER CODE END PTD */

CAN_HandleTypeDef hcan;

TIM_HandleTypeDef htim2;

void SystemClock_Config(void);
static void MX_GPIO_Init(void);
static void MX_TIM2_Init(void);
static void MX_CAN_Init(void);
/* USER CODE BEGIN 0 */

void main_exchange(bool set, Tlc *tlc, AutoMode *auto_mode)
{
	static Tlc *tlc_stored;
	static AutoMode *auto_mode_stored;
	if(set) {
		tlc_stored = tlc;
		auto_mode_stored = auto_mode;
	} else {
		*tlc = *tlc_stored;
		*auto_mode = *auto_mode_stored;
	}
}

/* USER CODE END 0 */

/**
  * @brief  The application entry point.
  * @retval int
  */
int main(void)
{
  /* MCU Configuration--------------------------------------------------------*/

  /* Reset of all peripherals, Initializes the Flash interface and the Systick. */
  HAL_Init();

  /* Configure the system clock */
  SystemClock_Config();

  /* Initialize all configured peripherals */
  MX_GPIO_Init();
  MX_TIM2_Init();
  MX_CAN_Init();
  MX_USB_DEVICE_Init();
  /* USER CODE BEGIN 2 */

  //USBD_Clock_Config()

  //TIM2->CCR1 = 0;
  //HAL_TIM_PWM_Start(&htim2, TIM_CHANNEL_1);
  //HAL_UART_Receive_IT(&huart2, UART2_RxBuffer, 1); 	// somehow is required to start HAL_UART_RxCpltCallback

  /* tlc enters normal mode on startup by default */
  //HAL_GPIO_WritePin(TLC5926_CLK_GPIO_Port, TLC5926_CLK_Pin, GPIO_PIN_SET);
  //HAL_GPIO_WritePin(TLC5926_LE_GPIO_Port, TLC5926_LE_Pin, GPIO_PIN_SET); /* high LE = transfer to latch */
  HAL_GPIO_WritePin(TLC5926_OE_GPIO_Port, TLC5926_OE_Pin, GPIO_PIN_RESET); /* low OE = drive LEDs */
  HAL_GPIO_WritePin(TLC5926_SDI_GPIO_Port, TLC5926_SDI_Pin, GPIO_PIN_SET);

  HAL_Delay(200);
  HAL_GPIO_WritePin(USB_Reconnect_GPIO_Port, USB_Reconnect_Pin, GPIO_PIN_SET);

  //HAL_GPIO_WritePin(GPIOA, GPIO_PIN_12, GPIO_PIN_SET);
  //HAL_GPIO_WritePin(GPIOA, GPIO_PIN_12, GPIO_PIN_RESET);

  //HAL_Delay(500);


  /*
   * configure
   * 	arr		auto reload (=VAL =auto)
   * 	psc		prescaler (=VAL =auto)
   *	fps		target fps =VAL
   * 	can-bus
   * 	int-in	(=COMMAND)
   * 	int-out
   *
   * info
   * 	version
   * 	clock-freq
   * 	arr
   * 	psc
   * 	fps
   *	can-bus		list connected...
   *
   */

  Tlc tlc = {0};
  tlc_init(&tlc, TIM2, &htim2);

  AutoMode auto_mode = {0};

  Cli cli = {0};
  cli_init(&cli, &tlc, &auto_mode);

  main_exchange(true, &tlc, &cli);

  tlc_set_fps(&tlc, 60.0f);

#if 0
  TimerEstimator est = {0};
  uint32_t iter = timer_estimate(&est, 72000000, 1920);

  TIM2->PSC = 9; //(32)*base_MHZ_reciproc - 1; // 31(+1) => 1MHz counter
  TIM2->ARR = 1747; // !!! ARR @8MHz for -WHATEVER REASON- min=117 (regardless of PSC) !!!
  TIM2->CCR1 = TIM2->ARR/2;
#endif

  /* TEST for pwm */
#if 0
  TIM2->PSC = 0;
  TIM2->ARR = 150;
  TIM2->CCR1 = TIM2->ARR/2;

  tlc.running = true;
  HAL_TIM_PWM_Start(&htim2, TIM_CHANNEL_1);
  HAL_TIM_Base_Start_IT(&htim2);
#endif
  //HAL_TIM_Base_Start(&htim2);

#if 0
  int usbd_result = 0;
  do {
	  usbd_result = USBD_CDC_SetTxBuffer(&hUsbDeviceFS, "Hello\n\r", 7);
  } while(usbd_result != USBD_OK);
#endif

#if 0
  bool data[16] = {1, 1, 0, 1,
				   0, 0, 1, 0,
				   0, 0, 1, 1,
				   1, 1, 0, 1};

  tlc_set_fps(&tlc, 1.0);
  tlc_mode(&tlc, TLC_MODE_PWM);
  //memcpy(tlc.display.data, data, 16);
  tlc_run(&tlc, true);
#endif

  /* USER CODE END 2 */

  /* Infinite loop */
  /* USER CODE BEGIN WHILE */
  while (1)
  {
	  //HAL_Delay(1000);
	  //*tlc.pwm.duty_cycle += 1;
	  //if(*tlc.pwm.duty_cycle > 16) *tlc.pwm.duty_cycle = 0;

	  if(cdc_rx_buf_len) {
		  while(CDC_Transmit_FS(cdc_rx_buf, cdc_rx_buf_len) == USBD_BUSY) {};
		  //while(CDC_Transmit_FS(CSTR("\r\nFeed..\r\n")) == USBD_BUSY) {};
		  cli_feed(&cli, cdc_rx_buf, cdc_rx_buf_len);	 // TODO:RETVAL
		  //while(CDC_Transmit_FS(CSTR("Parse..\r\n")) == USBD_BUSY) {};
		  cli_parse(&cli);	// TODO:RETVAL
		  cli_process(&cli);
		  cdc_rx_buf_len = 0;
	  }
	  auto_mode_process(&auto_mode, &tlc);

#if 0
	  uint32_t tick = HAL_GetTick();
	  if(tick >= 1250) {
		  //USBD_CDC_SetTxBuffer(&hUsbDeviceFS, "Hello\n\r", 7);
		  led_pwm = -1;
		  HAL_GPIO_WritePin(TLC5926_LE_GPIO_Port, TLC5926_LE_Pin, GPIO_PIN_SET); /* high LE = transfer to latch */
		  //USBD_CDC_SetTxBuffer(&hUsbDeviceFS, "Hello\n\r", 7);
		  //USBD_CDC_TransmitPacket(&hUsbDeviceFS);
		  //HAL_Delay(1000);
	  } else if(tick >= 1000) {
		  for(int i = 0; i < MAX_LED; ++i) {
			  bool val = ((TIM2->ARR>>i)&1);
			  led_data[i] = val;
		  }
		  led_pwm = 0;
	  } else if(tick >= 750) {
		  for(int i = 0; i < MAX_LED; ++i) {
			  bool val = ((TIM2->PSC>>i)&1);
			  led_data[i] = val;
		  }
		  led_pwm = 0;
	  } else if(tick >= 500) {
		  for(int i = 0; i < MAX_LED; ++i) {
			  bool val = ((72>>i)&1);
			  led_data[i] = val;
		  }
		  led_pwm = 0;
	  } else if(tick >= 250) {
		  for(int i = 0; i < MAX_LED; ++i) {
			  bool val = ((3>>i)&1);
			  led_data[i] = val;
		  }
		  led_pwm = 0;
	  } else {
		  for(int i = 0; i < MAX_LED; ++i) {
			  bool val = 1;
			  led_data[i] = val;
		  }
		  led_pwm = 0;
	  }
#endif
    /* USER CODE END WHILE */

    /* USER CODE BEGIN 3 */
  }
  /* USER CODE END 3 */
}

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


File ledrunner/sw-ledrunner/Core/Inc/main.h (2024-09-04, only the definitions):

#define TLC5926_CLK_Pin GPIO_PIN_0
#define TLC5926_CLK_GPIO_Port GPIOA
#define TLC5926_SDI_Pin GPIO_PIN_1
#define TLC5926_SDI_GPIO_Port GPIOA
#define TLC5926_LE_Pin GPIO_PIN_2
#define TLC5926_LE_GPIO_Port GPIOA
#define TLC5926_OE_Pin GPIO_PIN_3
#define TLC5926_OE_GPIO_Port GPIOA
#define GPIO_Int_Pin GPIO_PIN_4
#define GPIO_Int_GPIO_Port GPIOA
#define GPIO_Int_EXTI_IRQn EXTI4_IRQn
#define GPIO_Out_Pin GPIO_PIN_5
#define GPIO_Out_GPIO_Port GPIOA
#define USB_Reconnect_Pin GPIO_PIN_7
#define USB_Reconnect_GPIO_Port GPIOF

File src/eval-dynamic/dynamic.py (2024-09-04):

#import math
import traceback
import cv2
import time
import numpy as np
import math
import copy
import matplotlib.pyplot as plt
from enum import Enum
from image_sequence import ImageSequence
from position_sequence import PositionSequence
from config import Config
import debug
from pathlib import Path
from plotter import plot

import threading
import queue

# https://stackoverflow.com/questions/24171064/remove-axis-label-offset-by-default
import matplotlib as mpl
mpl.rcParams['axes.formatter.useoffset'] = False


selected_points = []

def imshow(title, img):
    cv2.namedWindow(title, cv2.WINDOW_NORMAL)
    cv2.imshow(title, img)

def mouse_callback(event, x, y, flags, param):
    global selected_points
    if event==cv2.EVENT_LBUTTONDOWN:
        selected_points.append(np.array([x,y]))


class Analyzer:

    class Step(Enum):
        NONE = 0
        DETECT_ALL_ON_FIRST_BEGIN = 1
        DETECT_ALL_ON_FIRST_END = 2
        DETECT_BIT_FIELD = 3
        DETECT_ORDER = 4
        DETECT_ALL_OFF_PWM_BEGIN = 5
        DETECT_PWM_PHASES = 6
        DETECT_RIDER = 10
        QUIT = 9999

    def __init__(self, plot=True):
        # obscure stuff
        self.__step = Analyzer.Step.NONE
        self.__time_prev = None
        self.__time_next = None
        self.__time_start = None
        self.__capture = None
        self.__skip_capture = False
        self.__frame_number = 0
        self.__frame_show = None
        self.__quit = False
        self.__window_title = 'frame'
        self.__index_all_on_begin = None
        self.__index_all_on_end = None
        self.__index_order = None
        self.__index_sys_freq = None
        self.__index_arr = None
        self.__index_psc = None
        self.__index_pwm_count = None
        self.__index_rider = None
        self.__unordered_bitfields = None
        self.__wait_space = False
        self.__values_between_offstates = None
        self.__pwm_expecting_finish = False
        self.__image_sequence = ImageSequence()
        self.__position_sequence = PositionSequence()
        self.__pwm_indices = None
        self.__delta4 = None
        self.__frame_max = None
        self.exposure_expect = None
        self.__plot = plot
        # "normal" stuff
        self.sys_freq = None
        self.arr = None
        self.psc = None
        self.pwm_count = None
        self.fps_expect = None
        # other stuff
        if plot:
            cv2.namedWindow(self.__window_title, cv2.WINDOW_NORMAL)
            cv2.setMouseCallback(self.__window_title, mouse_callback)

    def load_file(self, filename, fps_expect, exposure_expect=None):
        self.input_filename = filename
        self.fps_expect = fps_expect
        if exposure_expect:
            self.exposure_expect = exposure_expect
        self.__capture = cv2.VideoCapture(filename)
        if not self.__capture.isOpened():
            raise Exception(f'Could not open: {filename}')
        self.__step = Analyzer.Step.DETECT_ALL_ON_FIRST_BEGIN
        self.__frame_max = int(self.__capture.get(cv2.CAP_PROP_FRAME_COUNT))

    def step_process(self):
        #print("STEP PROCESS...")
        if self.__quit:
            return None

        frame_next = self.__image_sequence.retrieve_at(self.__frame_number - 0)
        frame_prev = self.__image_sequence.retrieve_at(self.__frame_number - 1)
        #print(self.__step.name)
        if (frame_next is None or frame_prev is None) and self.__step != Analyzer.Step.QUIT:
            if self.__plot:
                print(f"NO FRAMES @ {self.__frame_number-0} or {self.__frame_number-1} ({frame_next is None}, {frame_prev is None})")
            return

        elif self.__step == Analyzer.Step.DETECT_ALL_ON_FIRST_BEGIN:
            self.__wait_space = False
            diff = cv2.subtract(frame_next, frame_prev)
            self.__frame_show = diff
            self.__frame_show = frame_next
            std = np.std(diff)
            if std >= Config.DETECT_ALL_ON_FIRST_THRESHOLD:
                self.__index_all_on_begin = self.__frame_number
                self.__step = Analyzer.Step.DETECT_ALL_ON_FIRST_END
                #self.__wait_space = True
                if self.__plot:
                    print('DETECT_ALL_ON_BEGIN    ok')

        elif self.__step == Analyzer.Step.DETECT_ALL_ON_FIRST_END:
            self.__wait_space = False
            diff = cv2.subtract(frame_prev, frame_next)
            self.__frame_show = diff
            std = np.std(diff)
            if std >= Config.DETECT_ALL_ON_FIRST_END_THRESOLD:
                self.__index_all_on_end = self.__frame_number
                #self.__wait_space = True
                if self.__plot:
                    print('DETECT_ALL_ON_END    ok')

                index_delta = self.__index_all_on_end - self.__index_all_on_begin
                index_dark = self.__index_all_on_begin - index_delta / 2
                index_bright = self.__index_all_on_begin + index_delta / 2
                self.__index_order = index_delta + index_bright
                if self.__plot:
                    print(f'    => {index_dark} index dark\n'
                          f'    => {index_bright} index bright\n'
                          f'    => {self.__index_order} index order\n'
                          )

                try:
                    self.__unordered_bitfields, self.__ratio_scale, self.__angles = self.__image_sequence.detect_bit_field(index_dark, index_bright, int(round(index_delta / 4)))

                    # next step
                    self.__step = Analyzer.Step.DETECT_ORDER
                    self.__skip_capture = True
                except Exception:
                    self.__step = Analyzer.Step.DETECT_ALL_ON_FIRST_BEGIN
                    self.__frame_number = self.__index_all_on_begin


        elif self.__step == Analyzer.Step.DETECT_ORDER:
            self.__wait_space = False
            if self.__frame_number >= self.__index_order:
                if self.__plot:
                    print('DETECT_ORDER     ok')

                state = self.__image_sequence.retrieve_at(self.__index_order)
                self.__frame_show = state.copy()

                def find_orientation_x(values_arg):
                    values = values_arg
                    index = None
                    rotate = False
                    compare = Config.LED_PATTERN_ORDER[Config.NUM_LEDS_EDGE - 1]
                    # get x orientation
                    for i, line in enumerate(values):
                        if (line == compare).all():
                            if index is None:
                                index = i
                            else:
                                raise Exception("Should not find pattern ONE twice or more!")
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

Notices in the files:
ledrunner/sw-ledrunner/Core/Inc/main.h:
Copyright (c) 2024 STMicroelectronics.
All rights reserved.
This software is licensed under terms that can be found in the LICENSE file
